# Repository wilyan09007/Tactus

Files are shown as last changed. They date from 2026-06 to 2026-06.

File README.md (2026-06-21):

# 🎸 Tactus

**A Deaf-accessible guitar-coaching wearable.** From a webcam + a mic, Tactus recovers *what you played, where, with which finger, and how cleanly you fretted it* — by fusing vision and audio through a learned physical model — then gives you **one precise correction you feel on your body and see on your hand.**

> Built for the **UC Berkeley AI Hackathon 2026 (June 20–22)**. Team of 4. Working name **Tactus** (*touch* + the conductor's *pulse*).
>
> 📌 **Canonical source of truth: [`truth.md`](truth.md).** If any doc disagrees with it, `truth.md` wins.

---

## The 30-second version
- **Problem.** Learning guitar is a hear-and-correct loop: play → hear the buzz / wrong note → fix. Deaf and hard-of-hearing players are locked out of that loop (~466M people have disabling hearing loss, WHO).
- **Tactus — two modes on one engine:**
  - **LEARN** — "Rocksmith for Deaf players." Feel the target song on your body, play it on a real guitar, and on any mistake the system rewinds, replays the correct haptics vs. yours, and shows the physical fix — Claude vision highlights the wrong finger.
  - **PLAY** — pick up the guitar and get real-time "flat / sharp / in tune / on the beat" by feel.
- **Where the AI is.** The hard, unsolved part is reading an *occluded* fretting hand and a *cause-blind* buzz from a webcam + mic. The ML lives exactly there; everything downstream is a deterministic, measurable signal→vibration transform (no AI-invented "score"). That split is the rigor.
- **The one correction.** Three axes: **wrong note · wrong duration · pressure** (too-light vs good; "too hard" surfaces as a sharp/choked pitch fault). Each is a measured signal, cross-checked across vision + audio.

## The rig (as-built — full detail in [`truth.md`](truth.md))
```
LAPTOP (M4 Pro) ──USB──► 2× Vantec NBA-200U (USB→8 ch; V3 spare)
                            └► 6× SK473 PAM8403 stereo amp boards (gutted)
                                 └► 12× KHD 3 Ω/5 W drivers (de-housed) on the body
                                      = 12 channels: 6 back (strings) + 6 torso (fret-zones)
```
- **Software split (locked):** the **browser** owns camera + MediaPipe + ArUco + AR + viz; a **Python** process owns mic + F0 + the fusion model + 12-ch haptic output; they sync over one localhost WebSocket (vision features flow browser→Python, timestamped).
- **Power:** wall (10-port hub) for the judged run, or cordless (Anker 737). Only ~2–3 channels fire at once (sequential strum sweep), so real peak is ~2–3 W.

## Docs map
| Doc | What's in it |
|---|---|
| **[`truth.md`](truth.md)** | ⭐ The canonical source of truth — direction + all hardware (parts, dimensions, cost, use) |
| [`docs/00-start-here.md`](docs/00-start-here.md) | On-ramp + build-tonight TL;DR |
| [`docs/01-bill-of-materials.md`](docs/01-bill-of-materials.md) | The as-purchased BOM (SKUs, qty, spares) |
| [`docs/02-system-architecture.md`](docs/02-system-architecture.md) · [`03-power.md`](docs/03-power.md) | System chain + the chord-safety power math |
| [`docs/04-soldering-guide.md`](docs/04-soldering-guide.md) · [`05-wiring-map.md`](docs/05-wiring-map.md) · [`06-safety.md`](docs/06-safety.md) · [`09-assembly-checklist.md`](docs/09-assembly-checklist.md) | Build: solder order, channel-by-channel wiring, safety, assembly gates |
| [`docs/07-haptic-encoding.md`](docs/07-haptic-encoding.md) · [`18-tuning-and-calibration.md`](docs/18-tuning-and-calibration.md) · [`21-chord-and-sustain-rendering.md`](docs/21-chord-and-sustain-rendering.md) | How notes / chords / sustain become vibration + on-body tuning |
| [`docs/08-software-architecture.md`](docs/08-software-architecture.md) · [`13_LEARN_WEB_AND_VISUALIZATION.md`](docs/13_LEARN_WEB_AND_VISUALIZATION.md) | The engine + the browser↔engine WebSocket contract |
| [`docs/17-ai-rigor.md`](docs/17-ai-rigor.md) · [`20-aiml-training-design.md`](docs/20-aiml-training-design.md) · [`20-eng-review.md`](docs/20-eng-review.md) · [`23-data-and-cluster-semantics.md`](docs/23-data-and-cluster-semantics.md) | The AI core: fusion, the buzz inverse, the separability study, data + training |
| [`docs/22-interface-ar-and-correction.md`](docs/22-interface-ar-and-correction.md) | The interface: live AR play + the 2D correction view |
| [`docs/10-design-decisions.md`](docs/10-design-decisions.md) · [`11-ai-and-pitch.md`](docs/11-ai-and-pitch.md) · [`12-perception-references.md`](docs/12-perception-references.md) · [`13-open-questions.md`](docs/13-open-questions.md) · [`15-build-refinements.md`](docs/15-build-refinements.md) | Decisions, perception science, open items, the as-built teardown log |
| [`docs/19-sponsors-refined.md`](docs/19-sponsors-refined.md) | Sponsor / prize alignment |
| `docs/REF_*.md` (ml · psychophysics · sponsors) | Cited research briefs (background) |
| [`cad/`](cad/) | Printable enclosure + actuator coupling pucks (FlashForge 5M) |
| [`config/channel_map.json`](config/channel_map.json) | Machine-readable 12-channel routing (wiring source of truth) |
| [`CHANGELOG.md`](CHANGELOG.md) | Chronological history (incl. the pre-pivot era) |

---
*Pivoted from an earlier multi-pillar "music for the Deaf" concept. The abandoned Pi / ESP32 / 16-channel / 3-pillar docs were removed from this repo (recoverable from git history). The current product is **LEARN + PLAY guitar coaching** — see [`truth.md`](truth.md).*

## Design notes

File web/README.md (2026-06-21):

# Tactus — web

The **product UI** is **[`glow.html`](glow.html)** — the live fret-glow LEARN
interface. `index.html` just redirects to it, so opening `/` opens the real thing.

## Run

```bash
cd web
python3 -m http.server 8000
# open http://localhost:8000/   (redirects to glow.html)
```

Allow the camera, then **calibrate**: drag the 4 corner handles onto your real
fretboard. The glow markers then sit on the real strings/frets.

## What glow.html is

The canonical LEARN view. Notes are annotated **on the real neck** over the
webcam — no synth, render-only (right for a Deaf-focused app).

- **Per-string 6-hue palette** (CVD-aware) — each string is its own colour;
  nut labels back it up for accessibility.
- **ADSR brightness envelope** — a marker washes in pale when far, deepens to
  full saturation at the strum, then releases. Approach-frame shrinks to meet
  the marker = strum now; pop burst on the beat.
- **4-corner bilinear neck grid** — draggable handles map the grid to your neck
  (equal-temperament fret spacing, `2^(-n/12)`).
- **alphaTab real tab** on the left — actual notation/tab rendered from one
  `SONG` source that also builds the glow chart, so left and right are the same
  song, locked to one master clock. CDN-blocked → falls back to a chord-row list.

## Helpers (prepared, not yet wired)

- `alphatab-loader.js` — parse a GuitarPro/MusicXML file → Tactus chart, headless
  (no DOM/synth). For driving glow from real song files.
- `aruco-poselock.js` — js-aruco2 marker pose-lock to **auto**-align the neck grid
  (drops the manual 4-corner calibration). The next AR layer.

## `_prototypes/`

Earlier exploration UIs, **kept for reference only — not the product**:
`learn-dashboard-mock.html` (the old black 14-channel body-map mock),
`beatsaber.html` (notes-fly-in highway), `ar.html` (chord-field depth view).
Do not build on these — glow.html is the one.

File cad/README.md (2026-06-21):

# CAD — the printed enclosure + body-coupling pucks (FlashForge Adventurer 5M)

Everything printed for the **12-channel, no-solder** rig in [`truth.md`](../truth.md) (canonical). One **enclosure** that houses the audio source + amp boards + power, and the **coupling pucks** that turn each de-housed **Ø52 mm SK473 KHD driver** into a body tactor.

> ⚙️ **Render note:** the installed **OpenSCAD is x86 and will not run on this arm64 Mac** (no Rosetta). So the print-ready parts are generated **headless with manifold3d** (the exact-boolean kernel modern OpenSCAD uses) via Python — no GUI. The `.scad` files remain the human-readable sources; the OpenSCAD-only parts (§ "Reference parts") need an OpenSCAD machine to re-render.

---

## ★ PRINT THIS — the verified print-ready set

All four are **single watertight bodies, no supports, fit the 220³ bed.** Drop the STLs straight into the slicer.

| File | Size (mm) | Qty | Orient | Material | Time |
|---|---|---|---|---|---|
| **`tactus_enclosure_plate.stl`** — base + lid, **ONE print** | base 175×97×63, lid 175×97×8 (plate 175×202) | 1 | as-exported, support-free | PETG | ~7–10 h |
| `actuator_cup.stl` (Ø52 driver) | 75.4 × 57.4 × 30.4 | ~14 | open-side up | PETG/TPU | ~14 min |
| `actuator_button.stl` | 14 × 14 × 9 | ~14 | flat-side down | PETG/TPU | ~6 min |

Common: 0.2 mm layer · 3 walls · 4 top/bottom · 15–20 % gyroid · **supports NONE** · brim 5 mm (enclosure) / skirt (pucks) · PETG 235/80 °C.

**The new box** — rounded, one compartment, **TACTUS** engraved big + bold (Arial Black) on the lid; base + lid print side-by-side as one plate:
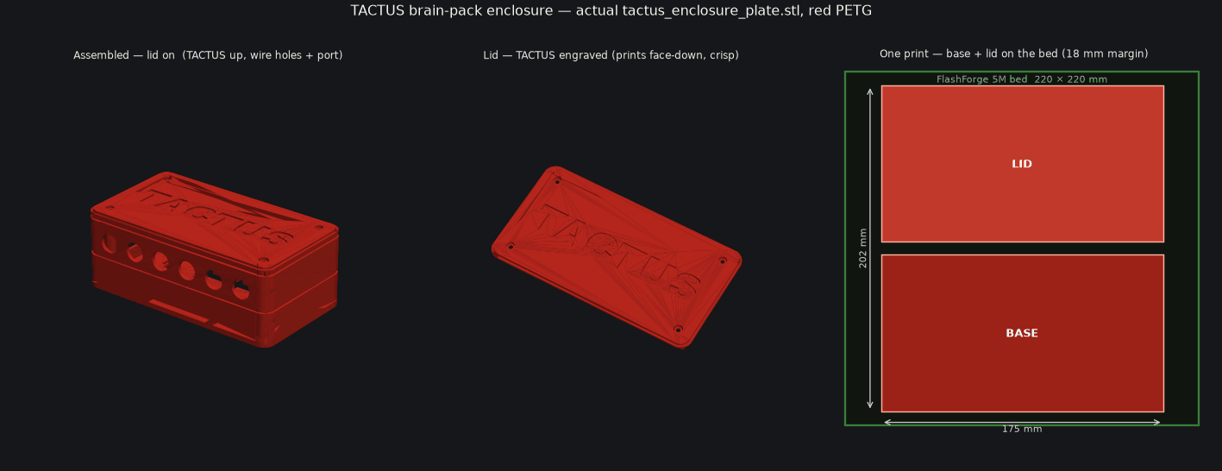
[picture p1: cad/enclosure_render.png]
TACTUS enclosure — assembled box + lid, red PETG


### What lives inside (per truth.md §3 — laptop is the brain, no Pi)
| Bay | Holds |
|---|---|
| One compartment (lidded) | **2× Vantec NBA-200U** (100×58×26; the 6 SK473 **audio jacks** plug in here) + **1× 10-port hub** (the 6 SK473 **USB** leads + 2 Vantec data leads plug in here). **No Pi, no ESP32, no boards** — the SK473 amp+driver units are on the **vest**; their 12 cables enter the wall holes. |
| Power | **Mode A** = the 10-port hub (in the box). **Mode B** = **Anker 737** (155.7×54.6×49.5) — has its own plug, so it velcros **outside** the box / on the belt. |

> **Why this enclosure (not `tactus_box`):** truth.md names `tactus_box` for the enclosure, but its pre-rendered STL is **non-watertight (8 disconnected chunks)** and **can't be re-rendered here** (OpenSCAD won't run). `tactus_enclosure` is the **manifold3d** equivalent — same contents, **verified watertight single body**, integrated power bay (so no separate `tactus_power_cradle`), re-renders headless. Use it for the print.

---

## Render → STL (headless, no OpenSCAD)
```bash
/tmp/tactuscad/bin/python cad/tactus_enclosure.py   # → _base.stl, _lid.stl, and _plate.stl (the ONE-print file) + bed-fit assert
/tmp/tactuscad/bin/python cad/_puck_render.py       # → actuator_cup.stl + actuator_button.stl (at spk_dia=52)
```
The venv `/tmp/tactuscad` has `trimesh` + `manifold3d`. `tactus_enclosure.py` **errors out if any feature would print disconnected** — a single watertight body is guaranteed or the build fails.

## ⚠️ The one open dimension — the driver Ø
- **Ø52 mm is web-verified** (OEM Havit HV-SK473, literal "Φ52 mm*2" from two independent retailers; zero dissenting sources). The puck bore is **Ø52.6** (52 + 0.6 fit gap) and `spk_dia=52` is set across `actuator_puck.scad`, `tactus_node_mount.scad`, `tactus_chest_plate.scad`.
- **Caliper the physical driver before the full run** (truth.md §8 #1): published "52 mm" is the nominal *frame* OD (what the cup grips), but no source separates cone vs frame, and driver *depth* / magnet Ø are unpublished (puck uses a generous `spk_depth=27`). **Print one cup, drop the driver in, confirm the grip, then batch the rest.**

## Reference parts (OpenSCAD-only — need an OpenSCAD machine to re-render)
- `tactus_box.scad` / `tactus_power_cradle.scad` — truth.md's original split enclosure. Superseded for printing by `tactus_enclosure` (above). Their STLs are non-watertight; don't print them.
- `tactus_node_mount.scad` + `tactus_socket.scad` / `tactus_chest_plate.scad` — the **adjustable** body-mount alternative to the puck (split-clamp collar + depth micro-adjust). `drv_dia` is set to the verified **52 mm**; the pre-rendered STLs are still at the old 58 mm placeholder — **re-render in OpenSCAD** before printing these. The `actuator_puck` (above) is the working coupler if you don't need the adjustable mount.

## Slicing (FlashForge Adventurer 5M — open-frame, web-confirmed)
PETG for the enclosure (heat tolerance near the warm boards + bank; tougher bosses); PLA fine for a fast start. Pucks: PETG or TPU (TPU = softer skin contact). 0.2 mm · 3 walls · 4 top/bottom · 15–20 % gyroid · **no supports** · brim 5 mm on the base. Queue base / lid / a tray of pucks across printers — all hands-off.

## Assembly (no soldering — truth.md §3, docs/09)
1. Self-tap the 4 lid bosses with the M3 screw (PETG self-taps).
2. Lash the **2 Vantec + 6 SK473 boards** to the floor zip-tie grid over foam. Each board: 3.5 mm plug → a Vantec jack; USB-A → the hub.
3. De-house each Ø52 mm driver (leads stay on the board — no solder), seat in a cup, glue a button to the dust cap, run the lead out the comb; strain-relieve both ends.
4. Drop the Anker/hub into the open back bay → velcro through the floor strap slots → screen out the back.
5. Lid on, 4× M3. *(Optional wear: waistband through the 2 floor belt slots, or zip-tie via the 4 corner lash holes.)*

## ArUco marker (vision) — OPTIONAL validation rig only
Registration is **markerless** (the 12-TET fret-law homography, `software/ai/vision/fretboard.py` — see `truth.md §3.8`, `docs/25`); **you do not need a marker to record or to run the pipeline.** The marker is kept only as an OPTIONAL offline ground-truth validator. If you do print one: generate it with `python3 cad/aruco/generate_marker.py` (produces `cad/aruco/marker_4x4_50_id0.png` + a print-at-100% sheet, 4×4_50 id 0), keep it **dead flat (never folded)**, and tape it **coplanar with the fretboard near the nut/neck — NOT the angled headstock** (the headstock tilts ~15° off the fretboard plane → a worse homography).

## Parameters you'll most likely touch
- `tactus_enclosure.py`: `IX` / `IY` / `IZ` (compartment size), `PLATE_GAP` (base↔lid spacing on the one-print bed).
- `actuator_puck.scad` (+ `_puck_render.py`): `spk_dia`, `spk_depth` (your measured driver), `btn_dome_h` (skin poke).
- `tactus_node_mount.scad` / `tactus_chest_plate.scad`: `drv_dia` / `drv_depth`, `torso_r`.

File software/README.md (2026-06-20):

# software

Two halves, both on the laptop. See [../docs/08-software-architecture.md](../docs/08-software-architecture.md).

```
software/
  ai/       transcription (basic-pitch), vision (mediapipe + ArUco), fusion, LLM coach
  haptic/   encoder (note -> channel), synth (pulse), alsa_out (multichannel write)
```

## Bring-up order
1. `aplay -l` → note the 3 Vantec card indices; fill `card_alsa` in [../config/channel_map.json](../config/channel_map.json).
2. `speaker-test -c8 -Dhw:CARD,0` on each Vantec → confirm all 8 channels reach the 4 jacks.
3. `haptic/` smoke test: play a known (string, fret) → correct body site buzzes.
4. `ai/` smoke test: webcam + mic → transcription + fretboard overlay.
5. Wire the coach loop on one phrase.

## Install
```
python -m venv .venv && source .venv/bin/activate
pip install -r requirements.txt
```

Real-time note: `basic-pitch` is near-real-time per phrase, not per-note. For live coaching use a known target song (compare against its reference) — see the "any song" section in the architecture doc.

## What to build first (MVP slices)
Build in this order for the fastest working demo — full reasoning + track alignment in [../docs/11-ai-and-pitch.md](../docs/11-ai-and-pitch.md):
1. mono note detection (audio) + MediaPipe overlay + correct/incorrect
2. haptic render of the note on the body + rule-based "wrong note / too quiet"
3. LLM phrase-level coaching
4. then: chords/polyphony, audio↔vision cross-check, buzz→"press harder", placement color

Honest-scoping rules (don't over-claim): placement is **vs the fret-wire (coarse)**, pressure is **adequacy from timbre** (no sensor), polyphony degrades on dense playing. See [../docs/13-open-questions.md](../docs/13-open-questions.md) for known limitations.

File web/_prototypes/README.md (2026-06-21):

# Archived prototypes — NOT the product UI

These are earlier exploration passes, kept only for reference. **The real Tactus
LEARN interface is [`../glow.html`](../glow.html)** (open `/` → it redirects there).
Do not build on or ship these.

| File | What it was | Why archived |
|---|---|---|
| `learn-dashboard-mock.html` | Black 14-channel dashboard: top-bar pills, body-map (6 chest + 6 forearm), note highway, 3-fix correction panel. Runnable mock of the WebSocket `frame`/`note`/`error`/`reference` contract (docs/16). | Uniform-blue strings, no AR-on-real-neck. Superseded by glow.html. |
| `beatsaber.html` | three.js Beat-Saber highway — note blades fly down the string lanes toward a "now" bar, composited over the webcam. | Single-hue (gold), depth-approach not on-the-real-neck. Concept lives in docs/22. |
| `ar.html` | Chord-field — fretboard faces the camera, blades light up in the chord shape, depth = hold length. | Single-hue, face-on grid. Exploration only. |

What made glow.html win: **per-string colour + on-the-real-neck annotation +
silent render-only alphaTab tab**, all on the live camera. See `../README.md`.

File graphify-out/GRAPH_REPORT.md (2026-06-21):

# Graph Report - tactus  (2026-06-21)

## Corpus Check
- 68 files · ~105,469 words
- Verdict: corpus is large enough that graph structure adds value.

## Summary
- 1060 nodes · 1481 edges · 93 communities (90 shown, 3 thin omitted)
- Extraction: 94% EXTRACTED · 6% INFERRED · 0% AMBIGUOUS · INFERRED: 82 edges (avg confidence: 0.83)
- Token cost: 0 input · 0 output

## Graph Freshness
- Built from commit: `01b1d406`
- Run `git rev-parse HEAD` and compare to check if the graph is stale.
- Run `graphify update .` after code changes (no API cost).

## Community Hubs (Navigation)
- [[_COMMUNITY_AI Audit Report Generator|AI Audit Report Generator]]
- [[_COMMUNITY_SpeakerActuator Check Harness|Speaker/Actuator Check Harness]]
- [[_COMMUNITY_Fretboard Vision Registration|Fretboard Vision Registration]]
- [[_COMMUNITY_Audio Feature Extraction|Audio Feature Extraction]]
- [[_COMMUNITY_AI Rigor & Perception Docs|AI Rigor & Perception Docs]]
- [[_COMMUNITY_Rendering & Sponsor Briefs|Rendering & Sponsor Briefs]]
- [[_COMMUNITY_Feature Collapse  Fisher Analysis|Feature Collapse / Fisher Analysis]]
- [[_COMMUNITY_Event Segmentation|Event Segmentation]]
- [[_COMMUNITY_Vision Feature Extraction|Vision Feature Extraction]]
- [[_COMMUNITY_Channel Map & Body Diagrams|Channel Map & Body Diagrams]]
- [[_COMMUNITY_Enclosure CAD Model|Enclosure CAD Model]]
- [[_COMMUNITY_Learn Loop & Correction Engine|Learn Loop & Correction Engine]]
- [[_COMMUNITY_Data & Feature Contracts|Data & Feature Contracts]]
- [[_COMMUNITY_Pipeline Schema Helpers|Pipeline Schema Helpers]]
- [[_COMMUNITY_AR Play & Calibration UI|AR Play & Calibration UI]]
- [[_COMMUNITY_Actuator Hardware & Coupling|Actuator Hardware & Coupling]]
- [[_COMMUNITY_Channel Map Config|Channel Map Config]]
- [[_COMMUNITY_AmpBOM & Safety Hardware|Amp/BOM & Safety Hardware]]
- [[_COMMUNITY_Buzz-Inverse & Experiment Plan|Buzz-Inverse & Experiment Plan]]
- [[_COMMUNITY_Enclosure Render (Preview)|Enclosure Render (Preview)]]
- [[_COMMUNITY_Brain-Pack Enclosure Print|Brain-Pack Enclosure Print]]
- [[_COMMUNITY_Capture HTTP Server|Capture HTTP Server]]
- [[_COMMUNITY_Capture Web App|Capture Web App]]
- [[_COMMUNITY_Puck Coupler CAD|Puck Coupler CAD]]
- [[_COMMUNITY_Training Design & Semantics|Training Design & Semantics]]
- [[_COMMUNITY_MLDSP Methods Brief|ML/DSP Methods Brief]]
- [[_COMMUNITY_Canonical Docs (truth.md)|Canonical Docs (truth.md)]]
- [[_COMMUNITY_Power Budget & Modes|Power Budget & Modes]]
- [[_COMMUNITY_Calibration HTTP Server|Calibration HTTP Server]]
- [[_COMMUNITY_Data Collection Protocol|Data Collection Protocol]]
- [[_COMMUNITY_Project History & Haptic Render|Project History & Haptic Render]]
- [[_COMMUNITY_Engine Pipeline (Fusion)|Engine Pipeline (Fusion)]]
- [[_COMMUNITY_Demo Data Generator|Demo Data Generator]]
- [[_COMMUNITY_ArUco Pose-Lock Filter|ArUco Pose-Lock Filter]]
- [[_COMMUNITY_Separability & Cluster Viz|Separability & Cluster Viz]]
- [[_COMMUNITY_Audit Tests|Audit Tests]]
- [[_COMMUNITY_Audio Feature Tests|Audio Feature Tests]]
- [[_COMMUNITY_Vision Feature Tests|Vision Feature Tests]]
- [[_COMMUNITY_Segmentation Tests|Segmentation Tests]]
- [[_COMMUNITY_AR Prototypes (Beat-Saber)|AR Prototypes (Beat-Saber)]]
- [[_COMMUNITY_Correction Interface & Posterior|Correction Interface & Posterior]]
- [[_COMMUNITY_Pipeline Runner|Pipeline Runner]]
- [[_COMMUNITY_Collapse Tests|Collapse Tests]]
- [[_COMMUNITY_End-to-End Pipeline Test|End-to-End Pipeline Test]]
- [[_COMMUNITY_Record Conductor CLI|Record Conductor CLI]]
- [[_COMMUNITY_AlphaTab Chart Loader|AlphaTab Chart Loader]]
- [[_COMMUNITY_ArUco Marker Asset|ArUco Marker Asset]]
- [[_COMMUNITY_Channel-Count Drift Note|Channel-Count Drift Note]]
- [[_COMMUNITY_Community 51|Community 51]]
- [[_COMMUNITY_Community 52|Community 52]]
- [[_COMMUNITY_Community 53|Community 53]]
- [[_COMMUNITY_Community 54|Community 54]]
- [[_COMMUNITY_Community 55|Community 55]]
- [[_COMMUNITY_Community 56|Community 56]]
- [[_COMMUNITY_Community 57|Community 57]]
- [[_COMMUNITY_Community 58|Community 58]]
- [[_COMMUNITY_Community 59|Community 59]]
- [[_COMMUNITY_Community 60|Community 60]]
- [[_COMMUNITY_Community 61|Community 61]]
- [[_COMMUNITY_Community 62|Community 62]]
- [[_COMMUNITY_Community 63|Community 63]]
- [[_COMMUNITY_Community 64|Community 64]]
- [[_COMMUNITY_Community 65|Community 65]]
- [[_COMMUNITY_Community 66|Community 66]]
- [[_COMMUNITY_Community 67|Community 67]]
- [[_COMMUNITY_Community 68|Community 68]]
- [[_COMMUNITY_Community 69|Community 69]]
- [[_COMMUNITY_Community 70|Community 70]]
- [[_COMMUNITY_Community 71|Community 71]]
- [[_COMMUNITY_Community 72|Community 72]]
- [[_COMMUNITY_Community 73|Community 73]]
- [[_COMMUNITY_Community 74|Community 74]]
- [[_COMMUNITY_Community 75|Community 75]]
- [[_COMMUNITY_Community 76|Community 76]]
- [[_COMMUNITY_Community 77|Community 77]]
- [[_COMMUNITY_Community 78|Community 78]]
- [[_COMMUNITY_Community 79|Community 79]]
- [[_COMMUNITY_Community 80|Community 80]]
- [[_COMMUNITY_Community 81|Community 81]]
- [[_COMMUNITY_Community 82|Community 82]]
- [[_COMMUNITY_Community 83|Community 83]]
- [[_COMMUNITY_Community 84|Community 84]]
- [[_COMMUNITY_Community 86|Community 86]]
- [[_COMMUNITY_Community 87|Community 87]]
- [[_COMMUNITY_Community 88|Community 88]]
- [[_COMMUNITY_Community 89|Community 89]]
- [[_COMMUNITY_Community 90|Community 90]]
- [[_COMMUNITY_Community 91|Community 91]]
- [[_COMMUNITY_Community 92|Community 92]]

## God Nodes (most connected - your core abstractions)
1. `truth.md — Tactus single source of truth` - 20 edges
2. `Data Collection & Labeling Protocol` - 16 edges
3. `run()` - 14 edges
4. `main()` - 14 edges
5. `15 — Build refinements + the kinks that will bite (read before Saturday)` - 14 edges
6. `24 — Data collection & labeling protocol (execute this to feed the AIML pipeline)` - 14 edges
7. `20 — AIML training design: multimodal guitar-technique coaching (comprehensive spec)` - 13 edges
8. `_section_separability()` - 12 edges
9. `_extract_one()` - 12 edges
10. `Changelog — Tactus` - 12 edges

## Surprising Connections (you probably didn't know these)
- `Laptop AI Brain (transcribe/fuse/coach/AR)` --conceptually_related_to--> `Bayesian Position Posterior with theory prior`  [INFERRED]
  diagrams/system-flow.svg → docs/20-aiml-training-design.md
- `Component A — Haptic Reference (what it should feel like)` --semantically_similar_to--> `Train/serve match (same mic + camera for training and inference)`  [INFERRED] [semantically similar]
  docs/13_LEARN_WEB_AND_VISUALIZATION.md → truth.md
- `Live AR Play View (Beat-Saber depth-approach)` --semantically_similar_to--> `Live Fret-Glow Annotation (glow.html)`  [INFERRED] [semantically similar]
  docs/22-interface-ar-and-correction.md → web/glow.html
- `Scope Lock — Frets 1-6 only (6 fret-zone motors, 1:1)` --rationale_for--> `6 Fret-Zone Channels on Torso (ch 7-12)`  [INFERRED]
  docs/24-data-collection-protocol.md → diagrams/body-map.svg
- `Bring-up Order (Vantec → speaker-test → haptic → ai)` --conceptually_related_to--> `Vantec → SK473 → 12 Drivers Chain`  [INFERRED]
  software/README.md → diagrams/system-flow.svg

## Import Cycles
- None detected.

## Hyperedges (group relationships)
- **AR guitar-coaching interface prototypes** — web_ar_chord_field_ar, web_beatsaber_beat_saber_highway, web_glow_fret_glow_annotation [INFERRED 0.85]
- **Cross-modal fusion perception (audio + vision -> position + quality)** — docs_08_audio_branch, docs_08_vision_branch, docs_08_fusion, truth_aiml_perception_model, docs_17_disagreement_as_signal [EXTRACTED 0.90]
- **As-built audio-out chain (laptop -> Vantec -> SK473 -> KHD)** — truth_macbook_m4_pro, truth_vantec_nba200u, truth_sk473_pam8403, truth_khd_driver [EXTRACTED 0.95]
- **LEARN closed loop (feel target -> haptic reference + VLM + correction engine)** — docs_13_learning_loop, docs_13_haptic_reference, docs_13_feel_the_difference, docs_13_vlm_coach, docs_13_physical_correction_engine [EXTRACTED 0.90]
- **Offline Separability Pipeline (capture→sync→segment→features→LDA→d')** — 24_data_collection_protocol_collection_protocol, 25_data_and_feature_format_processing_contract, 26_aiden_handoff_offline_pipeline_stages, 25_data_and_feature_format_av_sync_recovery, 25_data_and_feature_format_mahalanobis_dprime [EXTRACTED 0.85]
- **Buzz-Inverse Identifiability (B from P,d with pluck proxy)** — 20_aiml_training_design_buzz_inverse, 20_aiml_training_design_fingertip_wire_distance, 20_eng_review_pluck_proxy, 20_eng_review_two_class_pressure [EXTRACTED 0.85]
- **As-Built 12-Channel Render Chain (laptop→Vantec→SK473→drivers→body)** — diagrams_system_flow_render_chain, diagrams_system_flow_vantec_sk473_drivers, diagrams_body_map_body_map, diagrams_power_modes_power_modes, diagrams_connections_connections [INFERRED 0.85]

## Communities (93 total, 3 thin omitted)

### Community 0 - "AI Audit Report Generator"
Cohesion: 0.08
Nodes (57): _amber_ramp(), _assemble_html(), _build_recommendations(), _card(), _coerce_float(), _confusion_from_block(), _confusion_png(), _coverage_counts() (+49 more)

### Community 1 - "Speaker/Actuator Check Harness"
Cohesion: 0.11
Nodes (37): getkey(), main(), make_glide(), Read ONE keypress, no Enter required, returned lowercased.      Enter comes back, A linear-frequency chirp f0 -> f1 over `dur` s. Driving through the band     mak, ask(), channel_label(), diagnose() (+29 more)

### Community 2 - "Fretboard Vision Registration"
Cohesion: 0.10
Nodes (35): board_grid(), aggregate_frames(), autodetect(), detect_frets(), detect_neck_edges(), fit_law(), _gray(), overlay() (+27 more)

### Community 3 - "Audio Feature Extraction"
Cohesion: 0.09
Nodes (30): _chroma(), _extract_one(), _f0_features(), _flux(), _hnr(), _inharmonicity(), main(), _mfcc() (+22 more)

### Community 4 - "AI Rigor & Perception Docs"
Cohesion: 0.19
Nodes (14): Funneling separation rule (separate simultaneous cues), docs/07-haptic-encoding.md (note -> actuator encoding), Location+timing pitch code (not vibration frequency), Pulse shape (160 Hz, 50 ms, 3 intensity levels), Amp choice: gut SK473/PAM8403 (reject car amp/DigiAMP+/MAX98357A), docs/10-design-decisions.md (why, and what was rejected), Model Human Cochlea precedent (frequency bands across torso), Neosensory Buzz precedent (Eagleman, 4 wrist actuators) (+6 more)

### Community 5 - "Rendering & Sponsor Briefs"
Cohesion: 0.09
Nodes (24): Accessibility / Ddoski's World (sensory substitution), One Coherent Sponsor Story (critical-path pipeline), QNX Dropped (Pi cut), Sponsor & Prize Alignment (as-built rig), Anthropic Prize — Claude vision as coaching brain, Most Technical — fusion + buzz inverse + separability, Chord, Sustain & Percussive Rendering, Sustain = Envelope-Modulated Looped Shimmer (re-trigger) (+16 more)

### Community 6 - "Feature Collapse / Fisher Analysis"
Cohesion: 0.16
Nodes (20): _dprime(), _f(), _fisher_per_axis(), _fit_fold(), _jsonify(), _kfold_folds(), _lopo_folds(), main() (+12 more)

### Community 7 - "Event Segmentation"
Cohesion: 0.16
Nodes (20): _as_int(), _detect_onsets(), _empty_frame(), _events_for_row(), _f0_median_hz(), _get(), _load_audio(), main() (+12 more)

### Community 8 - "Vision Feature Extraction"
Cohesion: 0.15
Nodes (19): _angle_at(), _default_provider(), _event_features(), _load_active_keyframe(), main(), _nearest_fret(), _pose_angles(), Board Y (0..1, 0 = low-E) -> string name 6..1 (low-E=6 .. high-e=1).     schema. (+11 more)

### Community 9 - "Channel Map & Body Diagrams"
Cohesion: 0.13
Nodes (20): Scope Lock — Frets 1-6 only (6 fret-zone motors, 1:1), Body Map Diagram (12 channels), 6 Fret-Zone Channels on Torso (ch 7-12), 6 String Channels on Back (ch 1-6), Connections Diagram (no soldering), NEVER Connect rules (safety), Mode A — Wall (10-port powered hub), Mode B — Cordless (Anker 737 battery) (+12 more)

### Community 10 - "Enclosure CAD Model"
Cohesion: 0.25
Nodes (17): box_at(), build_base(), build_lid(), cleanup(), cyl(), D(), main(), make_text() (+9 more)

### Community 11 - "Learn Loop & Correction Engine"
Cohesion: 0.22
Nodes (9): The learning loop (feel target -> play -> rewind -> fix), WebSocket JSON contract (frame/error-event/reference schema), Honesty discipline (new sensory channel, ordinal pressure), LEARN mode (coach a target song), Localhost WebSocket (browser<->Python sync), Locked software architecture (browser vision + Python audio over WebSocket), PLAY mode (real-time tuning feedback), Tactus (Deaf-accessible guitar-coaching wearable) (+1 more)

### Community 12 - "Data & Feature Contracts"
Cohesion: 0.24
Nodes (10): Contrastive Multimodal Embedding (cut-first stretch), Prompted, Dual-Witnessed Labeling (prompt is the label), Separability Study (LDA/PCA, Fisher ratio, d'), AIML Training Design (multimodal coaching spec), Leave-One-Player-Out Cross-Validation, The Run is the Correlated CV Unit (grouped CV), Data Handoff for Offline Pipeline (Aiden), Iron Rules (violating invalidates the result) (+2 more)

### Community 13 - "Pipeline Schema Helpers"
Cohesion: 0.13
Nodes (14): abspath(), f0_to_string_fret(), hz_to_midi(), iter_session_player(), on_path(), out_dir(), Yield (session_id, player_id, dir) for every <session>/<player> under `base`., data/analysis/<session>/<player>/, created if missing. (+6 more)

### Community 14 - "AR Play & Calibration UI"
Cohesion: 0.19
Nodes (13): Live AR Play View (Beat-Saber depth-approach), ArUco Pose-Lock Registration (web/aruco-poselock.js), Virtual Neck Fallback (demo insurance), Align Mode (train≈serve by construction), Guitar Digital-Twin Calibrate UI (calibrate.html), 12-TET Fret-Law Grid (fretFrac 2^-n/12), 4-Point Homography DLT solver (solveH/gauss/proj), Pose Plan (6 keyframes per guitar) (+5 more)

### Community 15 - "Actuator Hardware & Coupling"
Cohesion: 0.21
Nodes (13): docs/00-start-here.md (on-ramp + build TL;DR), docs/01-bill-of-materials.md (as-purchased BOM), docs/02-system-architecture.md (sense->understand->render chain), docs/13-open-questions.md (unconfirmed/unbought items), ALSA enumeration trap (CM6206 cards reorder), As-built rig (laptop -> 2x Vantec -> 6x SK473 -> 12x KHD drivers), BTL isolation rule (every actuator gets own 2-wire pair), 12-channel map (6 back strings + 6 torso fret-zones) (+5 more)

### Community 16 - "Channel Map Config"
Cohesion: 0.15
Nodes (12): channels, _comment, intensity_levels, pulse, duration_ms, freq_hz, _note, spare (+4 more)

### Community 17 - "Amp/BOM & Safety Hardware"
Cohesion: 0.28
Nodes (9): docs/04-soldering-guide.md (gut SK473, attach actuators, build bus), Strain-relief (heat-shrink + hot-glue blob, both ends), Tone-test before glue (verify each amp individually), docs/05-wiring-map.md (channel-by-channel wiring), Bounded isolation (isolated 5V rail, shared signal ground), docs/06-safety.md (electrical + mechanical risk elimination), Wire-weight problem (18 AWG levers/tears joints), docs/09-assembly-checklist.md (staged bring-up gates) (+1 more)

### Community 18 - "Buzz-Inverse & Experiment Plan"
Cohesion: 0.21
Nodes (13): AI only where the problem is unsolved, Buzz Inverse Problem (B = f(P, d), invert to recover P), Fingertip-to-wire distance d (key engineered feature), Live 3D Cluster Viz (WebGL centerpiece), Occlusion Pose-to-Placement Model (audio as free teacher), 2-Class Pressure (too-light vs good) (D5), Two Last Miles (occluded pose + buzz cause), 3D Semantic Viz (rotating PCA→LDA, named axes) (+5 more)

### Community 19 - "Enclosure Render (Preview)"
Cohesion: 0.24
Nodes (11): Enclosure Base (Lower Shell), Corner Screw Mount Bosses, Tactus Two-Part Enclosure, Internal PCB Standoffs / Mounting Ribs, Enclosure Lid (Top Cover), Port Window Cutout, Enclosure Protects/Houses Tactus Electronics, Tactus Enclosure CAD Preview Render (+3 more)

### Community 20 - "Brain-Pack Enclosure Print"
Cohesion: 0.25
Nodes (11): Enclosure Base (box body), Tactus Brain-Pack Electronics (housed hardware), TACTUS Brain-Pack Enclosure (tactus_enclosure_plate.stl), TACTUS Engraved Logo (lid), FlashForge 5M Bed 220x220mm, Enclosure Lid (TACTUS engraved, prints face-down), Red PETG Filament, Cable/Connector Port (+3 more)

### Community 21 - "Capture HTTP Server"
Cohesion: 0.29
Nodes (3): Handler, Aggregate a session's manifest so the page can cross-check what's on disk., safe()

### Community 22 - "Capture Web App"
Cohesion: 0.14
Nodes (18): Localhost Capture App (serve.py), Metadata Schema (one row per run), Offline A/V Sync Recovery (WAV↔webm cross-correlate), Beat-Anchored + F0 Segmentation, Capture Wide, Process Cropped (homography ROI crop), Pitch Control via Covariates (not per-cell z-score), WAV-only for the Buzz Study (Opus mangles buzz band), Matched-Modality Ablation (same events, mask vision) (+10 more)

### Community 23 - "Puck Coupler CAD"
Cohesion: 0.40
Nodes (9): box(), button(), cup(), cyly(), cylz(), D(), main(), # NOTE: the .scad's rim_lip subtraction is a geometric no-op (it lies inside (+1 more)

### Community 24 - "Training Design & Semantics"
Cohesion: 0.31
Nodes (9): Breadth vs Depth Data Collection Split, Eng Review of AIML Training Design, Pluck/Attack-Energy Proxy Feature (D1), Causal Clean/Fault Pair (proves the fix), Data, Representation & Eigenvector-to-Advice Semantics, Concatenated Feature Vector (~40-60 dims audio+vision), Hybrid Scheme (supervised backbone + gated discovery), Labels Assign Meaning (geometry only proves separation) (+1 more)

### Community 25 - "ML/DSP Methods Brief"
Cohesion: 0.25
Nodes (9): Two-Tier Latency Contract, Readable Eigenvector (named-feature LDA loadings), Pairwise Mahalanobis d' in LDA Subspace, CREPE / pYIN / basic-pitch F0 estimators, Haptic-Score Generative Idea (CUT for LEARN+PLAY pivot), Information Transfer Evaluation (IT bits, d'), Audio-Tactile Latency Asymmetry (haptic-leads tolerated), Audio→Haptic ML/DSP Research Brief (+1 more)

### Community 26 - "Canonical Docs (truth.md)"
Cohesion: 0.19
Nodes (14): Pressure from timbre, no sensor (reject FSR), docs/11-ai-and-pitch.md (AI engine + pitch for judges), AI/determinism split (ML where unsolved, deterministic where solved), Buzz inverse (B = f(P,d); vision pins d, audio measures B), Fusion perception model (disagreement = detected mistake), docs/17-ai-rigor.md (AI core rigor argument), Arize/Phoenix tracing + eval (F0, classifier, VLM accuracy), Disagreement-as-signal (cross-modal mismatch = error detector) (+6 more)

### Community 27 - "Power Budget & Modes"
Cohesion: 0.07
Nodes (26): Capture — prompted data collection, Fallback: terminal conductor + QuickTime, Files, Recommended: localhost app (capture + labeling + QC in one page), 0. The principle — the prompt IS the label, 0b. What the data actually trains — the two "last miles", 10. Recording — the localhost capture app (recommended) + a zero-dep fallback, 1. The rig (+18 more)

### Community 29 - "Data Collection Protocol"
Cohesion: 0.29
Nodes (8): Prompt-only Label, Audio Verifier Only (D2), D2 Relabel/Drop Selection-Bias Leak (critical gap), Capture Matrix (6 strings x 6 frets x classes), Data Collection & Labeling Protocol, Interval Audit Dashboard (anti-digression), The Prompt IS the Label (no hand-tagging), Prompted Runs (continuous sweep, not one-note blocks), Capture README (prompted data collection)

### Community 30 - "Project History & Haptic Render"
Cohesion: 0.25
Nodes (8): Localhost capture app (serve.py + capture.html), CHANGELOG.md (chronological project history incl. pre-pivot), Hearth -> Tactus full pivot, 2-axis code (string->back actuator + fret->torso zone+intensity), Component A — Haptic Reference (what it should feel like), Deterministic haptic renderer (signal->vibration transform), Saramonic LavMicro-U (USB-C digital lavalier mic), Train/serve match (same mic + camera for training and inference)

### Community 31 - "Engine Pipeline (Fusion)"
Cohesion: 0.28
Nodes (9): Audio branch (F0/transcription + dynamics + technique model), F0 engine (pYIN/YIN live; CREPE offline), Fusion (time-align + reconcile audio vs vision), MediaPipe Hands (21 landmarks/hand), Redis memory (per-user mistake history, vector search), Reference diff (target MIDI/tab vs played), docs/08-software-architecture.md (engine pipeline), Vision branch (MediaPipe Hands + fretboard homography) (+1 more)

### Community 32 - "Demo Data Generator"
Cohesion: 0.43
Nodes (6): build(), _hz(), main(), _note(), One plucked note: decaying harmonic stack, optional broadband buzz burst, OR, Write a synthetic batch under raw_dir. Returns the list of player dirs.

### Community 33 - "ArUco Pose-Lock Filter"
Cohesion: 0.10
Nodes (28): makePoseLock(), OneEuro, _alongNeckEnds(), angDeg(), _applyAffine(), _assignCorners(), clamp01(), _confidence() (+20 more)

### Community 34 - "Separability & Cluster Viz"
Cohesion: 0.50
Nodes (4): Bayesian Position Posterior with theory prior, Targeted 2D Correction Fretboard (per-finger fix), Every Pixel is a Sense the Deaf Learner Lacks, Interface: Live AR Play + Targeted 2D Correction

### Community 35 - "Audit Tests"
Cohesion: 0.47
Nodes (5): _build_events_df(), _build_metrics(), main(), ~30 rows across the 3 core classes / strings 6..1 / frets 1..6.      Determinist, Minimal metrics dict matching collapse.py's shape (docs/24 §8):       split, cla

### Community 36 - "Audio Feature Tests"
Cohesion: 0.47
Nodes (5): _event_row(), main(), 0.6 s exponentially-decaying 110 Hz tone followed by 0.4 s of silence., One events.csv row filling every schema.EVENT_COLUMNS field., _write_a2_wav()

### Community 37 - "Vision Feature Tests"
Cohesion: 0.47
Nodes (5): _build_twin(), main(), _make_provider(), Synthetic twin: 4 image corners (a foreshortened-ish rectangle) matched to     b, Stub provider returning a known index-fingertip pixel per event.      event 'v#0

### Community 38 - "Segmentation Tests"
Cohesion: 0.53
Nodes (5): _make_manifest(), _make_wav(), _pluck(), A decaying sinusoid ('pluck') followed by silence. The envelope is tapered     t, test_segment()

### Community 39 - "AR Prototypes (Beat-Saber)"
Cohesion: 0.60
Nodes (6): alphaTab real-song chart source (planned), ar.html chord-field AR prototype, js-aruco2 neck pose-lock (planned next layer), beatsaber.html Beat-Saber AR highway prototype, Live camera AR overlay (transparent canvas over webcam), Note/chord chart (string,fret,t,dur)

### Community 40 - "Correction Interface & Posterior"
Cohesion: 0.10
Nodes (19): 0. The 60-second mental model of the whole rig, 10. Laptop connection + power — exactly what plugs into what, 11. SK473 reality (live teardown, Jun 20): it's 6 stereo PAIRS = **12 channels**, and the amp *is* separable, 12. UPDATE (Jun 20 teardown): use the SK473's OWN drivers (KHD 3 Ω/5 W), and the ≤2-at-once power win, 15 — Build refinements + the kinks that will bite (read before Saturday), 1. ⚠️ THE BIG ONE — PAM8403 is a BTL amp: never common the "−" outputs, 2. ⚠️ The Vantec/ALSA enumeration trap (this eats Saturday if you don't pre-empt it), 3. Wire gauge — you only have 18 AWG, so the build has to respect it (+11 more)

### Community 41 - "Pipeline Runner"
Cohesion: 0.60
Nodes (4): main(), _manifests(), Run the full pipeline over every manifest under raw_dir (optionally filtered, run_batch()

### Community 42 - "Collapse Tests"
Cohesion: 0.60
Nodes (4): _dprime(), main(), _make_df(), Pull pairwise d'(a,b) out of whatever key shape collapse used.

### Community 43 - "End-to-End Pipeline Test"
Cohesion: 0.67
Nodes (3): _buzz_pair_dprime(), Pull d'(buzz-light, buzz-placement) out of whatever key shape collapse used., test_end_to_end()

### Community 44 - "Record Conductor CLI"
Cohesion: 0.83
Nodes (3): ask(), main(), show()

### Community 45 - "AlphaTab Chart Loader"
Cohesion: 1.00
Nodes (3): AT(), loadChart(), loadScore()

### Community 47 - "ArUco Marker Asset"
Cohesion: 0.67
Nodes (3): ArUco Marker 4x4_50 ID 0, ArUco Dictionary DICT_4X4_50, Fiducial Pose Estimation and Calibration

### Community 51 - "Community 51"
Cohesion: 0.18
Nodes (11): The one correction (3 axes: wrong note, duration, pressure), README.md (Tactus project overview), 0. What is true vs what is stale (read first), 1. Direction & goal, 2. Locked software architecture, 5. Haptic encoding (the deterministic renderer), 6. The AI/ML (perception model), 7. Sponsors / tracks targeted (+3 more)

### Community 52 - "Community 52"
Cohesion: 0.13
Nodes (15): 2026-06-19 — Direction changes (per Aditya): reframe + remove the score, 2026-06-19 — Full pivot: Hearth → Tactus, 2026-06-19 — Hardware corrected after live inventory cross-check (physics), 2026-06-19 — LEARN re-architected: vision + haptic closed-loop guitar coaching (per Aditya), 2026-06-19 — Refinement pass on the as-built rig (enclosure CAD + build kinks + LEARN UI), 2026-06-19 — Vest-primary form factor + LEARN web app added to scope (per Aditya), 2026-06-20 — Data-collection: frets 1–6 scope lock, last-mile↔data framing, Day-1 recorder, 2026-06-20 — docs/26 handoff + repo-wide markerless reconciliation (+7 more)

### Community 53 - "Community 53"
Cohesion: 0.14
Nodes (14): 0. The eight locked decisions, 10. Open questions for ENG review, 11. Award alignment (why this wins, `docs/19`), 1. The data pipeline (capture + labeling), 20 — AIML training design: multimodal guitar-technique coaching (comprehensive spec), 2. The vision stack (D3) — seeing through the hand, 3. The audio stack + the buzz inverse (D4→D6), 4. The fusion model (D8) — one Bayesian framework (+6 more)

### Community 54 - "Community 54"
Cohesion: 0.15
Nodes (12): 13 — LEARN: Closing the Loop (feel the target · see the fix), 1. The learning loop (one flow — replaces the old practice modes), 2. The four components, 3. Local memory — practice anywhere, offline (Redis, baked in), 4. The interface (camera-centric, every pixel real), 5. Architecture + parallelization (the seam), 6. Sponsors this unlocks (a much deeper story), 7. Honest scope — demoable this weekend vs research-bet (+4 more)

### Community 55 - "Community 55"
Cohesion: 0.15
Nodes (12): 20 — Eng review of the AIML training design (`docs/20-aiml-training-design.md`), Completion summary, Corrected identifiability (what's observed vs hidden), Data collection — breadth vs depth (fits 2–4 hrs), Decisions taken (this review), Diagrams, Failure modes (per new codepath: realistic failure · test? · error handling? · silent?), Implementation tasks (+4 more)

### Community 56 - "Community 56"
Cohesion: 0.15
Nodes (12): 0. The pivot (what changed — read first), 10. Open risks, 1. Three deliverables, 27 — Chord feedback, mono↔poly transfer, and the 3D semantic viz (analysis + experiment plan), 2. Data inventory, 3. Core hypotheses (first principles), 4. Pipeline, 5. Experiment matrix (multiple labelings — run them all, let one win) (+4 more)

### Community 57 - "Community 57"
Cohesion: 0.17
Nodes (11): 1. Single note (recap of `docs/07`), 21 — Chord, sustain & percussive rendering (extends docs/07), 2. Chords — the onset encodes HOW it was struck, 3. Sustain = envelope-modulated looped shimmer (LOCKED), 4. The other axis + foundation, 5. Percussive & muted hits, 6. Power (reconciles `docs/15 §12`), 7. Tunable parameters (→ `docs/18` experiments) (+3 more)

### Community 58 - "Community 58"
Cohesion: 0.17
Nodes (12): 1. A/V sync is RECOVERED offline, not assumed [HIGH], 25 — Corrected data & feature processing contract (the offline pipeline codes against THIS), 2. Segmentation = beat-anchored priors + F0-assigned frets (NOT onset-detect + sweep-order) [HIGH], 3. The audio-only vs fused ablation runs on the SAME events [HIGH], 4. Never mix lossy and lossless audio in the buzz study [MED-HIGH], 5. Control pitch with string/fret as COVARIATES, not per-cell z-score [MED-HIGH], 6. Separability metric = pairwise Mahalanobis d′ in the LDA subspace [MED], 6b. Cross-validation: the RUN is the correlated unit [MED] (+4 more)

### Community 59 - "Community 59"
Cohesion: 0.18
Nodes (10): ArUco marker (vision) — OPTIONAL validation rig only, Assembly (no soldering — truth.md §3, docs/09), CAD — the printed enclosure + body-coupling pucks (FlashForge Adventurer 5M), Parameters you'll most likely touch, ★ PRINT THIS — the verified print-ready set, Reference parts (OpenSCAD-only — need an OpenSCAD machine to re-render), Render → STL (headless, no OpenSCAD), Slicing (FlashForge Adventurer 5M — open-frame, web-confirmed) (+2 more)

### Community 60 - "Community 60"
Cohesion: 0.18
Nodes (11): 0. The thesis — AI where it's *unsolved*, determinism where it's *solved*, 17 — The AI core: audio + vision → high-granularity (string, fret, finger, quality) → targeted feedback, 1. High-granularity POSITION — why fusion beats either modality alone, 1a. Audio branch (what + how-clean), 1b. Vision branch (where + which finger) — runs in the **browser**, 1c. Fusion (the part that's a real contribution, not a wrapper), 2. High-granularity TARGETED FEEDBACK — three axes, each a measured signal, 3. The rigor moves (cheap, high-credibility — have these ready at the table) (+3 more)

### Community 61 - "Community 61"
Cohesion: 0.18
Nodes (11): 1. How a cluster becomes advice (the epistemics), 23 — Data, representation, training & the eigenvector→advice semantics (extends docs/20), 2. The hybrid scheme (OH1), 3. Data collection protocol, 4. How much data (with the why), 5. Data representation, 6. Promotion gate — when a discovered sub-family earns advice, 7. Training procedure (most of it isn't deep learning) (+3 more)

### Community 62 - "Community 62"
Cohesion: 0.22
Nodes (5): 1. Tactile Psychophysics, 2. Tactile Illusions, 3. Prior Art, 4. Honest framing, REF — Vibrotactile Music Perception Research Brief (raw, cited)

### Community 63 - "Community 63"
Cohesion: 0.20
Nodes (10): Actuators (the SK473's own KHD drivers), Amplifiers, Audio source (DAC / channels), Bill of materials, Channel accounting, Not needed for the audio path, Owned now, Power (+2 more)

### Community 64 - "Community 64"
Cohesion: 0.20
Nodes (10): Assembly checklist + bring-up, Go/no-go summary, Stage 0 — bench prep, Stage 1 — prove the audio path (BEFORE any soldering), Stage 2 — gut + tone-test each amp (×6), Stage 3 — power, Stage 4 — chord stress test, Stage 5 — mount + couple (+2 more)

### Community 65 - "Community 65"
Cohesion: 0.22
Nodes (9): Fewer-ports fallback, Hard rules (break these and you fry something), Mode A — wall (RECOMMENDED for the judged demo), Mode B — cordless (the portability "wow"), Per-bus loads (computed the right way), Power architecture + the chord-safety guarantee, Pre-power checklist (every session), The numbers (per channel / per amp) (+1 more)

### Community 66 - "Community 66"
Cohesion: 0.22
Nodes (9): Chords / strums, Design rules (or it turns to mush), Fret → 6 torso zones (12 frets onto 12 channels), Haptic encoding — note → actuator, Pulse shape, Relationship to the coach, The 2-axis code, The premise (why this design exists) (+1 more)

### Community 67 - "Community 67"
Cohesion: 0.22
Nodes (9): ALSA / multichannel, "Any song", Compute placement (be honest in the demo), Haptic renderer, Pipeline, Software architecture, Stack, Suggested layout (+1 more)

### Community 68 - "Community 68"
Cohesion: 0.22
Nodes (9): Amplification — gut SK473 boards (PAM8403), Audio source / channels — USB 7.1 (Vantec NBA-200U, CM6206), Bass — dropped (was Logitech Z313), Brain — laptop (Pi cut from critical path), Channel count — 12, Design decisions (why, and what we rejected), Encoding — location + timing, not frequency, Power — two modes (+1 more)

### Community 69 - "Community 69"
Cohesion: 0.22
Nodes (8): 18 — Tuning & calibration: the on-body experiments (fill in Saturday), Experiment 1 — drive-frequency sweep (do this FIRST, per zone), Experiment 2 — punchiness (pulse shape), Experiment 3 — coupling pressure, Experiment 4 — per-channel gain calibration, Record the winners (these become the renderer defaults), Safety bounds (don't cross while experimenting), The 4 knobs you're tuning

### Community 70 - "Community 70"
Cohesion: 0.22
Nodes (9): 22 — The interface: live AR play + targeted 2D correction (the centerpiece), A. LIVE AR PLAY — Beat-Saber depth-approach on your real fretboard, Award alignment (`docs/19`), B. TARGETED CORRECTION (on error) — the super-simple 2D fretboard, Build order (de-risked), Coherence (one phase-locked signal → screen + body + sound), Open questions for eng review, Per-finger position + pressure — what's supportable (ties to `docs/20`) (+1 more)

### Community 71 - "Community 71"
Cohesion: 0.22
Nodes (9): 3.1 Compute / brain, 3.2 Audio-out chain & channel map (12 channels), 3.3 Drivers & body coupling, 3.4 Amps (PAM8403, filterless Class-D, BTL), 3.5 Power, 3.6 Wire, 3.7 CAD / enclosure (FlashForge Adventurer 5M, 220×220×220 mm bed), 3.8 Sensing (+1 more)

### Community 72 - "Community 72"
Cohesion: 0.25
Nodes (8): AI engine + pitch (for judges and the software team), Any song (generalizability), Build-first (MVP for max judge ROI), Honest scoping (this is rigor, not weakness), Rigor moves (cheap, high-credibility), The AI pieces (ranked by how non-gimmicky), The honest framing (say this to judges), Track / prize alignment

### Community 73 - "Community 73"
Cohesion: 0.23
Nodes (12): actuator_puck (cup + button coupler), docs/15-build-refinements.md (as-built teardown log + kinks), PAM8403 BTL warning (never common the minus outputs), Single-channel-first build order (prove one end-to-end), SK473 teardown (6 stereo pairs = 12 channels; amp separable), Use SK473's own KHD drivers (factory-matched, punchier), 4 tuning knobs (drive freq, pulse shape, coupling, per-channel gain), Per-channel software gain (the volume control, pots bypassed) (+4 more)

### Community 74 - "Community 74"
Cohesion: 0.29
Nodes (7): Electrical, Eliminate it — every joint, no exceptions, Mechanical — the wire weight problem (this breaks things), Mounting the actuator (so it's felt, not heard, and stays put), One-line pre-flight, Risk table (and how each is eliminated), Safety — eliminate every risk

### Community 75 - "Community 75"
Cohesion: 0.29
Nodes (7): Funneling / sensory saltation — why we separate simultaneous hits, How each maps to our design, Perception references (why the encoding is shaped this way), Precedents (this approach works, with training), Spatial acuity — why sites are spread, and resolution lives on the limbs, Temporal acuity — the skin's strength, Vibrotactile frequency — why we don't encode pitch as frequency

### Community 76 - "Community 76"
Cohesion: 0.29
Nodes (7): 19 — Sponsor & prize alignment (refined to the as-built rig), Action items, Dropped — do NOT apply or build for, The system as one coherent sponsor story, Tier 1 — go hard (highest win probability; build the demo around these), Tier 2 — strong, low marginal effort (claim them, don't reorganize for them), Tier 3 — only if it's free

### Community 77 - "Community 77"
Cohesion: 0.29
Nodes (7): 0. Read these first (in order), 1. What you're getting, 26 — Data handoff for the offline pipeline (Aiden), 2. Manifest row schema (real example — fields are authoritative, not `run_id`), 3. The 6 processing gotchas (full detail in `docs/25` — don't skip), 4. What to build (mirrors `docs/25` §8), 5. Deps

### Community 78 - "Community 78"
Cohesion: 0.29
Nodes (7): Competitive white space (triad nobody fully occupies), Deaf-culture framing (do-or-die), Instrument-haptics psychophysics, Instrument prior art, Pitch engines, REF — Instrument-Learning + Sponsor + Deaf-Framing Brief (raw, cited), Sponsor integrations (deep, non-bolt-on)

### Community 79 - "Community 79"
Cohesion: 0.29
Nodes (6): Brain placement, Channel budget, Connector cheat-sheet (where confusion happens), System architecture, The full chain, every connector, Why two devices per "DAC + power"

### Community 80 - "Community 80"
Cohesion: 0.33
Nodes (6): Job 1 — gut an SK473 (×6), Job 2 — attach actuators to the amp (×12), Job 3 — build the 5V solder bus (cordless / Mode B), Joint quality, Order of operations (matches [09-assembly-checklist.md](09-assembly-checklist.md)), Soldering guide

### Community 81 - "Community 81"
Cohesion: 0.33
Nodes (6): Buy / make, Confirm, Decide, Known limitations (state honestly in the demo), Open questions + to-do, Repo / logistics

### Community 82 - "Community 82"
Cohesion: 0.33
Nodes (5): Helpers (prepared, not yet wired), `_prototypes/`, Run, Tactus — web, What glow.html is

### Community 83 - "Community 83"
Cohesion: 0.40
Nodes (5): Build-tonight TL;DR, Pick your lane, Start here (teammates), Status, What tactus is (30 seconds)

### Community 84 - "Community 84"
Cohesion: 0.40
Nodes (5): ALSA side, Labeling rule, The map, Why this layout, Wiring map — channel by channel

### Community 86 - "Community 86"
Cohesion: 0.50
Nodes (4): Docs map, 🎸 Tactus, The 30-second version, The rig (as-built — full detail in [`truth.md`](truth.md))

### Community 87 - "Community 87"
Cohesion: 0.50
Nodes (4): Bring-up order, Install, software, What to build first (MVP slices)

### Community 89 - "Community 89"
Cohesion: 0.25
Nodes (8): print_marker.html (ArUco print sheet, scale at 100%), ArUco marker 4x4_50 id 0 (optional validation rig), FlashForge Adventurer 5M (220^3 PETG bed), cad/README.md (printed enclosure + coupling pucks), Guitar digital twin (per-guitar reference keyframes), Markerless fretboard registration (12-TET fret-law homography), Stage 1 — WHERE (vision-led position: string, fret, finger, d), Whole-guitar framing at 1080p + offline ROI crop

### Community 90 - "Community 90"
Cohesion: 0.38
Nodes (7): Per-bus load math (amps_on_bus x per-amp draw), docs/03-power.md (chord-safety power math), USB-C 5.1k CC resistor (enables cut USB-C PD feed), One-powered-hub-does-both topology (data + 5V power), Power Mode A — wall 10-port hub, Power Mode B — Anker 737 cordless bus, Sequential strum sweep (<=2 drivers active -> ~2-3W peak)

### Community 91 - "Community 91"
Cohesion: 0.33
Nodes (6): LLM coach (Anthropic Claude, phrase-level), Deepgram hands-free voice (rewind/slower/again), Feel-the-difference (your version vs correct, back-to-back), docs/13_LEARN_WEB_AND_VISUALIZATION.md (LEARN loop + WebSocket contract), No-hardware fallback (runs on laptop against recording), Component C — VLM coach (Claude vision finger highlight)

### Community 92 - "Community 92"
Cohesion: 0.50
Nodes (4): 4. Exact purchases — granular parts ledger (owned now), Body-side fabricated parts (3D-printed, `cad/`) — dimensions, Electronics (the rig), Tools

## Knowledge Gaps
- **362 isolated node(s):** `ndarray`, `2026-06-20 — Framing pivot: whole-guitar capture (1080p) + offline ROI crop`, `2026-06-20 — docs/26 handoff + repo-wide markerless reconciliation`, `2026-06-20 — Markerless fretboard registration + guitar digital twin (no taped marker)`, `2026-06-20 — Localhost capture app (synced A/V + maximal metadata + live QC)` (+357 more)
  These have ≤1 connection - possible missing edges or undocumented components.
- **3 thin communities (<3 nodes) omitted from report** — run `graphify query` to explore isolated nodes.

## Suggested Questions
_Questions this graph is uniquely positioned to answer:_

- **Why does `truth.md — Tactus single source of truth` connect `Community 51` to `Community 71`, `Actuator Hardware & Coupling`, `Amp/BOM & Safety Hardware`, `Community 62`, `Community 89`, `Community 90`, `Community 91`, `Community 92`, `Project History & Haptic Render`, `Engine Pipeline (Fusion)`?**
  _High betweenness centrality (0.096) - this node is a cross-community bridge._
- **Why does `cad/README.md (printed enclosure + coupling pucks)` connect `Community 89` to `Community 73`, `Enclosure CAD Model`, `Community 51`?**
  _High betweenness centrality (0.024) - this node is a cross-community bridge._
- **What connects `# NOTE: the .scad's rim_lip subtraction is a geometric no-op (it lies inside`, `Cylinder of length h centered at (cx,cy,cz), running along axis x/y/z.`, `Vertical-edge rounded rectangular prism, min-corner at (0,0,z0).` to the rest of the system?**
  _502 weakly-connected nodes found - possible documentation gaps or missing edges._
- **Should `AI Audit Report Generator` be split into smaller, more focused modules?**
  _Cohesion score 0.07562008469449485 - nodes in this community are weakly interconnected._
- **Should `Speaker/Actuator Check Harness` be split into smaller, more focused modules?**
  _Cohesion score 0.10526315789473684 - nodes in this community are weakly interconnected._
- **Should `Fretboard Vision Registration` be split into smaller, more focused modules?**
  _Cohesion score 0.09815078236130868 - nodes in this community are weakly interconnected._
- **Should `Audio Feature Extraction` be split into smaller, more focused modules?**
  _Cohesion score 0.09269162210338681 - nodes in this community are weakly interconnected._

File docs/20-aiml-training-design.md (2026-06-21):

# 20 — AIML training design: multimodal guitar-technique coaching (comprehensive spec)

Status: **DRAFT — for `/plan-eng-review`**. Mode: hackathon (AI Berkeley 2026).
Extends `docs/17-ai-rigor.md` with the locked model (the buzz response-surface + Bayesian position posterior). Produced via an office-hours session (decisions D1–D8 below).

> **One-line thesis:** from a webcam + a mic, recover **where each finger is, on which fret, and how cleanly it's fretted** — by fusing vision and audio through a learned physical model — and recover the **unobservable** quantity (finger pressure) as an *inverse problem*. The AI lives exactly where the problem is unsolved (reading an occluded fretting hand and a cause-blind buzz); everything downstream is a measurable transform.

---

## 0. The eight locked decisions
| # | Decision | Choice |
|---|---|---|
| D1 | Supervision | **Self-collected deliberate-technique dataset**, multimodal (synced video+audio). |
| D2 | Labeling | **Prompted + audio-verified** — the prompt is the intended label; an independent audio check must agree or the sample is relabeled/dropped. Dual-witness labels, balanced by a capture checklist. |
| D3 | Vision | **Hybrid:** MediaPipe Hands + **markerless** OpenCV homography (fret-law; ArUco optional, `software/ai/vision/fretboard.py`) → fretboard-relative pose [deterministic]; read fret directly when visible; when occluded (common), a **trained model maps visible hand-pose → occluded (string, fret, sub-fret, per-finger quality)**, with **audio (pitch→fret) as the free teacher.** Do **not** rewrite hand tracking. |
| D4→D6 | Fault model | **Buzz is cause-blind in audio** (empirically: a pressure-buzz and a placement-buzz sound the same). So model **buzz magnitude B = f(pressure P, wire-distance d)**; vision measures **d**, audio measures **B**, **invert the fitted surface to recover P.** Pressure is an *inverse problem*, not a sensor reading. |
| D5 | Validation | **Separability study** (LDA/PCA + Fisher ratio, silhouette, pairwise d′, confusion matrix) across audio-only / vision-only / fused — empirically proves fusion is required and decides the taxonomy from data. |
| D7 | Representation | **Both:** engineered-feature core (LDA/UMAP) for the dependable model + the **live 3D cluster viz**; a learned **contrastive multimodal embedding** as the research-grade stretch (+ Redis nearest-neighbor retrieval). Embedding is cut-first. |
| D8 | Theory | **Bayesian position posterior with a theory prior:** `P(pos|obs) ∝ P(pose|pos)·P(pitch|pos)·P(pos|context)`, where context = **the intended chord/note from the sheet music** (chroma fallback in free-play) + standard fingerings + hand continuity. Strong likelihood overrides the prior → that override **is** the error detection. |

---

## 1. The data pipeline (capture + labeling)

**Every sample = a synchronized `(video frame(s), audio window)` pair** at a known, prompted condition.

**Capture rig.** MacBook front camera on the neck; **markerless fretboard registration** (fret-law homography, off-the-hand fretboard frame survives occlusion; ArUco optional validator only); mic clipped inside the body near the soundhole. One Python capture process timestamps both streams on a monotonic clock; the **audio onset** stamps the event time, and the nearest video frame(s) are grabbed. (A clap/transient at session start cross-checks A/V sync.)

**Prompted, dual-witnessed labeling (D2).** The app prompts an exact condition — e.g. *"low-E, fret 3, ring finger, pressure TOO LIGHT"* — so the **prompt is the intended label** (no manual annotation). Then an independent **audio check** (buzz/HNR/decay) must agree; disagreements are relabeled by the audio outcome or dropped. Classes stay balanced because the capture **checklist** dictates what's played.

**Coverage checklist** (per the capture plan): a representative neck subset (e.g. open + frets 1/3/5/7 across all 6 strings) × conditions {clean, buzz-light-pressure, buzz-too-far-back, muted/dead, choked-sharp} × the responsible finger. ~10–15 takes each → a few hundred to ~1–2k labeled multimodal samples (enough for the classical core + the response surface; the embedding wants the upper end).

---

## 2. The vision stack (D3) — seeing through the hand

```
camera ─► MediaPipe Hands (21 landmarks/hand)  ─┐
       ─► OpenCV markerless homography ─────────┘─► hand pose in FRETBOARD-RELATIVE coords
                                                     │
   fingertip + local grid VISIBLE? ── yes ──► read (string,fret) deterministically
                                    ── no  ──► TRAINED pose→placement model:
                                               features {per-finger curl, joint angles,
                                               fingertip→wire distance d, neck position,
                                               wrist angle} → (string, fret, sub-fret d,
                                               per-finger quality)
                                               TEACHER at train time: audio pitch → true fret
```
- **Why learned:** the hand occludes the contact point; the visible pose still encodes the answer; audio gives the label for free, so occlusion is a *supervised* problem, not a blocker. This is the defensible AI contribution.
- **Fretboard-relative frame** is what makes it generalize across camera angles — train and infer on pose expressed in homography coordinates, not pixels.
- **Per-finger d** (fingertip-to-fret-wire distance) is the single most important engineered feature: it's the disambiguator for buzz cause (§3) and the placement-quality signal.

## 3. The audio stack + the buzz inverse (D4→D6)

**Audio features per note (the engineered representation, all citable):** spectral centroid / flux / flatness / rolloff, **harmonic-to-noise ratio**, **inharmonicity**, attack time, decay rate, **MFCCs**, a **broadband buzz-energy ratio**, zero-crossing rate, and **chroma** (pitch/harmony context). F0 (YIN/pYIN/CREPE) gives pitch → fret.

**The buzz inverse — the research-grade core:**
- Buzz `B = f(P, d)` is monotone (↓P→↑B, ↑d→↑B), plausibly **quadratic in d** (characterizing the curve is a real finding).
- Audio alone gives `B`, which depends on **both** P and d → **underdetermined** (this is *why* a pressure-buzz and placement-buzz are confusable from sound).
- **Vision pins d**; then `B → P` is **identifiable.** Recover **P** by inverting the fitted surface.
- **Ground-truth honesty:** no force sensor → P is supervised only by **ordinal intent** (too-light / good / too-hard). So `f` is fit as `B` vs `d` per pressure level, and inference is "given measured `(B, d)`, which pressure level best explains it." **Report P as ordinal/relative, never Newtons.**

**Feedback decomposition (the granular advice):**
1. Posterior says wrong fret/note → *"wrong note — ring finger to fret 3."*
2. Buzz + **d large** → *"slide toward the fret"* (placement).
3. Buzz + **d small** → *"press harder"* (pressure).
4. Muted/dead → *"press firmer / clear the neighbor string."*
5. Sharp/choked → *"ease off — you're bending it."*
6. Timing (onset/offset vs beat) handled on a separate axis.

## 4. The fusion model (D8) — one Bayesian framework

```
P(position, fault | V, A, C) ∝ P(V | position,fault)   ← learned pose likelihood (occlusion model)
                              · P(A | position,fault)   ← audio: pitch→fret (sharp), buzz→quality
                              · P(position | C)          ← THEORY PRIOR
   C (context) = intended chord/note from the sheet music  (chroma-derived chord/key in free-play)
                 + standard-fingering table + hand-position continuity
```
- **MAP estimate** = what they actually played (position + per-finger fault).
- **Error detection = divergence** between the posterior (played) and the prior mode (intended). The dimension of divergence picks the feedback category.
- **Safeguard = Bayesian behavior:** a confident vision+audio likelihood overrides the prior, so playing the "wrong" chord is detected, not hidden. Tune the prior weight so it informs without dominating.

## 5. Representation, embedding, and the live 3D cluster viz (D7)

- **Core (reliable):** the ~40–60 engineered audio+vision features; **LDA** (supervised, maximizes between/within-class scatter — the principled "axis along which a fault collapses") + **UMAP** for the cluster geometry.
- **Stretch (research-grade, cut-first):** a small **contrastive multimodal embedding** (triplet/InfoNCE) that pushes faults apart; report whether it **beats the engineered baseline** (an ablation = a result), and power **Redis vector retrieval** ("your mistake is nearest these past attempts").
- **★ The live 3D cluster view (visual centerpiece):** a rotating WebGL scatter on 3 LDA/UMAP axes, points colored by fault, the **live note dropping in as a glowing point** that animates into its cluster, with a **audio-only ↔ fused toggle** that visibly **collapses the overlapping blob into separated clusters** — the entire multimodal-necessity argument in one gesture, all real data.

## 6. Evaluation protocol (what we put on the slide)
- **The headline ablation:** identification accuracy **audio-only vs vision-only vs fused** → fused wins (especially on pressure-vs-placement). A confusion matrix shows audio-only confuses the two buzz causes; fusion separates them.
- **Separability (D5):** Fisher ratio, silhouette, pairwise **d′** per fault pair, per modality.
- **Position accuracy** vs the audio-derived ground-truth fret (incl. the occluded subset — the hard case).
- **Pressure-level accuracy** (ordinal) + the **response-surface fit** (R², shape — is it quadratic in d?).
- **Generalization:** collect from 2–3 players, **hold one out**, report the train/test gap honestly (single guitar is a stated limit).
- **Calibration:** are the model's confidences meaningful (reliability diagram). Trace inferences in **Arize/Phoenix**; catch octave/mapping errors live.

## 7. Data-collection logistics
- **2–3 players, 1 guitar** (state the single-guitar generalization caveat).
- Prompted-capture harness; ~10–15 takes × the coverage checklist → **~few hundred to ~1.5k samples**, ~**2–4 hrs**.
- Balanced by construction; audio-verified; held-out player reserved.

## 8. Honest scope + failure modes (rigor = honesty)
- **Pressure is ordinal/relative**, not Newtons (no force sensor).
- **Placement is fingertip-to-wire distance** (coarse longitudinal), not exact cm.
- **Per-finger is clean for single notes**; for chords it's **vision-attributed + audio-confirmed** (best-effort — the finger with worst geometry owns a detected buzz).
- **Polyphony degrades** dense/fast playing → vision cross-checks; scope live assessment toward single-line where possible.
- **Single guitar/player** → flag overfit; the held-out-player number is the honest generalization claim.
- State **real-time vs pre-processed** in the demo.

## 9. Build order (MVP slices — for the ENG review to sequence)
1. **Prompted-capture harness** + collect a small set on one or two strings.
2. **Feature extraction + the LDA separability study (D5)** → confirm fusion necessity, get the first cluster plot.
3. **Position:** deterministic-when-visible + audio pitch→fret; then the **occlusion pose-model** on the collected data.
4. **Buzz response surface** fit + inverse → ordinal pressure.
5. **Bayesian fusion** + the **theory prior** (intended chord from a loaded tab).
6. **The viz suite:** live 3D cluster view (centerpiece) + response-surface view + pipeline ribbon.
7. **Stretch:** contrastive embedding + Redis retrieval + the "embedding beats features" ablation.

## 10. Open questions for ENG review
- A/V **sync** method + tolerance (timestamp alignment under playing motion).
- **Homography robustness** while the neck moves; re-detect cadence; do we need IMU/optical-flow stabilization?
- **MediaPipe accuracy on guitar hands** (heavy self-occlusion) — does it need augmentation/fine-tuning, or is raw landmark confidence enough as a feature?
- **How many (string,fret) positions** to cover for the pose-model to generalize across the neck without collecting all 6×12.
- **Prior-weight calibration** (theory vs likelihood) — how to set it so deviations are caught but occlusion is still resolved.
- **Per-finger attribution in chords** — is vision geometry enough, or do we restrict per-finger claims to single notes for the demo?
- **Real-time budget** for fusion + the WebGL viz on the laptop alongside MediaPipe + F0.

## 11. Award alignment (why this wins, `docs/19`)
Most-Technical (the inverse-problem fusion + the separability proof + the response surface), Best UI/UX (the live 3D cluster + response-surface views), Anthropic (Claude turns the posterior + fault into the plain-language fix), CV track (pose→occluded-placement), Redis (embedding retrieval / mistake memory), Accessibility (the whole point).

---

### The assignment (do this next, you have the guitar)
Build the **prompted-capture harness** and run the **D5 separability study** on 1–2 strings: record ~12 takes each of clean / buzz-light / buzz-too-far-back / muted / choked, extract the audio features, run **PCA + LDA**, and read **Fisher ratio + silhouette + pairwise d′ + a confusion matrix**. That one experiment (a) confirms your "buzz is cause-blind in audio" finding quantitatively, (b) decides the taxonomy from data, and (c) produces your first real cluster plot — the seed of the centerpiece viz.
</content>

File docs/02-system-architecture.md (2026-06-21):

# System architecture

Three layers: **sense → understand → render**. The brain (laptop) does sense + understand; the hardware chain does render. Vision (camera + MediaPipe + ArUco + AR) runs in the **browser**; audio + the fusion model + 12-ch haptic out run in **Python**; they sync over one localhost WebSocket. See [`../truth.md`](../truth.md) §2 for the locked software split.

## The full chain, every connector

```
[guitar]   [webcam]   [mic]
    \          |        /
     \         |       /          (vision + audio in)
      v        v      v
 +-------------------------+
 |   LAPTOP  (AI brain)    |  vision: MediaPipe + ArUco homography (in the BROWSER)
 |   - transcription       |  audio:  F0 + timbre/technique + RMS (Python)
 |   - fusion + diff       |  fusion: cross-check audio vs vision
 |   - LLM coach + UI      |  out:    note/feedback events -> haptic renderer
 +-----------+-------------+
             | USB (data)
             v
 +-------------------------+
 | 2x Vantec NBA-200U 7.1  |  USB digital -> 8 analog channels each
 |  4 stereo jacks each    |  V1 = ch 1-8, V2 = ch 9-12; V3 spare
 +-----------+-------------+  CONNECTOR: 3.5mm jacks (round holes)
             | 3.5mm PLUG  (SK473's own captive plug -> Vantec jack)
             v
 +-------------------------+        power (5V):
 | 6x SK473 amp boards     | <----- Mode A: 10-port hub (wall)
 |  PAM8403, 2 ch each     | <----- Mode B: Anker 737 via solder bus
 |  = 12 channels          |  CONNECTOR in: 3.5mm. CONNECTOR out: solder pads
 +-----------+-------------+
             | 18 AWG SPEAKER WIRE (soldered to output pads)
             v
 +-------------------------+
 | 12x KHD 3 Ω/5 W drivers |  6 strings (back) + 6 fret-zones (torso)
 |  (de-housed)            |
 +-------------------------+
```

## Connector cheat-sheet (where confusion happens)

| Link | Connector | Bare wire? |
|---|---|---|
| Vantec → SK473 | 3.5 mm plug (SK473's captive plug into the Vantec jack) | **No** |
| SK473 → actuator | speaker wire soldered to the amp's **output pads** | **Yes** |
| amp ← power | USB 5 V (from hub or bus) | (power only) |
| laptop → Vantec | USB data | (no audio wire) |

The amp is the translator: **3.5 mm line-level in → amplified power out on bare wire.** Bare wire never touches the Vantec; the Vantec only ever sees 3.5 mm plugs.

The 3.5 mm cable shares a signal ground between laptop and amp, but it carries only line-level current and the amp's 5 V rail is isolated from the signal lines — so amp power cannot flow back into the laptop (see [06-safety.md](06-safety.md)). This is bounded isolation, not a total absence of any DC path.

## Why two devices per "DAC + power"

- **Vantec (audio):** turns USB into the many analog channels. 1 Vantec = 4 stereo jacks = 8 ch = 4 SK473. We use **2 Vantecs** (V1 = ch 1–8, V2 = ch 9–12); V3 is a spare.
- **Hub / bank (power):** only delivers 5 V to the amps. Carries no audio.
These are independent layers; a dongle is a fallback for the *Vantec* (audio), never the hub (power).

## Brain placement

- **Primary: laptop** (M4 Pro 16" 48 GB; M3 MBP 14" dev). It runs the browser (vision + UI) + Python (audio + model + 12-ch haptic out) and drives the Vantecs over USB.
- **Raspberry Pi 5:** owned but **cut from the critical path** — the laptop does everything. The ESP32 is **not** in the audio path either (sensor work only).

## Channel budget

12 amp channels (6 SK473). Mapped as **6 string (back) + 6 fret-zone (torso)**. Vantec capacity and driver count exceed this; amps are the limit. The 2 reserved upper-back zones (old ch 13–14) are dropped.

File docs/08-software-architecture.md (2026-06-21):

# Software architecture

Runs on the **laptop** (the Raspberry Pi is owned but cut from the critical path). Split across two processes: the **browser** owns vision + UI (camera, MediaPipe, ArUco, AR, viz) and **Python** owns audio + the model + the **haptic renderer** that drives the **12 channels**. They sync over **one localhost WebSocket** (vision features flow browser→Python, timestamped). Works on **any song** — no per-song hardcoding. See [`../truth.md`](../truth.md) §2 for the locked split.

## Pipeline

```
INPUTS:  mic audio (Python)     webcam (browser: fretboard + hand)

- AUDIO branch  [PYTHON] --------------------------------------
 1. F0 / transcription       [ML]  -> notes + onsets + durations   (pYIN/YIN live; CREPE offline)
 2. Dynamics                 [det] -> RMS -> volume
 3. Technique/quality model  [ML]  -> {clean|buzz|muted|dead|ghost}  <- pressure-adequacy from timbre
       features: harmonic-to-noise ratio, inharmonicity, spectral centroid/flux,
                 attack/decay envelope, broadband-buzz energy   (librosa)

- VISION branch  [BROWSER] -----------------------------------
 4. Hand pose                [ML]  -> MediaPipe 21 landmarks/hand -> fingertips + which finger
 5. Fretboard geometry       [det] -> OpenCV + ArUco marker -> homography
       -> map fingertips to (string, fret) + placement vs fret-wire (coarse)
       (vision features stream browser -> Python over the localhost WebSocket, timestamped)

- FUSION [rules + light ML]  [PYTHON] ------------------------
 6. time-align audio onsets <-> vision frames
 7. reconcile: vision resolves WHICH string/fret made a pitch; audio confirms it sounded + quality
       buzz + finger-too-far-from-wire -> placement fault
       dead/weak + finger-present      -> pressure fault
       clean + matches target          -> correct
 8. confidence = cross-modal agreement

- REFERENCE DIFF ----------------------------------------------
 9. target (MIDI/tab, or basic-pitch on the recording) vs played
       discrepancies on: note | fret/finger choice | timing | dynamics | technique

- OUTPUTS -----------------------------------------------------
10. haptic renderer [PYTHON] -> 12 channels (target + correctness pulses)
11. LLM coach (Anthropic) [phrase-level] -> natural-language feedback
12. on-screen fretboard map [BROWSER] (precise fret/finger/placement/pressure/volume)
13. Redis [optional] -> per-user mistake history, adaptive difficulty, vector-search past mistakes
```

### Two timescales
- **Per note (real-time, deterministic):** instant haptic flag + screen highlight. The LLM is too slow per-note.
- **Per phrase (LLM coach):** structured error log → prioritized, encouraging advice ("ring finger muted the G — press just behind fret 3").

### "Any song"
The engine is song-agnostic. Two modes:
- **Free play:** transcribe whatever is played → render + map. No reference.
- **Coach vs a song:** auto-generate the target (fetch MIDI/tab, or run basic-pitch on the original recording), then diff. New song = no code change. Accuracy tracks musical complexity; vision cross-checks audio on chords.

## Haptic renderer

```
note event (string, fret, velocity, t)
   -> encoder (docs/07): (string -> back ch) + (fret -> torso zone + intensity)
   -> synth: ~160 Hz burst, 30-80 ms, amp = velocity (tune on-body; was 200-250 Hz pre-teardown)
   -> ALSA: write buffer to (card, channel) per config/channel_map.json
```

### ALSA / multichannel
- **2 Vantec cards used** (V1 = ch 1–8, V2 = ch 9–12; V3 spare), each an 8-channel device. `aplay -l` lists them.
- The renderer holds a logical-channel → (card, channel) map ([config/channel_map.json](../config/channel_map.json)).
- Slight clock drift between cards is fine for haptics (not phase-critical for pulses).
- ⚠️ The CM6206 cards enumerate with the same name and reorder across reboots — **bind by `/dev/snd/by-id`, not `hw:0/1/2`**, and verify in-card channel order with `speaker-test -c8` on each Vantec. See [`../truth.md`](../truth.md) §3.2.

## Suggested layout
```
software/ai/        transcription, vision, fusion, coach
software/haptic/    encoder, synth, alsa_out
config/             channel_map.json, encoding.json
```

## Stack
`basic-pitch`, `mediapipe`, `opencv-python` (+ ArUco), `librosa`/`aubio`/`crepe`, `sounddevice`/`pyalsaaudio`, `numpy`/`scipy`, Anthropic SDK, optional `redis`.

## Compute placement (be honest in the demo)
Everything runs on the laptop: vision + UI in the browser, audio + model + 12-ch haptic out in Python, over one localhost WebSocket. The Raspberry Pi is owned but cut from the critical path. Pre-process songs offline for the polished run; light real-time pitch (YIN/pYIN live, CREPE offline) for the live-guitar wow. State which is which.

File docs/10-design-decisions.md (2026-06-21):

# Design decisions (why, and what we rejected)

The repo says *what* to build. This says *why*, so nobody re-opens a settled question or repeats a dead end.

## Amplification — gut SK473 boards (PAM8403)
**Chosen:** harvest the amp board from cheap powered speakers (SK473), one per 2 channels.
**Why:** haptic actuators need only ~1 W/ch; small class-D amps are the right size, in stock, cheap. Powered speaker = a free amp in a box.
**Rejected:**
- **Car amp** — 50–100 W/ch is massive overkill, needs a 12 V supply (ATX), adds frying risk + weight, and the "find one tonight" hunt ate hours. Wrong tool for 1 W haptics.
- **Raspberry Pi DigiAMP+** — only 2 channels, and it rides the Pi's I2S bus (one stereo stream); stacking 3 gives 3 copies of the same 2 channels, not 6. Hardware-bus dead end.
- **MAX98357A** — out of stock; would have needed channel-select resistors. Abandoned, which is why **no resistor is in the audio path**.

## Audio source / channels — USB 7.1 (Vantec NBA-200U, CM6206)
**Chosen:** 3× USB 7.1 cards owned, **2 used** (V1 = ch 1–8, V2 = ch 9–12; V3 spare) = the 12 analog channels we need.
**Why:** one Vantec = 4 stereo jacks = 8 channels = feeds 4 SK473. Far fewer cables/devices than a pile of stereo dongles; fits the laptop's ports; CM6206 does real 8-ch on Linux.
**Rejected / fallback:** ~9 separate USB stereo **dongles** (Sabrent AU-MMSA) — works but cable sprawl; kept as a **per-channel fallback** if a Vantec jack won't map.

## Bass — dropped (was Logitech Z313)
**Chosen:** no dedicated bass node. The 12-driver array carries the whole concept.
**Why:** once the project became *note coaching*, "which note/string/fret" matters, not chest-thump bass. A subwoofer also needs its enclosure (can't wear it bare) and its own bigger amp. Out of scope.
**Rejected:**
- **Z313 sub** — bought, then dropped. Return it.
- **Harvesting a transducer from a Joy-Con / phone / controller** — those are **LRA/ERM** (single-frequency rumble buzzers), need a special haptic driver IC, and can't be driven from an audio amp. Wrong technology. Only **voice-coil exciters / shakers / woofers** are audio-drivable; the one MicroCenter sells (Dayton BST-2) wasn't needed once bass left scope.

## Encoding — location + timing, not frequency
**Chosen:** a note = (string → back actuator) + (fret → torso zone + intensity), as a short ~160 Hz pulse (tune on-body; 200–250 Hz was a pre-teardown estimate).
**Why:** skin can't discriminate pitch (vibrotactile Weber ~25%; ~5–9 distinguishable buzz-pitches total). A one-fret frequency change is unfeelable *as frequency*. But skin resolves *location* and *timing* well, so we render pitch there instead. See [12-perception-references.md](12-perception-references.md).
**Rejected:** mapping pitch → one speaker's vibration frequency (the obvious first idea) — physically unfeelable.

## Channel count — 12
**Chosen:** 12 = 6 strings (back) + 6 fret-zones (torso); 12 frets map onto the 6 zones via zone + intensity.
**Why:** we use 6 SK473 = 12 amp channels; that's the binding constraint. It's also within skin's spatial resolution on the back+torso, so 12 distinct sites is already near the useful ceiling. The 2 reserved upper-back zones (old ch 13–14) are **dropped**.

## Brain — laptop (Pi cut from critical path)
**Chosen:** the laptop (M4 Pro 16" 48 GB) runs the full stack — browser (vision + UI) + Python (audio + model + 12-ch haptic out) — and drives the Vantecs.
**Why:** a Pi 5 can't run MediaPipe + transcription + LLM + 12-ch audio in real time, and the architecture put MediaPipe in the browser anyway.
**Pi role:** owned but **cut from the critical path** — the laptop does everything. The ESP32 is **not** in the audio path either.

## Pressure — inferred from timbre, no sensor
**Chosen:** detect pressure *adequacy* from audio (buzz / dead-note / clean), not a force sensor.
**Why:** an FSR gives true Newtons but adds hardware; the timbre signal ("does it buzz / choke?") is what actually matters for coaching, and a learned model reads it. Framed honestly as **pressure adequacy**, not measured force.
**Rejected:** FSR-on-ESP32 — good for a v2 with real ground-truth, dropped to keep scope tight.

## Power — two modes
**Chosen:** Mode A wall (10A/50W hub, guaranteed) + Mode B cordless (Anker 737 + solder bus, split 3/2/2).
**Why:** the hub trivially powers all amps with margin for the reliable judged run; the bank gives the portability wow. See [03-power.md](03-power.md) for the per-bus math and the USB-C CC-resistor requirement.

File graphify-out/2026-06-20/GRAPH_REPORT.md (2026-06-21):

# Graph Report - tactus  (2026-06-20)

## Corpus Check
- 58 files · ~1,003,676 words
- Verdict: corpus is large enough that graph structure adds value.

## Summary
- 1775 nodes · 4007 edges · 114 communities (105 shown, 9 thin omitted)
- Extraction: 81% EXTRACTED · 19% INFERRED · 0% AMBIGUOUS · INFERRED: 760 edges (avg confidence: 0.8)
- Token cost: 0 input · 0 output

## Graph Freshness
- Built from commit: `a1f4128d`
- Run `git rev-parse HEAD` and compare to check if the graph is stale.
- Run `graphify update .` after code changes (no API cost).

## Community Hubs (Navigation)
- [[_COMMUNITY_AI Engine & Coaching Core|AI Engine & Coaching Core]]
- [[_COMMUNITY_Project Overview & Hardware BOM|Project Overview & Hardware BOM]]
- [[_COMMUNITY_ML Training & Buzz Data Pipeline|ML Training & Buzz Data Pipeline]]
- [[_COMMUNITY_Assembly Stages & Design Decisions|Assembly Stages & Design Decisions]]
- [[_COMMUNITY_Software Modules & Dependencies|Software Modules & Dependencies]]
- [[_COMMUNITY_Haptic Perception Research & Prior Art|Haptic Perception Research & Prior Art]]
- [[_COMMUNITY_Enclosure CAD (box + lid)|Enclosure CAD (box + lid)]]
- [[_COMMUNITY_Actuator Puck Coupling CAD|Actuator Puck Coupling CAD]]
- [[_COMMUNITY_Enclosure Build Script (Python)|Enclosure Build Script (Python)]]
- [[_COMMUNITY_Channel Map (strings + fret-zones)|Channel Map (strings + fret-zones)]]
- [[_COMMUNITY_Enclosure CAD Renders|Enclosure CAD Renders]]
- [[_COMMUNITY_Body-Plate & Driver Socket CAD|Body-Plate & Driver Socket CAD]]
- [[_COMMUNITY_Chord Rendering & AR Interface|Chord Rendering & AR Interface]]
- [[_COMMUNITY_Multimodal Vision & Buzz Modeling|Multimodal Vision & Buzz Modeling]]
- [[_COMMUNITY_Power, Soldering & Safety|Power, Soldering & Safety]]
- [[_COMMUNITY_Audio Wiring Connections|Audio Wiring Connections]]
- [[_COMMUNITY_System Components Overview|System Components Overview]]
- [[_COMMUNITY_Power Mode A (Wall)|Power Mode A (Wall)]]
- [[_COMMUNITY_Power Mode B (Cordless)|Power Mode B (Cordless)]]
- [[_COMMUNITY_Open Questions & To-Do|Open Questions & To-Do]]
- [[_COMMUNITY_Power Cradle CAD|Power Cradle CAD]]
- [[_COMMUNITY_Vantec USB Audio Path|Vantec USB Audio Path]]
- [[_COMMUNITY_Community 23|Community 23]]
- [[_COMMUNITY_Community 24|Community 24]]
- [[_COMMUNITY_Community 25|Community 25]]
- [[_COMMUNITY_Community 26|Community 26]]
- [[_COMMUNITY_Community 27|Community 27]]
- [[_COMMUNITY_Community 28|Community 28]]
- [[_COMMUNITY_Community 29|Community 29]]
- [[_COMMUNITY_Community 30|Community 30]]
- [[_COMMUNITY_Community 31|Community 31]]
- [[_COMMUNITY_Community 32|Community 32]]
- [[_COMMUNITY_Community 33|Community 33]]
- [[_COMMUNITY_Community 34|Community 34]]
- [[_COMMUNITY_Community 35|Community 35]]
- [[_COMMUNITY_Community 36|Community 36]]
- [[_COMMUNITY_Community 37|Community 37]]
- [[_COMMUNITY_Community 38|Community 38]]
- [[_COMMUNITY_Community 39|Community 39]]
- [[_COMMUNITY_Community 40|Community 40]]
- [[_COMMUNITY_Community 41|Community 41]]
- [[_COMMUNITY_Community 42|Community 42]]
- [[_COMMUNITY_Community 43|Community 43]]
- [[_COMMUNITY_Community 44|Community 44]]
- [[_COMMUNITY_Community 45|Community 45]]
- [[_COMMUNITY_Community 46|Community 46]]
- [[_COMMUNITY_Community 47|Community 47]]
- [[_COMMUNITY_Community 48|Community 48]]
- [[_COMMUNITY_Community 49|Community 49]]
- [[_COMMUNITY_Community 50|Community 50]]
- [[_COMMUNITY_Community 51|Community 51]]
- [[_COMMUNITY_Community 52|Community 52]]
- [[_COMMUNITY_Community 53|Community 53]]
- [[_COMMUNITY_Community 54|Community 54]]
- [[_COMMUNITY_Community 55|Community 55]]
- [[_COMMUNITY_Community 56|Community 56]]
- [[_COMMUNITY_Community 57|Community 57]]
- [[_COMMUNITY_Community 58|Community 58]]
- [[_COMMUNITY_Community 59|Community 59]]
- [[_COMMUNITY_Community 60|Community 60]]
- [[_COMMUNITY_Community 61|Community 61]]
- [[_COMMUNITY_Community 62|Community 62]]
- [[_COMMUNITY_Community 63|Community 63]]
- [[_COMMUNITY_Community 64|Community 64]]
- [[_COMMUNITY_Community 65|Community 65]]
- [[_COMMUNITY_Community 66|Community 66]]
- [[_COMMUNITY_Community 67|Community 67]]
- [[_COMMUNITY_Community 68|Community 68]]
- [[_COMMUNITY_Community 69|Community 69]]
- [[_COMMUNITY_Community 70|Community 70]]
- [[_COMMUNITY_Community 71|Community 71]]
- [[_COMMUNITY_Community 72|Community 72]]
- [[_COMMUNITY_Community 73|Community 73]]
- [[_COMMUNITY_Community 74|Community 74]]
- [[_COMMUNITY_Community 75|Community 75]]
- [[_COMMUNITY_Community 76|Community 76]]
- [[_COMMUNITY_Community 77|Community 77]]
- [[_COMMUNITY_Community 78|Community 78]]
- [[_COMMUNITY_Community 79|Community 79]]
- [[_COMMUNITY_Community 80|Community 80]]
- [[_COMMUNITY_Community 81|Community 81]]
- [[_COMMUNITY_Community 82|Community 82]]
- [[_COMMUNITY_Community 83|Community 83]]
- [[_COMMUNITY_Community 84|Community 84]]
- [[_COMMUNITY_Community 85|Community 85]]
- [[_COMMUNITY_Community 86|Community 86]]
- [[_COMMUNITY_Community 87|Community 87]]
- [[_COMMUNITY_Community 88|Community 88]]
- [[_COMMUNITY_Community 89|Community 89]]
- [[_COMMUNITY_Community 90|Community 90]]
- [[_COMMUNITY_Community 91|Community 91]]
- [[_COMMUNITY_Community 92|Community 92]]
- [[_COMMUNITY_Community 93|Community 93]]
- [[_COMMUNITY_Community 94|Community 94]]
- [[_COMMUNITY_Community 95|Community 95]]
- [[_COMMUNITY_Community 96|Community 96]]
- [[_COMMUNITY_Community 97|Community 97]]
- [[_COMMUNITY_Community 98|Community 98]]
- [[_COMMUNITY_Community 99|Community 99]]
- [[_COMMUNITY_Community 100|Community 100]]
- [[_COMMUNITY_Community 101|Community 101]]
- [[_COMMUNITY_Community 102|Community 102]]
- [[_COMMUNITY_Community 103|Community 103]]
- [[_COMMUNITY_Community 104|Community 104]]
- [[_COMMUNITY_Community 105|Community 105]]
- [[_COMMUNITY_Community 106|Community 106]]
- [[_COMMUNITY_Community 107|Community 107]]
- [[_COMMUNITY_Community 108|Community 108]]
- [[_COMMUNITY_Community 109|Community 109]]
- [[_COMMUNITY_Community 110|Community 110]]
- [[_COMMUNITY_Community 111|Community 111]]

## God Nodes (most connected - your core abstractions)
1. `$_()` - 953 edges
2. `push()` - 64 edges
3. `$E()` - 54 edges
4. `get()` - 52 edges
5. `forEach()` - 40 edges
6. `constructor()` - 34 edges
7. `_T()` - 33 edges
8. `render()` - 31 edges
9. `t()` - 28 edges
10. `Yd()` - 28 edges

## Surprising Connections (you probably didn't know these)
- `Dropped heavy bass shakers (weight/physics)` --rationale_for--> `KHD 3 Ohm / 5 W driver (the actuator, de-housed from SK473)`  [INFERRED]
  CHANGELOG.md → docs/01-bill-of-materials.md
- `MockEngine (WebSocket message emitter)` --semantically_similar_to--> `LLM Coach Loop`  [INFERRED] [semantically similar]
  web/index.html → software/README.md
- `Vision branch (MediaPipe hand pose + ArUco fretboard homography)` --conceptually_related_to--> `LEARN mode (Rocksmith for Deaf players)`  [INFERRED]
  docs/08-software-architecture.md → README.md
- `Build-tonight TL;DR` --semantically_similar_to--> `Chord / strum rendering (sequential sweep vs gestalt)`  [INFERRED] [semantically similar]
  docs/00-start-here.md → docs/07-haptic-encoding.md
- `Haptic renderer` --references--> `12-channel haptic body map (6 back strings + 6 torso fret-zones)`  [EXTRACTED]
  docs/08-software-architecture.md → README.md

## Import Cycles
- None detected.

## Hyperedges (group relationships)
- **Five Mechanisms That Turn a Cluster Into Advice** — docs_23_data_and_cluster_semantics_cluster_to_advice, docs_23_data_and_cluster_semantics_lda_eigenvector, docs_23_data_and_cluster_semantics_medoid_prototype, docs_23_data_and_cluster_semantics_causal_clean_fault_pair, docs_23_data_and_cluster_semantics_heldout_validation [EXTRACTED 1.00]
- **Labeled-by-Construction Capture Flow (Prompt → Run → Segment → Manifest)** — docs_24_data_collection_protocol_prompt_is_label, docs_24_data_collection_protocol_prompted_runs, docs_24_data_collection_protocol_onset_segmentation, docs_24_data_collection_protocol_metadata_schema, docs_24_data_collection_protocol_file_convention [EXTRACTED 0.85]
- **Separability Study Pipeline (Features → PCA → LDA → LOPO d′)** — docs_23_data_and_cluster_semantics_feature_vector, docs_23_data_and_cluster_semantics_lda_eigenvector, docs_23_data_and_cluster_semantics_lopo_training, truth_separability_study [INFERRED 0.85]

## Communities (114 total, 9 thin omitted)

### Community 0 - "AI Engine & Coaching Core"
Cohesion: 0.06
Nodes (37): AI Where Unsolved, Deterministic Where Solved, Buzz Inverse (Pressure from Sound), Deterministic Renderer (Encoder + Pulse Synth), Fusion Perception Model (Vision + Audio), Any-Song Generalizability (Free Play + Coach Mode), LLM Coach (Anthropic, Phrase-Level), MediaPipe Hand Pose + ArUco Fretboard Homography, Redis Coach Memory (Mistake History, Vector Search) (+29 more)

### Community 1 - "Project Overview & Hardware BOM"
Cohesion: 0.14
Nodes (15): USB-C 5.1 kohm CC resistor requirement, Per-bus load math (3/2/2 split), Strain relief (heat-shrink + hot-glue blob), Bounded isolation (signal ground vs 5V rail), Wire weight problem (18 AWG levers joints), Audio branch (F0 / transcription, dynamics, technique model), Fusion (time-align + reconcile vision vs audio, cross-modal confidence), LLM coach (Anthropic, phrase-level feedback) (+7 more)

### Community 2 - "ML Training & Buzz Data Pipeline"
Cohesion: 0.19
Nodes (16): Pluck Confound in Buzz Inverse (D1), Bayesian Fusion (Likelihoods + Adaptive Theory Prior), Causal Clean/Fault Pairs (Proves the Fix), How a Cluster Becomes Advice (Epistemics), Contrastive Multimodal Embedding (Cut-First Stretch), Engineered Feature Vector (~40-60 Dims, Audio + Vision), Held-Out Validation (Confusion Matrix = Permission Slip), Hybrid Scheme (Supervised Backbone + Gated Discovery) (+8 more)

### Community 3 - "Assembly Stages & Design Decisions"
Cohesion: 0.25
Nodes (8): Decision: encode note as location + timing, not frequency, Perception References (Vibrotactile Findings), Funneling / sensory saltation (separate simultaneous cues across regions), Neosensory Buzz (Eagleman) — 4 wrist actuators, learnable code, Precedents: Model Human Cochlea, SoundShirt, Braille / the vOICe, Temporal acuity ~5ms gap detection (skin's strength) -> sharp pulses + sweep, Two-point discrimination (fingertip 2-4mm, forearm 35-40mm, torso/back 40-50mm), Vibrotactile frequency: peak 200-300 Hz, Weber ~20-30% (poor pitch)

### Community 4 - "Software Modules & Dependencies"
Cohesion: 0.08
Nodes (30): ai/ Module (transcription, vision, fusion, LLM coach), ALSA Multichannel Write (3 Vantec / 8ch), Bring-up order, LLM Coach Loop, haptic/ Module (encoder, synth, alsa_out), Honest-Scoping Rules (coarse placement, no pressure sensor), Install, software (+22 more)

### Community 5 - "Haptic Perception Research & Prior Art"
Cohesion: 0.08
Nodes (27): Audio Branch (pYIN/YIN live, CREPE/basic-pitch offline), Audio to Haptic ML/DSP Research Brief, Haptic-Score Idea Cut (Direct Signal to Vibration Now), Information Transfer Evaluation (IT bits, d-prime), Learned Model Prior Art (HapticGen, HapticLDM, Sound2Hap), MPEG-I Part 31 Haptics Coding (ISO/IEC 23090-31:2025), Pitch Engines (CREPE, pYIN, basic-pitch, SwiftF0), Psychohaptic Mapping (Warp Not Transpose, Mel/Bark/ERB) (+19 more)

### Community 6 - "Enclosure CAD (box + lid)"
Cohesion: 0.02
Nodes (37): $_(), _0(), _1(), addChild(), Bb(), by(), countEventListeners(), d5() (+29 more)

### Community 7 - "Actuator Puck Coupling CAD"
Cohesion: 0.07
Nodes (34): actuator_puck.scad — Ø52 driver coupling puck (cup + button), button() — domed contact button bonded to the dust cap, cup() — rigid coupling cup that grips the Ø52 driver frame, box(), button(), cup(), cyly(), cylz() (+26 more)

### Community 8 - "Enclosure Build Script (Python)"
Cohesion: 0.11
Nodes (32): tactus_box.scad — main electronics enclosure (brain-pack), base() — enclosure base shell + mounts + vents, cable_anchors() — internal zip-tie posts at wire wall, comb_ledge() — external strain-relief comb on +Y wall, floor_vents() — floor slot grid for airflow, gland_holes() — laptop-side USB + power glands (-Y wall), lid() — enclosure lid plate, lid_bosses() — corner screw bosses (base side) (+24 more)

### Community 9 - "Channel Map (strings + fret-zones)"
Cohesion: 0.13
Nodes (15): Back ch5 — A string site, Back ch2 — B string site, Back ch4 — D string site, Back ch3 — G string site, Back ch1 — high E string site, Back ch6 — low E string site, BACK — 6 strings (ch 1–6), config/channel_map.json (source of truth) (+7 more)

### Community 10 - "Enclosure CAD Renders"
Cohesion: 0.18
Nodes (14): Enclosure base box (open top, blue CAD preview), Corner screw bosses on base, Enclosure lid, interior view (blue CAD preview), Triangulated rib / support structure on lid underside, Corner screw holes on lid, Internal partitions / component mounting structure, Rectangular port window cutout in base side wall, Row of circular wire/vent holes (Ø16 mm, USB-A pass-through) (+6 more)

### Community 11 - "Body-Plate & Driver Socket CAD"
Cohesion: 0.26
Nodes (14): tactus_chest_plate.scad — body-contoured plate holding 6 string drivers, bore_at(z) — through-hole so the cone/button reaches skin, shell() — curved torso-cylinder shell panel between z_lo..z_hi, socket_at(z) — places a driver_socket on the inner face at height z, strap_slots(z_lo, z_hi) — edge slots to lash onto the laser-tag vest, tile(z_lo, z_hi) — one print tile (shell + sockets - bores - slots), tile_abs(z_lo, z_hi) — print tile built at absolute z coordinates, tactus_node_mount.scad — per-node split-clamp + telescoping driver mount (+6 more)

### Community 12 - "Chord Rendering & AR Interface"
Cohesion: 0.18
Nodes (13): Chord onset encodes how it was struck (strum sweep / pluck bloom / arpeggio), Chord, Sustain & Percussive Rendering, Fret-zones carry chord SHAPE (pulsed in sync) + root emphasis, GSTACK eng-review report (PAUSED; B1-B7 open, 3 critical silent-failure gates), Percussive & muted hits (sharp pop across motors; muted strings don't fire), Renderer input: per-string (onset, pitch->string/fret, envelope, decay) stream, Sustain = envelope-modulated looped shimmer (LOCKED), One phase-locked signal coherence (screen + body + sound from one stream) (+5 more)

### Community 13 - "Multimodal Vision & Buzz Modeling"
Cohesion: 0.10
Nodes (22): 0. The thesis — AI where it's *unsolved*, determinism where it's *solved*, 17 — The AI core: audio + vision → high-granularity (string, fret, finger, quality) → targeted feedback, 1. High-granularity POSITION — why fusion beats either modality alone, 1a. Audio branch (what + how-clean), 1b. Vision branch (where + which finger) — runs in the **browser**, 1c. Fusion (the part that's a real contribution, not a wrapper), 2. High-granularity TARGETED FEEDBACK — three axes, each a measured signal, 3. The rigor moves (cheap, high-credibility — have these ready at the table) (+14 more)

### Community 14 - "Power, Soldering & Safety"
Cohesion: 0.15
Nodes (16): Build-tonight TL;DR, Pick your lane, Start here (teammates), Status, What tactus is (30 seconds), AudioVox 18 AWG speaker wire (the only body wire), LEO SALES 40mm speakers (spare actuators), Raspberry Pi 5 (owned, cut from critical path) (+8 more)

### Community 15 - "Audio Wiring Connections"
Cohesion: 0.29
Nodes (7): 2 KHD Ø52 mm drivers (de-house → body), ⛔ NEVER connect (forbidden wiring rules), Powered hub / Anker 737 (5 V source, Mode A/B), SK473 captive 3.5 mm plug (box's 2 channels), SK473 board (L/R out, inside master speaker), SK473 captive USB-A lead (powers the PAM8403), Vantec output jack (1 of 4 stereo jacks)

### Community 16 - "System Components Overview"
Cohesion: 0.29
Nodes (7): config/channel_map.json (source of truth), 12× KHD Ø52 mm 4Ω drivers (6 back + 6 torso), 🎸 guitar · 📷 webcam · 🎤 mic (inputs), LAPTOP — AI brain (transcribe · fuse · LLM coach · AR/UI), POWER · 5 V separate (Mode A hub / Mode B Anker 737), 6× SK473 box — PAM8403 amps (used intact), 2× Vantec NBA-200U 7.1 (CM6206) audio source

### Community 17 - "Power Mode A (Wall)"
Cohesion: 0.33
Nodes (6): 10-port powered hub (~50 W AC, data + 5 V), Laptop (upstream USB data), MODE A — WALL (judged demo), 6× SK473 (USB-A — 5 V only), 3× Vantec (data + their 5 V), 🔌 Wall outlet

### Community 18 - "Power Mode B (Cordless)"
Cohesion: 0.33
Nodes (6): Anker 737 battery (24 000 mAh · 140 W), Laptop (Mode B data source), 6× SK473 USB-A (5 V), 3× Vantec (straight to laptop USB), MODE B — CORDLESS (walk-around), PD-powered USB-A hub

### Community 20 - "Open Questions & To-Do"
Cohesion: 0.67
Nodes (3): Open: ALSA Enumeration Reorder Across Reboots, Open: KHD Driver Diameter Un-measured (spk_dia placeholder), Open Questions + To-Do

### Community 23 - "Community 23"
Cohesion: 0.05
Nodes (72): ad(), Ah(), aP(), B1(), Bl(), build(), _c(), ch() (+64 more)

### Community 24 - "Community 24"
Cohesion: 0.06
Nodes (53): addEventListener(), addListeners(), addVariantChild(), cancel(), cancelPress(), checkPressEnd(), clear(), clearAnimation() (+45 more)

### Community 25 - "Community 25"
Cohesion: 0.07
Nodes (35): $e(), Ee(), et(), J(), je(), Le(), ne(), Ue() (+27 more)

### Community 26 - "Community 26"
Cohesion: 0.07
Nodes (39): addFont(), addFontAlias(), addFontFamily(), callObservers(), createFontFamily(), createSelector(), defaultFont(), exitAnimationComplete() (+31 more)

### Community 27 - "Community 27"
Cohesion: 0.07
Nodes (38): av(), CS(), cy(), DF(), ev(), Ey(), getVelocity(), hp() (+30 more)

### Community 28 - "Community 28"
Cohesion: 0.11
Nodes (34): $a(), a1(), Ba(), Cb(), componentDidMount(), componentWillUnmount(), d1(), Db() (+26 more)

### Community 29 - "Community 29"
Cohesion: 0.06
Nodes (34): A2(), b2(), cA(), CM(), collectLayout(), dT(), E2(), ET() (+26 more)

### Community 30 - "Community 30"
Cohesion: 0.08
Nodes (28): b5(), bT(), Fv(), getStackState(), gP(), h5(), If(), interpolate() (+20 more)

### Community 31 - "Community 31"
Cohesion: 0.08
Nodes (27): $2(), canRenderOptimizedCanvasImage(), cP(), E1(), ew(), g2(), hM(), iL() (+19 more)

### Community 32 - "Community 32"
Cohesion: 0.09
Nodes (27): _3(), bw(), c1(), CE(), EM(), Fo(), gr(), gw() (+19 more)

### Community 33 - "Community 33"
Cohesion: 0.08
Nodes (27): Bn(), Cc(), Dy(), e0(), E8(), f1(), hA(), inspect() (+19 more)

### Community 34 - "Community 34"
Cohesion: 0.11
Nodes (26): Ab(), add(), Af(), Eb(), Ef(), Gb(), getDefaultTransition(), getState() (+18 more)

### Community 35 - "Community 35"
Cohesion: 0.09
Nodes (26): aT(), Bg(), bv(), dE(), fP(), getBaseTarget(), getBaseTargetFromProps(), hE() (+18 more)

### Community 36 - "Community 36"
Cohesion: 0.08
Nodes (25): dependencies, next, openai, @openuidev/react-headless, @openuidev/react-lang, @openuidev/react-ui, react, react-dom (+17 more)

### Community 37 - "Community 37"
Cohesion: 0.14
Nodes (25): addFrameTask(), _b(), canEvaluate(), D_(), ex(), f0(), Ff(), flip() (+17 more)

### Community 38 - "Community 38"
Cohesion: 0.11
Nodes (23): applyWillChange(), bM(), cV(), e4(), getOverrideText(), gg(), gM(), Iu() (+15 more)

### Community 39 - "Community 39"
Cohesion: 0.13
Nodes (19): ALSA logical-channel routing (card, channel -> jack -> amp -> actuator), 2-axis code (string -> back actuator + fret -> torso zone + intensity), Chord / strum rendering (sequential sweep vs gestalt), Chords / strums, Encoding design rules (separate spatially, sharp pulses, structured map), Design rules (or it turns to mush), Fret → 6 torso zones (12 frets onto 12 channels), Fret -> torso zone + intensity table (12 frets on 6 zones) (+11 more)

### Community 40 - "Community 40"
Cohesion: 0.09
Nodes (22): 0. What is true vs what is stale (read first), 1. Direction & goal, 2. Locked software architecture, 3.1 Compute / brain, 3.2 Audio-out chain & channel map (12 channels), 3.3 Drivers & body coupling, 3.4 Amps (PAM8403, filterless Class-D, BTL), 3.5 Power (+14 more)

### Community 41 - "Community 41"
Cohesion: 0.15
Nodes (21): _4(), a4(), b4(), c4(), d4(), Dn(), Ds(), f4() (+13 more)

### Community 42 - "Community 42"
Cohesion: 0.16
Nodes (21): b0(), bc(), Bh(), componentDidCatch(), di(), Hh(), Jn(), l1() (+13 more)

### Community 43 - "Community 43"
Cohesion: 0.10
Nodes (21): customTransition(), e5(), executeQueryPlan(), fade(), instant(), isSameEventTransition(), J4(), Lo() (+13 more)

### Community 44 - "Community 44"
Cohesion: 0.13
Nodes (21): dc(), Eh(), _g(), hc(), HR(), jx(), kb(), l3() (+13 more)

### Community 45 - "Community 45"
Cohesion: 0.10
Nodes (19): 19 — Sponsor & prize alignment (refined to the as-built rig), Action items, Arize / Phoenix (Trace + Eval Models), Annapurna / AWS Trainium (Contrastive Embedding), One Coherent Sponsor Story (No Contortion), Deepgram (Hands-Free Voice Control), Dropped — do NOT apply or build for, QNX Dropped (Needed the Cut Pi Real-Time Loop) (+11 more)
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

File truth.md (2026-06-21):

# truth.md — Tactus single source of truth

> **This document is canonical.** If any other doc disagrees with this one, **this wins** and the other doc is stale — fix it. This is the human source of truth for *direction* and *hardware*; the machine source of truth for channel routing is [`config/channel_map.json`](config/channel_map.json). Last reconciled to the **Jun 20 live teardown** (the as-built rig), the MicroCenter receipt `195-PO-419168`
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

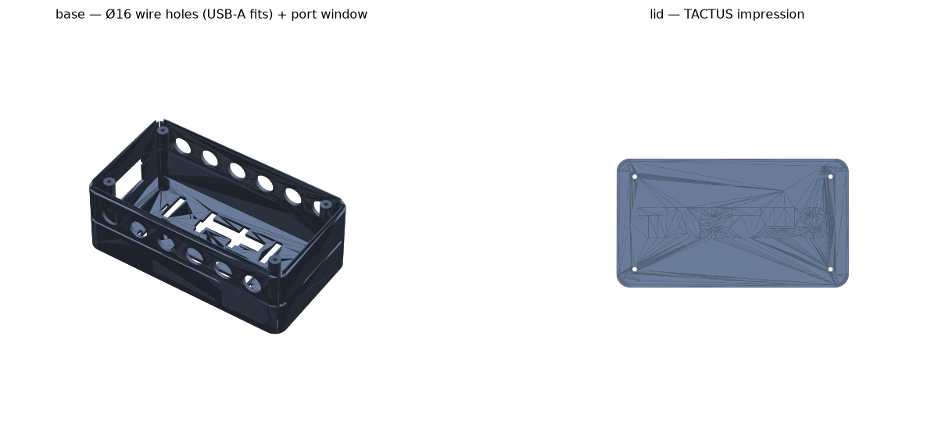
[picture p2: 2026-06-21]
cad/enclosure_preview.png

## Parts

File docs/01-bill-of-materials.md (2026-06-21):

# Bill of materials

Reconciled to MicroCenter receipt ref `195-PO-419168`, 2026-06-19, Santa Clara.

## Owned now

### Audio source (DAC / channels)
| Part | SKU | Qty | Notes |
|---|---|---|---|
| Vantec NBA-200U USB 7.1 audio adapter | 080325 | 3 | CM6206 chipset. 4 stereo 3.5mm output jacks each = 8 ch. **2 used (V1+V2 → ch 1–12), V3 spare** |

### Amplifiers
| Part | SKU | Qty | Notes |
|---|---|---|---|
| IPSG SK473 6W powered speaker | 593038 | 6 (+1 prior = 7) | **6 used.** Gutted for its PAM8403 board + its 2 KHD 3 Ω/5 W drivers. 2 ch each = **12 channels** ← binding constraint |

### Actuators (the SK473's own KHD drivers)
| Part | SKU | Qty | Role |
|---|---|---|---|
| KHD 3 Ω/5 W driver (de-housed from the SK473, SKU 593038 above) | — | 6 boxes × 2 = **12** | **the actuators** — mass-y, punchy; factory-matched to the PAM8403, 3 Ω safe at felt level. Diameter TBD — measure the driver, set `spk_dia`, re-render. |
| LEO SALES 3W 40mm speaker (4-pack) | 714816 | 3 packs = 12 | **spare** (was fret-zone actuators) |
| LEO SALES 2W 40mm speaker (6-pack) | 714808 | 2 packs = 12 | **spare** (was string actuators) |

12 KHD drivers used (all 12 channels). The 24 LEO 40 mm speakers are now **spares**.

### Power
| Part | SKU | Qty | Notes |
|---|---|---|---|
| IPSG USB-A 3.0 10-port hub, **10A (50W) AC adapter** | 885194 | 1 | Wall-mode (Mode A) amp power. 50W ≫ real peak ~2–3 W |
| Anker 737 PowerCore 24K (24000mAh, 140W, 2× USB-C + 1× USB-A) | 549246 | 1 | Cordless-mode (Mode B) amp power |
| Raspberry Pi 5 8GB | 635649 | 1 | owned; **cut from the critical path** (the laptop is the brain) |
| Raspberry Pi 27W USB-C PSU | 620351 | 1 | Pi power (if used) |

### Wire + tools
| Part | SKU | Qty | Notes |
|---|---|---|---|
| AudioVox 18 AWG speaker wire, 100 ft | 995381 | 1 | **the only body wire on hand** + Mode B power bus |
| Adafruit 22 AWG solid-core hookup wire, 6 colors × 25 ft | 889089 | 2 | **stale — not physically present** |
| Apex/Weller soldering iron w/ LED halo | 499129 | 1 | |
| Newark rosin-core solder 60/40 | 461079 | 1 | |
| Eclipse compact digital multimeter | 653428 | 1 | |
| Eclipse 20–10 AWG wire stripper | 795880 | 1 | |
| LEO thin-wall heat-shrink assortment | 797399 | 1 | |
| IPSG Pro Micro starter kit | 055269 | 1 | |
| Elegoo ESP-32 USB-C (3-pack) | 961193 | 1 (+2 prior = **5** ESP32) | **not in the audio path** (sensor work only) |

### Not needed for the audio path
Resistors (1/4W 1kΩ SKU 796854 ×2, 2W 5.6kΩ SKU 796938). Keep for ESP32 sensor work. **No resistor in the audio chain.**

## Still to get

| Item | Why |
|---|---|
| 2× USB-C cables (sacrificial) | cut + strip to feed the two 5V solder buses from the Anker (cordless mode) |
| 3D-printed enclosure | houses Vantecs, amp boards (+ Pi if used), hub/bank — vented |
| Compression shirt/vest + VHB foam tape + velcro + zip ties + thin gloves | mount + couple actuators to the body |
| USB webcam (or use the laptop cam) | the vision branch needs a fretboard-facing camera |

## Channel accounting

- Vantec DAC channels available: **16** used (2 cards × 8); 12 routed, V3 spare
- SK473 amp channels: **12** (6 boards × 2) ← the limit
- Actuators driven: **12** KHD 3 Ω drivers = 6 strings (back) + 6 fret-zones (torso)
- Spare actuators: 24 LEO 40 mm speakers

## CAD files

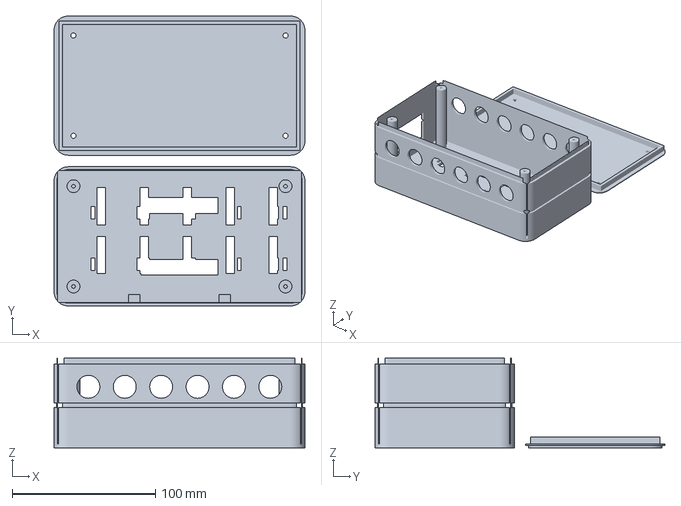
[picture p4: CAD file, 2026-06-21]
cad/tactus_enclosure_plate.3mf
175.2 x 202.4 x 62.6 mm

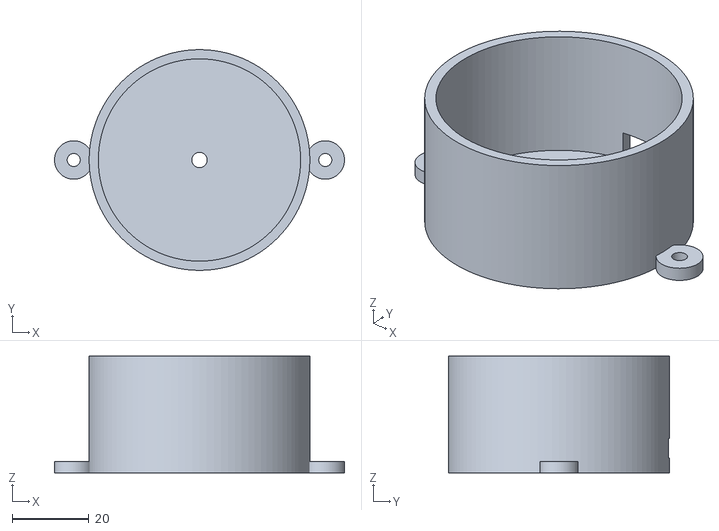
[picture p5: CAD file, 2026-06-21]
cad/actuator_cup.stl
75.4 x 57.4 x 30.4

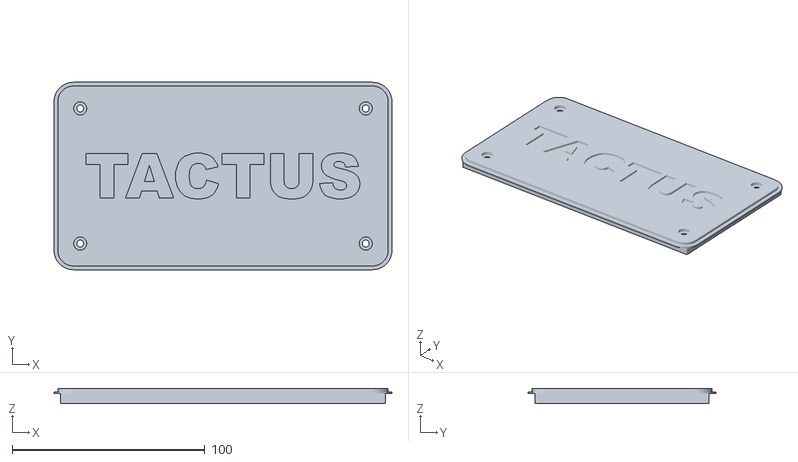
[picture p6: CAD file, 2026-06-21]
cad/tactus_enclosure_lid.stl
175.2 x 97.2 x 7.60

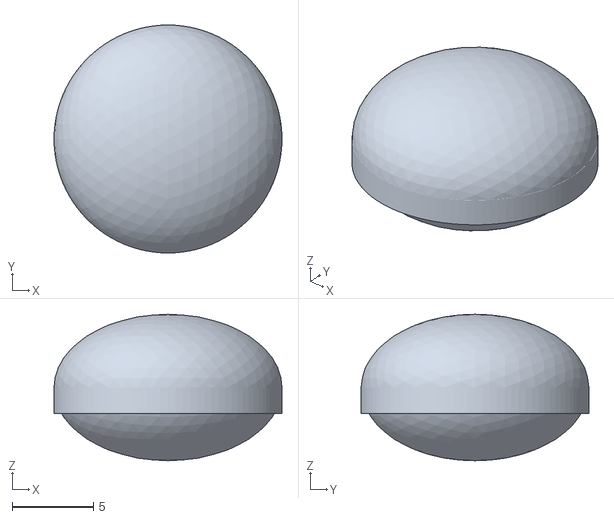
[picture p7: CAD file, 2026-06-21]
cad/actuator_button.stl
14.0 x 14.0 x 9.00

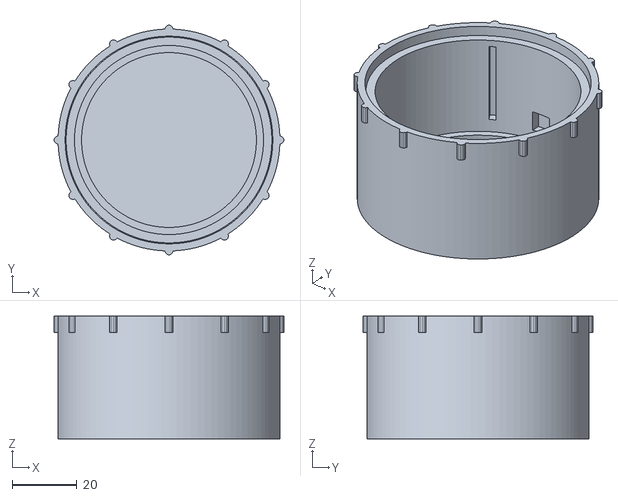
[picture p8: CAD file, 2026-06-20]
cad/node_barrel.stl
71.3 x 71.3 x 38.0

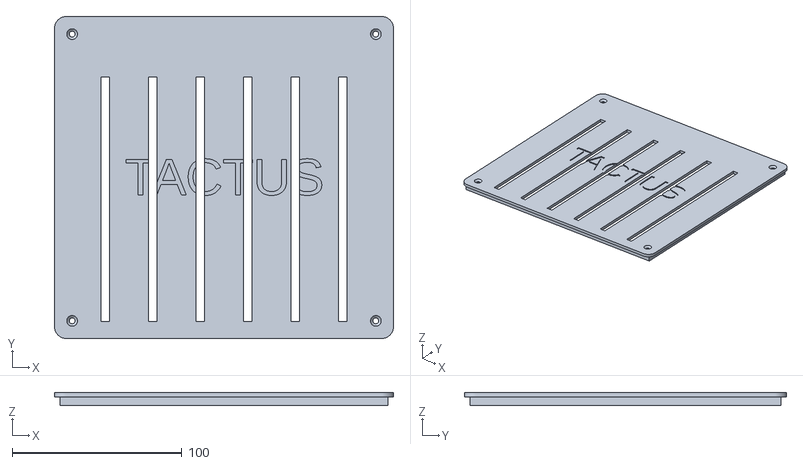
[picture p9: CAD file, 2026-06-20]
cad/tactus_box_lid.stl
199.8 x 189.8 x 7.40

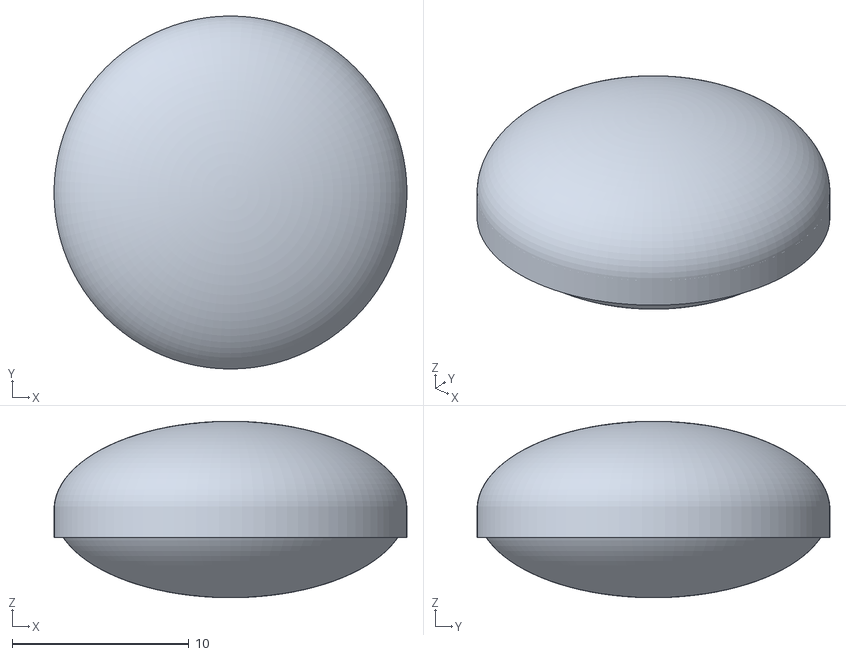
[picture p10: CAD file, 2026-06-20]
cad/contact_button.stl
20.0 x 20.0 x 9.99

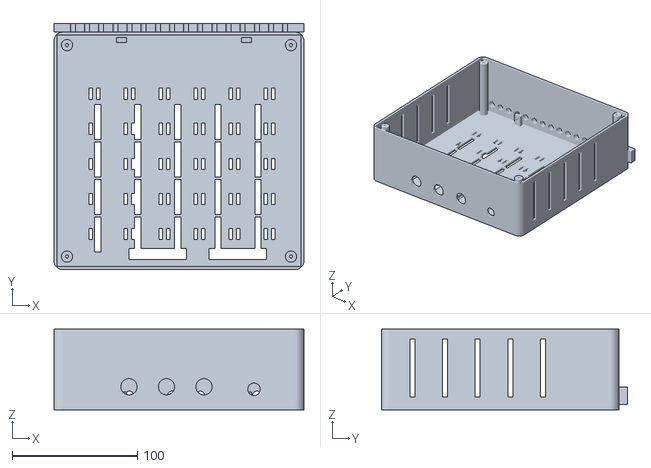
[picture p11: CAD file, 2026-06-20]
cad/tactus_box_base.stl
199.8 x 196.8 x 64.4

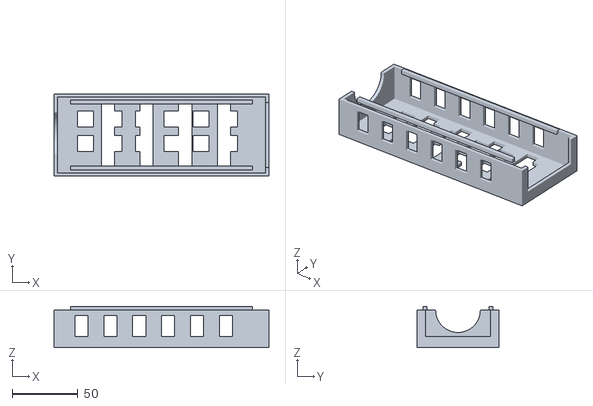
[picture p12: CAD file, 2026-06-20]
cad/tactus_power_cradle.stl
163.9 x 62.8 x 31.6

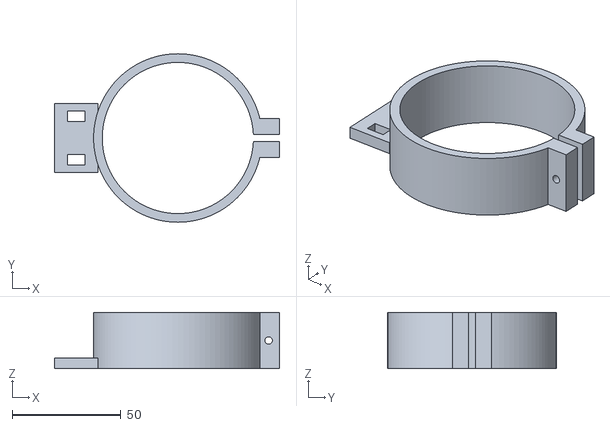
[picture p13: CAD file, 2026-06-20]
cad/node_base.stl
103.6 x 77.6 x 26.0

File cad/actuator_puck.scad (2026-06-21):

// ============================================================================
// TACTUS — Actuator coupling puck for the Ø52 mm SK473 KHD driver
// ----------------------------------------------------------------------------
// WHY THIS PART EXISTS (see docs/15-build-refinements.md §4):
// A Ø52 mm cone driver is built to throw sound into AIR. Pressed naively to a
// shirt it is HEARD, barely FELT. This puck turns it into a tactor:
//   - a closed, rigid CUP grips the speaker frame and kills air-radiation
//     (more energy goes into the body, less into the room),
//   - a domed CONTACT BUTTON bonds to the dust-cap so the cone's excursion
//     pokes straight into the skin,
//   - a WIRE NOTCH + zip-tie hole take all cable load off the speaker tabs,
//   - EARS let you zip-tie / sew the puck to the compression garment.
// Print ~14 cups + ~14 buttons (12 channels + spares). PETG, no supports.
// NOTE: render headless with `python cad/_puck_render.py` (manifold3d) — OpenSCAD
// is x86 and will not run on an arm64 Mac. The .scad stays the human-readable source.
// ============================================================================

part = "both";   // "cup" | "button" | "both" (both = side by side for preview/plate)

// ---- driver + fit parameters (Ø52 mm SK473 KHD driver — web-verified) -------
spk_dia        = 52.0;   // SK473 driver frame OD — Ø52 web-verified (Havit HV-SK473, "Φ52mm*2"); caliper to confirm cone-vs-frame
spk_depth      = 27.0;   // driver depth (est ~22-27; generous so the rim always seats — measure to confirm)
spk_fit_gap    = 0.6;    // radial clearance so the speaker drops in (PETG shrink-safe)
rim_lip        = 2.0;    // inward lip that the speaker rim rests against
wall           = 2.4;    // cup wall thickness
back           = 2.4;    // rigid back thickness (the coupling backer)

// ---- contact button (bonds to the dust cap, presses the skin) --------------
btn_dia        = 14.0;   // button diameter (sits on the dust cap)
btn_dome_h     = 4.5;    // how far it pokes proud -> touches skin first
btn_base_h     = 1.6;    // flat glue base

// ---- wire exit (sized for the 18 AWG zip-cord on hand — docs/15 §3) ---------
notch_w        = 6.0;    // wire-notch width: fits 18 AWG zip-cord (2 conductors)
notch_h        = 5.0;    // wire-notch height

// ---- derived ----------------------------------------------------------------
cup_id   = spk_dia + spk_fit_gap;          // inner bore that holds the speaker
cup_od   = cup_id + 2*wall;                // outer diameter
cup_h    = back + spk_depth + 1.0;         // closed back + speaker + a hair
$fn      = 96;

// ----------------------------------------------------------------------------
module cup() {
  difference() {
    union() {
      // outer body
      cylinder(d = cup_od, h = cup_h);
      // two mounting ears (zip-tie / sew to garment)
      for (a = [0, 180])
        rotate([0,0,a])
          translate([cup_od/2 + 4, 0, 0])
            cylinder(d = 10, h = 3);
    }

    // speaker bore (open at the SKIN side = top), leaving a closed rigid back
    translate([0, 0, back])
      cylinder(d = cup_id, h = cup_h);   // through to top

    // inward retaining lip at the open rim (speaker rim rests on it)
    translate([0, 0, cup_h - rim_lip])
      cylinder(d1 = cup_id, d2 = cup_id - 2*1.5, h = rim_lip + 0.1);

    // wire exit notch through the wall (cable leaves sideways, low) — 18 AWG
    translate([0, 0, back + 1.5])
      rotate([0,0,90])
        translate([cup_od/2 - wall - 0.5, -notch_w/2, 0])
          cube([wall + 1.5, notch_w, notch_h]);

    // strain-relief zip-tie hole right at the wire exit (anchor cable to cup)
    rotate([0,0,90])
      translate([cup_od/2 - 1.0, 0, back + 3.5])
        rotate([0,90,0]) cylinder(d = 2.6, h = wall + 2, center = true);

    // ear holes
    for (a = [0, 180])
      rotate([0,0,a])
        translate([cup_od/2 + 4, 0, -0.5])
          cylinder(d = 3.4, h = 5);

    // small back vent so the trapped air behind the cone can breathe a touch
    // (a fully sealed cone stalls; one small port keeps excursion alive)
    translate([0, 0, -0.5]) cylinder(d = 4, h = back + 1);
  }
}

// ----------------------------------------------------------------------------
// Contact button: flat base glued to the dust cap, dome pokes toward skin.
module button() {
  union() {
    cylinder(d = btn_dia, h = btn_base_h);
    translate([0, 0, btn_base_h])
      // shallow dome
      scale([1, 1, btn_dome_h / (btn_dia/2)])
        sphere(d = btn_dia);
  }
}

// ----------------------------------------------------------------------------
if (part == "cup")    cup();
else if (part == "button") button();
else {                       // both -> for a quick visual / single small plate
  cup();
  translate([cup_od + 8, 0, 0]) button();
}

// ASSEMBLY (per actuator) — NO SOLDERING (truth.md §3.3, docs/15 §11-12):
//  1. De-house the driver: pop the cone from the SK473 shell with its factory
//     leads still attached to the amp board (no solder); thread the lead out the notch.
//  2. Zip-tie the lead to the cup through the strain-relief hole (cable load now
//     on the cup, never on the driver's own joint — see docs/06-safety.md).
//  3. Drop the driver into the cup, cone facing OUT (toward the open rim).
//  4. Super-glue / VHB a contact BUTTON to the centre of the dust cap so it
//     stands ~2-3 mm proud of the cup rim -> it hits skin first.
//  5. Zip-tie or sew the ears to the compression garment, button to the body,
//     snug. Foam-isolate the cup back from the garment to limit crosstalk.

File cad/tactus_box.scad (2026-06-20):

// ============================================================================
// TACTUS — Main electronics enclosure ("brain-pack")
// ----------------------------------------------------------------------------
// Holds everything that is NOT the vest or the subwoofers (per the build):
//   - 3x Vantec NBA-200U USB 7.1 cards     (100 x 58 x 26 mm each)
//   - 7x gutted SK473 / PAM8403 amp bricks (~55 x 35 x 25 mm each)
//   - 1x Raspberry Pi 5 (optional)         (85 x 56 mm, mounted on bosses)
//   (the Anker 737 / 10-port hub live in the SEPARATE tactus_power_cradle.scad
//    so the battery vents + stays removable for Mode A / Mode B swaps)
//
// Design goals (see docs/15-build-refinements.md):
//   - DIMENSION-TOLERANT: boards mount with VHB foam + zip-ties through a floor
//     slot grid, not press-fit pockets (our part dims are partly estimated).
//   - STRAIN RELIEF FIRST: a comb wall takes the 14-wire umbilical load off the
//     amp output pads — the #1 documented failure mode (docs/06-safety.md).
//   - VENTED: amps run warm; floor + wall + lid vents, Pi on standoffs.
//   - WEARABLE or table: belt-strap slots on the base; rubber-foot friendly.
//   - Fits the FlashForge Adventurer 5M 220x220x220 bed with margin.
//
// RENDER: set `part` then F6 -> Export STL. Print base + lid separately.
// ============================================================================

part = "base";          // "base" | "lid"

// ---- internal volume (edit to taste; keep outer < ~210 for a safe 220 bed) --
inner_x   = 195;        // width  (X)
inner_y   = 185;        // depth  (Y) — enlarged: holds 3 Vantec + 6 amps with ~25% floor to spare
inner_z   = 62;         // height (Z) — 25 mm amp + headroom; amps can also stack 2-high here
corner_r  = 7;          // rounded vertical corners (product look, not a raw cube)
wall      = 2.4;        // wall thickness (3 perimeters @ 0.4 nozzle, PETG)
floor_t   = 2.4;        // floor thickness
lid_t     = 2.4;        // lid plate thickness

outer_x   = inner_x + 2*wall;     // ~199.8
outer_y   = inner_y + 2*wall;     // ~154.8
base_h    = floor_t + inner_z;    // ~60.4

n_wires   = 16;         // umbilical comb slots (14 used + 2 spare)
include_pi = false;     // Pi CUT from scope (laptop-only) — set true to restore the wearable-mode mount
$fn       = 64;
eps       = 0.05;

// ---- lid screw boss positions (shared by base + lid so holes align) ---------
boss_inset = wall + 8;
boss_pts = [
  [boss_inset,           boss_inset],
  [outer_x - boss_inset, boss_inset],
  [boss_inset,           outer_y - boss_inset],
  [outer_x - boss_inset, outer_y - boss_inset]
];

// ---- Raspberry Pi 5 mount (58 x 49 hole pattern), front-left corner ---------
pi_x0 = 22; pi_y0 = 20;            // first hole center
pi_holes = [
  [pi_x0,      pi_y0],
  [pi_x0 + 58, pi_y0],
  [pi_x0,      pi_y0 + 49],
  [pi_x0 + 58, pi_y0 + 49]
];

// rounded-rectangle prism + engraved logo -> reads as a designed unit, not a cube
module rprism(x, y, h, r) {
  linear_extrude(h) translate([r, r]) offset(r = r) square([x - 2*r, y - 2*r]);
}
module logo_cut() {
  translate([outer_x/2, outer_y/2, lid_t - 0.8])
    linear_extrude(1.2) text("TACTUS", size = 22, halign = "center", valign = "center");
}

// ============================================================================
module base() {
  union() {
    difference() {
      union() {
        rprism(outer_x, outer_y, base_h, corner_r);   // rounded outer shell
        comb_ledge();                          // external strain-relief comb (+Y wall)
      }

      // --- main cavity (open top) ---
      translate([wall, wall, floor_t])
        cube([inner_x, inner_y, inner_z + eps]);

      // --- umbilical wire pass-throughs + comb slots (+Y wall) ---
      wire_passthroughs();

      // --- laptop-side glands: 3x USB + 1x power feed (-Y wall) ---
      gland_holes();

      // --- vents ---
      floor_vents();
      shortwall_vents();

      // --- belt / strap slots in the floor near the -Y edge ---
      strap_slots();

      // --- zip-tie floor grid (mount any board anywhere) ---
      ziptie_floor_grid();
    }

    // --- adds (after the difference so the cavity doesn't eat them) ---
    if (include_pi) pi_standoffs();   // Pi cut from scope by default — frees floor for amps/Vantecs
    lid_bosses();
    cable_anchors();          // internal zip-tie posts at the wire wall
  }
}

// ----------------------------------------------------------------------------
module comb_ledge() {
  // external ledge on the +Y wall, holes/slots cut later in wire_passthroughs()
  translate([0, outer_y, floor_t + 2])
    cube([outer_x, 7, 14]);
}

module wire_passthroughs() {
  // a row of Ø7 holes through the +Y wall AND the comb ledge, open-topped slots
  spacing = (outer_x - 30) / (n_wires - 1);
  for (i = [0 : n_wires - 1]) {
    x = 15 + i * spacing;
    // through-hole (wall + comb)
    translate([x, outer_y + 8, floor_t + 9])
      rotate([90, 0, 0])
        cylinder(d = 7, h = wall + 10);
    // open-top slot so a wire can be pressed in from above (no threading)
    translate([x - 2, outer_y - eps, floor_t + 9])
      cube([4, wall + 8, 20]);
  }
}

module gland_holes() {
  // -Y wall: 3 USB cable glands + 1 power-feed gland
  usb_d = 13; pwr_d = 10;
  xs = [outer_x*0.30, outer_x*0.45, outer_x*0.60];
  for (x = xs)
    translate([x, -eps, floor_t + 16])
      rotate([-90, 0, 0]) cylinder(d = usb_d, h = wall + 2*eps);
  translate([outer_x*0.80, -eps, floor_t + 14])
    rotate([-90, 0, 0]) cylinder(d = pwr_d, h = wall + 2*eps);
}

module floor_vents() {
  // grid of slots through the floor (airflow under the boards + Pi)
  for (ix = [0 : 4], iy = [0 : 3]) {
    x = 35 + ix * 32;
    y = 28 + iy * 30;
    translate([x - 2.5, y - 14, -eps])
      cube([5, 28, floor_t + 2*eps]);
  }
}

module shortwall_vents() {
  // vertical slots in the two short walls (x = 0 and x = outer_x)
  for (iy = [0 : 4]) {
    y = 25 + iy * 26;
    // -X wall
    translate([-eps, y - 2, floor_t + 8])
      cube([wall + 2*eps, 4, inner_z - 16]);
    // +X wall
    translate([outer_x - wall - eps, y - 2, floor_t + 8])
      cube([wall + 2*eps, 4, inner_z - 16]);
  }
}

module strap_slots() {
  // two floor slots near the -Y edge -> thread a belt/strap to wear the pack
  for (x = [outer_x*0.30, outer_x*0.62])
    translate([x, 8, -eps])
      cube([46, 9, floor_t + 2*eps]);
}

module ziptie_floor_grid() {
  // pairs of thin slots (a zip tie loops up one, over the board, down the other)
  for (ix = [0 : 5], iy = [0 : 4]) {
    x = 28 + ix * 28;
    y = 24 + iy * 28;
    if (x < inner_x - 6 && y < inner_y - 6) {
      translate([x,     y, -eps]) cube([2.6, 9, floor_t + 2*eps]);
      translate([x + 6, y, -eps]) cube([2.6, 9, floor_t + 2*eps]);
    }
  }
}

module pi_standoffs() {
  for (p = pi_holes)
    translate([p[0], p[1], floor_t])
      difference() {
        cylinder(d = 7, h = 6);
        translate([0,0,-eps]) cylinder(d = 2.3, h = 6 + 2*eps);  // M2.5 self-tap
      }
}

module lid_bosses() {
  for (p = boss_pts)
    translate([p[0], p[1], floor_t])
      difference() {
        cylinder(d = 9, h = inner_z);
        translate([0,0, inner_z - 14]) cylinder(d = 2.6, h = 14 + eps); // M3 self-tap
      }
}

module cable_anchors() {
  // two posts just inside the wire wall to lash the internal bundle to
  for (x = [outer_x*0.25, outer_x*0.75])
    translate([x, outer_y - wall - 6, floor_t])
      difference() {
        cube([8, 4, 12], center = false);
        translate([4, -eps, 6]) rotate([-90,0,0]) cylinder(d = 3, h = 4 + 2*eps);
      }
}

// ============================================================================
module lid() {
  difference() {
    union() {
      rprism(outer_x, outer_y, lid_t, corner_r);       // rounded top plate
      // nesting lip (locates the lid into the cavity) — loose ~0.8mm/side fit
      translate([wall + 0.8, wall + 0.8, -5])
        difference() {
          cube([inner_x - 1.6, inner_y - 1.6, 5 + eps]);
          translate([2, 2, -eps])
            cube([inner_x - 5.6, inner_y - 5.6, 5 + 2*eps]);
        }
    }
    logo_cut();   // engraved TACTUS on the lid
    // corner screw holes (clearance + countersink) — align to boss_pts
    for (p = boss_pts) {
      translate([p[0], p[1], -eps]) cylinder(d = 3.4, h = lid_t + 2*eps);
      translate([p[0], p[1], lid_t - 1.6]) cylinder(d1 = 3.4, d2 = 6.4, h = 1.6 + eps);
    }
    // lid vents (slot array)
    for (ix = [0 : 5], iy = [0 : 4]) {
      x = 30 + ix * 28; y = 26 + iy * 28;
      if (x < outer_x - 24 && y < outer_y - 24)
        translate([x - 2.5, y - 16, -eps]) cube([5, 32, lid_t + 2*eps]);
    }
  }
}

// ============================================================================
if (part == "base") base();
else if (part == "lid") lid();
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

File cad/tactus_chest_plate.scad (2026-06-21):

// ============================================================================
// TACTUS — Chest plate (body-contoured, holds the 6 "string" drivers)
// ----------------------------------------------------------------------------
// A cylindrical-SECTION shell (the torso ~= a cylinder) carrying a vertical
// column of 6 self-adjusting sockets (high-E top -> low-E bottom, docs/07),
// with strap slots to lash onto the laser-tag vest. Prints as 2 tiles so it
// fits the bed and flexes to the body.
//
// ⚠️ PLACEHOLDERS until measured: `drv_*` (the SK473 KHD driver) and
//    `torso_r` (chest curvature) + `col_pitch` (per the wearer). Update + re-render.
//
// `use`s the socket module. RENDER: set `part`, F6 -> export STL.
// ============================================================================
use <tactus_socket.scad>

part       = "full";   // "full" | "top" | "bottom"  (top/bottom = the 2 print tiles)

// ---- driver (measure!) ----------------------------------------------------
drv_dia    = 52;   drv_depth = 27;   drv_mag_dia = 30;   // Ø52 web-verified (Havit HV-SK473); depth/magnet — caliper to confirm, re-render in OpenSCAD

// ---- body fit (measure the wearer + vest) ---------------------------------
torso_r    = 150;  // chest radius of curvature (PLACEHOLDER ~150mm)
col_pitch  = 46;   // vertical spacing between string sockets (>= skin 2-pt res)
n_string   = 6;    // 6 strings
plate_t    = 3.0;  // shell thickness
arc_half   = 58;   // half-width of the panel (chord), mm

$fn = 120; eps = 0.05;
sock_od = socket_outer_d(drv_dia);
col_h   = (n_string - 1) * col_pitch;          // column span
z0      = -col_h/2;                            // first socket z
split_z = 0;                                    // tile boundary (between #3 and #4)

// curved shell panel between z_lo..z_hi (a front section of the torso cylinder)
module shell(z_lo, z_hi) {
  intersection() {
    difference() {
      cylinder(r = torso_r + plate_t, h = z_hi - z_lo);
      translate([0,0,-1]) cylinder(r = torso_r, h = z_hi - z_lo + 2);
    }
    translate([0, -arc_half, 0]) cube([torso_r + plate_t + 1, 2*arc_half, z_hi - z_lo]);
  }
}

// place one socket on the front inner face at height z, skin-side toward the body
module socket_at(z) {
  translate([torso_r, 0, z]) rotate([0, 90, 0]) driver_socket(drv_dia, drv_depth, drv_mag_dia);
}
// through-hole in the panel so the cone/button reaches the skin
module bore_at(z) {
  translate([torso_r - 2, 0, z]) rotate([0, 90, 0])
    cylinder(d = drv_dia - 8, h = plate_t + 4);
}

// strap slots along the top + bottom edges (lash to the laser-tag vest)
module strap_slots(z_lo, z_hi) {
  for (z = [z_lo + 8, z_hi - 8], y = [-arc_half*0.6, 0, arc_half*0.6])
    translate([torso_r + plate_t/2, y, z]) rotate([0,90,0])
      cube([plate_t + 4, 10, 4], center = true);
}

module tile(z_lo, z_hi) {
  // which sockets fall in this tile's z-range
  difference() {
    union() {
      translate([0,0,z_lo]) shell(z_lo, z_hi);
      for (i = [0:n_string-1]) let(z = z0 + i*col_pitch)
        if (z >= z_lo && z < z_hi) socket_at(z);
    }
    for (i = [0:n_string-1]) let(z = z0 + i*col_pitch)
      if (z >= z_lo && z < z_hi) bore_at(z);
    strap_slots(z_lo, z_hi);
  }
}

// NOTE: shell() is modeled from z=0; tile() translates it. Re-place sockets in
// absolute z by building the shell at absolute coords instead:
module tile_abs(z_lo, z_hi) {
  difference() {
    union() {
      intersection() {
        difference() {
          translate([0,0,z_lo]) cylinder(r = torso_r + plate_t, h = z_hi - z_lo);
          translate([0,0,z_lo-1]) cylinder(r = torso_r, h = z_hi - z_lo + 2);
        }
        translate([0, -arc_half, z_lo]) cube([torso_r + plate_t + 1, 2*arc_half, z_hi - z_lo]);
      }
      for (i = [0:n_string-1]) let(z = z0 + i*col_pitch)
        if (z >= z_lo - eps && z < z_hi + eps) socket_at(z);
    }
    for (i = [0:n_string-1]) let(z = z0 + i*col_pitch)
      if (z >= z_lo - eps && z < z_hi + eps) bore_at(z);
    strap_slots(z_lo, z_hi);
  }
}

if (part == "full")        tile_abs(z0 - 20, z0 + col_h + 20);
else if (part == "top")    tile_abs(split_z, z0 + col_h + 20);
else if (part == "bottom") tile_abs(z0 - 20, split_z);

// ASSEMBLY: 2 tiles bolt/zip together at the split, lash to the laser-tag vest
// chest panel via the strap slots; sockets hold the 6 string-drivers (foam-backed,
// docs/15 §4); buttons protrude toward the body. Tune preload per docs/18.

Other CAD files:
cad/tactus_enclosure_base.3mf
cad/tactus_node_mount.scad
cad/tactus_enclosure_base.stl
cad/tactus_enclosure_plate.stl
cad/tactus_power_cradle.scad
cad/tactus_socket.scad

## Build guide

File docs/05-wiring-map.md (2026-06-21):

# Wiring map — channel by channel

> **⚠️ UPDATED Jun 20 → 12 channels.** Teardown showed each SK473 box = **1 stereo amp (2 ch) + 2 drivers**, so 6 boxes = **12 channels**, not 14. Each box's single 3.5 mm jack is **stereo = 2 independent channels** (L=driver A, R=driver B); the USB is shared 5 V power only. 6 stereo jacks → **2 Vantecs** (V3 spare). **The live source of truth is now [`config/channel_map.json`](../config/channel_map.json)** (12 entries, `box`=B1–B6); use the SK473's own **KHD 3 Ω drivers**, not the 40 mm (`docs/15 §11–§12`). The 2 reserved upper-back zones (old ch 13–14) are **dropped**.

12 channels = 2 Vantec cards → 6 SK473 boxes (stereo) → 12 SK473 KHD 3 Ω drivers. Label every cable to match the JSON.

## The map

| Ch | Vantec | Jack | Box | Amp side | Body site | Actuator |
|----|---|---|-----|---|---|---|
| 1  | V1 | front  | B1 | L | string 1 (high E) — back top | KHD 3Ω |
| 2  | V1 | front  | B1 | R | string 2 (B) — back | KHD 3Ω |
| 3  | V1 | rear | B2 | L | string 3 (G) — back | KHD 3Ω |
| 4  | V1 | rear | B2 | R | string 4 (D) — back | KHD 3Ω |
| 5  | V1 | center | B3 | L | string 5 (A) — back | KHD 3Ω |
| 6  | V1 | center | B3 | R | string 6 (low E) — back bottom | KHD 3Ω |
| 7  | V1 | side | B4 | L | fret-zone 1 — torso (near nut) | KHD 3Ω |
| 8  | V1 | side | B4 | R | fret-zone 2 — torso | KHD 3Ω |
| 9  | V2 | front  | B5 | L | fret-zone 3 — torso | KHD 3Ω |
| 10 | V2 | front  | B5 | R | fret-zone 4 — torso | KHD 3Ω |
| 11 | V2 | rear | B6 | L | fret-zone 5 — torso | KHD 3Ω |
| 12 | V2 | rear | B6 | R | fret-zone 6 — torso (toward elbow) | KHD 3Ω |

- V3 (third Vantec) is **spare / fallback** — swap in for any V1/V2 jack that won't map on Linux.
- B1–B6 = the 6 SK473 amp boards.
- All 12 channels drive the SK473's own de-housed **KHD 3 Ω/5 W drivers** (strings on the back, fret-zones on the torso). The 40 mm LEO speakers are spares.

## Why this layout
- **6 strings as a vertical back column** mirrors the guitar (high E up, low E down) → intuitive.
- **Fret-zones z1–z6 run along the torso** (near nut → elbow). Sites stay ≥ 4–5 cm apart → within skin two-point resolution (torso ~35–40 mm). A tight row on one spot would funnel into a blob; spreading prevents that. (The 2 reserved upper-back zones from the old 14-channel layout are dropped.)
- 12 musical frets map onto the 6 torso zones via **zone + intensity** (see [07-haptic-encoding.md](07-haptic-encoding.md)).

## ALSA side
Each Vantec exposes its 8 channels as one card. The renderer routes a logical channel index → (card, channel) → jack → amp → actuator, per [config/channel_map.json](../config/channel_map.json). Keep this table and that file in sync.

## Labeling rule
Write the channel number on **both ends** of every speaker-wire run and on each amp. A mislabeled channel = a note felt in the wrong place = silent bug. Label as you solder, not after.

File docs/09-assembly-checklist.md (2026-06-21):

# Assembly checklist + bring-up

Build in this order. Each stage has a go/no-go gate — do not proceed past a failed gate. The biggest risk now is **build time**, so prove a small slice end-to-end before scaling.

## Stage 0 — bench prep
- [ ] Lay out all 6 SK473 (their 12 KHD drivers are the actuators), 2 Vantecs + V3 spare, 18 AWG wire, iron, multimeter, heat-shrink, hot glue.
- [ ] Confirm the Anker 737 charged; confirm the 10-port hub's 10A adapter present.
- **Gate:** all parts present per [01-bill-of-materials.md](01-bill-of-materials.md).

## Stage 1 — prove the audio path (BEFORE any soldering)
- [ ] One Vantec into the laptop. `aplay -l` shows the card.
- [ ] `speaker-test -c8 -Dhw:CARD` — confirm all 8 channels map to the 4 jacks.
- [ ] Plug one un-gutted SK473 into a Vantec jack, power it, play a tone → its speaker sounds.
- [ ] Repeat for all 3 Vantecs (confirm each enumerates independently).
- **Gate:** every Vantec maps cleanly. If a jack misbehaves → use Vantec V3 / a Sabrent dongle for that channel. **Don't solder until this passes.**

## Stage 2 — gut + tone-test each amp (×6)
- [ ] Gut each SK473, keeping its 2 KHD drivers ([04-soldering-guide.md](04-soldering-guide.md) Job 1).
- [ ] Solder 2 KHD drivers per amp, each on its own isolated 2-wire pair (Job 2). Heat-shrink + hot-glue every joint.
- [ ] Tone-test each amp individually → both KHD drivers buzz. Label the channel.
- **Gate:** all 12 channels buzz on a tone. Replace any dead board from the spare SK473.

## Stage 3 — power
- **Mode A (wall):** plug all 6 SK473 USB leads into the 10-port hub; hub to wall.
- **Mode B (cordless):** build the 5V buses (Job 3), split 3/2/2 across Anker ports.
- [ ] Meter polarity on every feed. Gain knobs at minimum.
- **Gate:** [03-power.md](03-power.md) pre-power checklist passes; no shorts.

## Stage 4 — chord stress test
- [ ] Fire a single channel → felt.
- [ ] Fire all 12 at once (simulated chord) at felt gain. (Real playback is a sequential strum → ≤ 2 drivers active at once, ~2–3 W; firing all 12 is a worst-case stress check.)
- [ ] Mode B: watch the Anker display — each port under its limit.
- **Gate:** no brown-out, no cut-outs. If Mode B dips → add the 3rd port / lower gain.

## Stage 5 — mount + couple
- [ ] Mount actuators per [05-wiring-map.md](05-wiring-map.md): 6 strings on back, 6 fret-zones on torso.
- [ ] VHB + rigid backer, firm coupling. Service loops + garment anchors so no actuator bears wire weight ([06-safety.md](06-safety.md)).
- **Gate:** each site is clearly felt and mechanically secure under arm movement.

## Stage 6 — software bring-up
- [ ] Channel map ([config/channel_map.json](../config/channel_map.json)) matches the wiring table.
- [ ] Renderer plays a known (string, fret) → correct body site lights.
- [ ] AI engine: webcam + mic → transcription + vision overlay.
- [ ] Coach loop end-to-end on one phrase.
- **Gate:** play a note → felt in the right place + shown on screen + coached.

## Stage 7 — demo dry run
- [ ] Full song, Mode A (wall) for reliability.
- [ ] Then Mode B cordless for the walk-around flex.
- [ ] Time it; rehearse the failure fallback (Vantec→dongle, Mode B→Mode A).

## Go/no-go summary
Audio path ✓ → amps buzz ✓ → power holds a chord ✓ → mounted + coupled ✓ → software renders + coaches ✓ → demo rehearsed ✓.

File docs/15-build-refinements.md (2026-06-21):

# 15 — Build refinements + the kinks that will bite (read before Saturday)

> This doc **does not replace** `01`–`09`/`14` — it sharpens them. It collects the *non-obvious failure modes* in the as-purchased build (laptop → 3× Vantec → 7× SK473/PAM8403 → 14× 40 mm speakers) and gives the exact fix for each, plus a tightened "what connects to what" map and a single-channel-first build order. Every item here is a thing that, skipped, silently costs you hours or a fried board on Saturday.

---

## 0. The 60-second mental model of the whole rig

```
LAPTOP ── USB data ──> 3× VANTEC (USB→8 analog ch each)
                           │  3.5 mm STEREO PLUG  (each plug = 2 channels = one amp)
                           ▼
                        7× SK473 amp brick (gutted → bare PAM8403, 2 ch each)
                           │  2-wire SPEAKER PAIR per channel  (BTL: + and − are BOTH driven)
                           ▼
                        14× 40 mm speaker (felt, not heard) on the body

POWER (5 V, separate from all audio):  hub (wall, Mode A)  OR  Anker 737 bus (cordless, Mode B)
        → feeds ONLY the amps' 5 V USB leads.  Laptop + Vantecs powered by the laptop's own USB.
```

Three rails of truth that everything else hangs on:
1. **Audio is line-level on 3.5 mm; actuator drive is bare 2-wire from the amp.** They never touch.
2. **Power (5 V) is a third, independent thing.** It only ever reaches the amps.
3. **One ground is shared** (laptop ↔ Vantec ↔ 3.5 mm sleeve ↔ amp). That is intended and safe — but it means the *only* isolation you have is "+5 V is never tied to a signal line." Respect it (see `06`).

---

## 1. ⚠️ THE BIG ONE — PAM8403 is a BTL amp: never common the "−" outputs

This is the single easiest way to kill an amp on this build, and it's the kind of thing a tidy-minded person does *on purpose* while "cleaning up the grounds." **Do not.**

- The PAM8403 is a **filterless Class-D, bridge-tied-load (BTL)** amp. For each channel the **two output terminals (`+` and `−`) are BOTH actively driven** — they swing in opposite directions around ~½·VCC. **Neither one is ground.**
- Therefore:
  - ❌ **Never connect any output `−` to GND.** (You short a half-bridge to ground → over-current → dead chip.)
  - ❌ **Never join two channels' `−` together, or run a single shared "return" wire for several actuators.** (You short two half-bridges into each other.)
  - ✅ **Every actuator gets its own isolated 2-conductor pair** straight back to *its* channel's `+`/`−`. The 18 AWG you bought is 2-conductor zip cord — one length = one channel. Perfect, *as long as you never bond the returns.*
- **Phase:** keep `+ → +` consistent across the whole array (mark one conductor of the zip cord — the ribbed/striped side — as `+` everywhere). Two actuators fired together then move in phase, which the encoder (`07`) assumes.
- This is *different* from the old MAX98357A plan, which was capless-but-single-ended. The encoding/wiring docs already say "one pair per channel"; this section is the *why*, so nobody re-routes a ground bus and fries A3.

> Quick check before powering: meter resistance from each output `−` to the amp's power GND. It should **NOT** be ~0 Ω. If any `−` reads a dead short to GND, you have an accidental bond — find it before you apply 5 V.

---

## 2. ⚠️ The Vantec/ALSA enumeration trap (this eats Saturday if you don't pre-empt it)

You have **three identical CM6206 cards**. On Linux they all enumerate as the *same name* ("USB Sound Device" / "C-Media USB Audio"), and **their card indices (`hw:0/1/2`) reorder across reboots and re-plugs.** If your renderer addresses cards by index, channel 1 silently jumps to the wrong Vantec → notes felt in the wrong place → a "bug" that's really just a shuffled index. Two real gotchas, two fixes:

**A. Bind cards by physical USB port, not by index.** Plug the 3 Vantecs into 3 *specific, labelled* laptop/hub ports and address them by stable path. Get the stable names with:
```bash
ls -l /dev/snd/by-id/        # stable per-device symlinks
cat /proc/asound/cards       # index ↔ usb path
aplay -l                     # card/device numbers (these can move!)
```
Use the `by-id`/`by-path` name (or a tiny udev rule mapping each USB port → a fixed ALSA name) and store **that** in `config/channel_map.json`'s `card_alsa`, not a bare `0/1/2`. Label each Vantec **V1/V2/V3** physically and always plug it into its own port.

**B. The 8-channel *order within a card* is not the obvious one.** CM6206 commonly presents channels as **FL, FR, FC, LFE, RL, RR, SL, SR** — i.e. **center/LFE come before the rears**, not in jack order. The current `channel_map.json` assumes `front=0,1 / rear=2,3 / center=4,5 / side=6,7`. **Verify the true mapping before you trust it:**
```bash
speaker-test -D hw:CARD,0 -c 8 -t sine    # walks ch 0→7; note which JACK each one comes out of
```
Plug a known amp+speaker into one jack at a time and learn `(alsa index → jack)` empirically. Then fix `alsa_ch` in the map. **Do this in Stage 1, before any soldering** (`09` already gates on it — this is the *why*).

**C. The center jack's ch 4 slot is "LFE."** On a raw `hw:` device it passes full-band (bass-management is an OS mixer feature, not applied to a direct device), so it's fine for our 200–250 Hz pulses — but **confirm it isn't attenuated** during the speaker-test. If any one channel is quiet, move that *logical* channel onto the spare Vantec **V3** rather than fighting it.

---

## 3. Wire gauge — you only have 18 AWG, so the build has to respect it

> **Reality (per Aditya): the only wire on hand is the AudioVox 18 AWG speaker zip-cord.** The BOM's "22 AWG solid-core" line (`docs/01`) is **stale — that wire is not physically here.** So plan everything around 18 AWG. The good news: speaker zip-cord is **stranded**, so it flexes and won't snap; the bad news is it's heavy/stiff and **fat for the tiny amp pads**. Two consequences:

**A. It tears joints (mechanical).** 18 AWG weight + arm motion levers the joint — the whole reason `06` exists. With no lighter wire to fall back on, strain relief is **mandatory, not optional**:
- Keep every actuator run **as short as the layout allows** + one small **service loop**.
- **Strain-relieve both ends** of every run — the `actuator_puck` zip-tie notch at the body end, the box's `comb` + `cable_anchors` at the amp end. The puck/comb are doing the job the missing thin wire would have done.

**B. It's too fat to land cleanly on a PAM8403 output pad or a 40 mm speaker tab (electrical/solder).** Cramming a full 18 AWG conductor onto a ~1 mm pad will **lift the pad** (a permanent kill). Fix at the joint:
- **Fan and trim the strands** at the pad end — solder maybe half the strands, snipped flush, so you land a manageable tinned bundle, not the full crowbar. (0.3–0.5 A doesn't need the full copper anyway.)
- **Tin the pad and the wire first**, land fast, then a **hot-glue blob is non-negotiable** — it, not the solder, carries the load.

**C. The single best upgrade is still cheap: grab one spool of 24–26 AWG stranded silicone** (~$7, any hardware/hobby store). It solders onto the small pads easily *and* solves the weight problem in one move — by far the highest-leverage "still to get." If you can grab it before Saturday, do; if not, the all-18-AWG plan above works with discipline.

**Power bus (Mode B):** here 18 AWG is *correct* — that's where real current flows (~2.85 A peak/bus). Use it for the 5 V rail backbone with no reservations.

> I widened the `actuator_puck` wire notch to fit 18 AWG zip-cord. If a run is still tight, pass the two conductors through **separately** or bump `notch_w` in `actuator_puck.scad`.

---

## 4. The 40 mm "speakers" are not exciters — coupling is the make-or-break

A Dayton exciter is *designed* to inject vibration into a surface through a sticky puck. A 40 mm cone speaker is designed to throw sound into **air**. Pressed naively against a shirt it will be **heard, barely felt** — most of the energy radiates as sound and the frame stays still. To make it *felt*:

- **Load the moving mass into the skin.** Bond a small **contact button to the centre of the cone/dust-cap**, and press *that* button to the body, while the **magnet/frame is anchored to a rigid backer.** Now the cone's excursion couples straight into tissue. (This is exactly what the `cad/actuator_puck.scad` part does: a domed contact face on the cone side + a rigid backer on the magnet side + VHB + a wire strain-relief notch.)
- **Firm preload.** Snug compression fabric / a light elastic strap raises sensitivity a lot (contact force directly lowers the detection threshold — `12`/`14`). Loose = you hear it; firm = you feel it.
- **Foam-isolate the backer from the garment** so one actuator doesn't shake its neighbours into a blur (crosstalk — `07` design rule #1). Keep sites ≥ 4–5 cm apart (already in `05`).
- **Seal optional:** dropping the speaker into a small closed cup (the puck's pocket) kills its air-radiation and forces more energy into the body — quieter to the room, stronger on the skin. Good for a loud venue.

> Saturday's **#1 risk is still coupling** (same as every version of this project). Prove *one* actuator + puck + strap feels strong **before** you build 14. If a bare speaker feels weak, the puck — not more volume — is the fix.

---

## 5. Power: correct the "50 W rail can't collapse" claim (Mode A)

`03` treats the wall hub as "one 50 W 5 V rail → physically cannot collapse." A powered USB hub is **not** a dumb 5 V rail — verify two things or it can still droop on a chord:

- **The brick is almost certainly 12 V, ~4–5 A (≈48–60 W),** stepped down to 5 V *inside* the hub — not "10 A at 5 V." After buck efficiency that's ~**8–10 A available at 5 V**, which still clears the 6.65 A hard-chord peak — **but** only if the hub doesn't enforce a low **per-port** current limit (USB-3 default is 0.9 A/port; charging hubs do 1.5–2.4 A).
- **So the real guarantee is the same as Mode B: run at *felt* level.** At felt play the whole rig draws **~3.5 A / 18 W** — comfortably under any plausible hub budget and per-port limit, with big margin. A hard-cranked 33 W chord is the only thing that could find a per-port ceiling, and you never need to crank.
- **Action:** read the hub's actual adapter rating off its label; in the Stage-4 chord test, meter total 5 V draw. If the hub current-limits a port, spread the 7 amp leads across non-adjacent ports (the hub has 10). The wall path is still the reliable demo path — just don't oversell it as "infinite."

Everything else in `03` (Mode B 3/2/2 split, 3-amp bus on USB-C, the **5.1 kΩ CC resistor** on cut USB-C feeds, meter-don't-trust-the-display) stands — those are correct and important.

---

## 6. Tightened "what connects to what" — the exhaustive connector list

Every physical connection in the system, in order. If a link isn't here, it shouldn't exist.

| # | From | To | Connector / method | Carries | Gotcha |
|---|---|---|---|---|---|
| 1 | Laptop USB-A ×3 | Vantec V1/V2/V3 | USB-A captive cable | data + Vantec's own 5 V | Use **fixed, labelled ports** (§2A). |
| 2 | Vantec jack (×4/card) | SK473 captive 3.5 mm plug | 3.5 mm TRS plug → jack | line-level stereo (2 ch) | Tip=L, Ring=R, Sleeve=GND. One plug = one amp = 2 ch. |
| 3 | Wall **or** Anker | SK473 5 V lead (cut) | USB / soldered 5 V bus | **5 V power only** | Mode A: into hub port. Mode B: onto the 3/2/2 bus (§5, `03`). |
| 4 | SK473 output `L+ L−` | actuator (string/fret) | **soldered 2-wire pair** | amplified BTL drive | §1: isolated pair, never common `−`. |
| 5 | SK473 output `R+ R−` | the *other* actuator on that amp | soldered 2-wire pair | amplified BTL drive | same. |
| 6 | Laptop | webcam | USB (or built-in cam) | video | ArUco marker on headstock for homography (`08`). |
| 7 | Laptop | mic / contact mic | USB / 3.5 mm | guitar audio | clip near the soundhole; keep F0 clean in a loud room. |

**Things that must NEVER connect:** amp 5 V ↔ any 3.5 mm pin; actuator wire ↔ a Vantec; one channel's `−` ↔ another's anything; amp power from the laptop/Pi USB ports.

There are exactly **14 soldered actuator pairs (28 joints) + 7 power-lead taps + (Mode B) 3 bus feeds.** That's the entire soldering scope. Count your joints against this.

---

## 7. Soldering — the order that prevents rework (sharpens `04`)

Build **one full channel end-to-end first**, prove it, *then* mass-produce. Do not gut all 7 and solder 28 joints before testing one.

1. **Gut ONE SK473** (`04` Job 1). Keep: 5 V lead, 3.5 mm plug, volume pot (set ~60%).
2. **Solder ONE actuator** to `L+/L−` (pre-load heat-shrink first — it's a closed tube, can't be added later).
3. **Tone-test that one channel:** Vantec jack → this amp → 5 V → play a 230 Hz tone on the laptop. The 40 mm should buzz; mount it on a puck + strap and confirm it's **felt**. ← this is your real M1.
4. Only now: **gut the other 6, solder the remaining 13 actuators**, tone-testing **each amp** before gluing.
5. **Hot-glue strain relief only on boards that passed** (`04`/`06`). Glue carries the wire load; the joint never does. Anchor **both** ends of every run (board edge *and* actuator body).
6. **Label every wire on both ends** with its channel number *as you solder* (`05`). A mislabeled channel is a silent bug felt in the wrong place.
7. **(Mode B) build the 5 V buses last** (`04` Job 3): meter to find 5 V vs GND on each cut lead, join all 5 V to one rail / all GND to one rail, **CC resistor on USB-C feeds**, keep the two rails physically apart, shrink everything.

Joint quality: tin first, heat the joint not the solder, ~1–2 s, shiny cone; fine tip on the amp pads, inspect under light for bridges. (`04`)

---

## 8. The resolved open questions (update `13`)

| `13` item | Resolution |
|---|---|
| 2 W actuator impedance | Either 4 Ω or 8 Ω is fine on PAM8403. **Meter one coil** (probe the two tabs, expect ~3–4 Ω → it's a "4 Ω"; ~6–7 Ω → "8 Ω"). If 8 Ω, **boost those 6 string channels ~+3 dB in software** so strings aren't half as loud as frets. |
| Old SK473 present? | If only 6 amps → **12 channels**: drop the 2 reserved back zones (z7/z8), keep 6 strings + 6 torso fret-zones. No re-wire of the rest. Design accommodates this. |
| Webcam | Laptop cam works for a v1; an external USB cam aimed *down the neck* is better. **Print the ArUco marker** (`cad/README` has a slot for taping it to the headstock). |
| Enclosure | **Now specified** — `cad/` (box + power cradle + actuator pucks), sized to the FlashForge 5M 220³ bed, vented, with strain-relief comb and zip-tie anchors. |
| Wire for body runs | §3 above — light **stranded** for actuators, 18 AWG only for the power bus. |

---

## 9. The honest demo-reliability stack (aligns with `07` / `09`-assembly)

- **Judged run = Mode A (wall), known song, pre-processed transcription, on the pre-calibrated wearer.** Lowest failure surface.
- **Walk-around flex = Mode B (cordless)** at felt level.
- **Single biggest schedule risk = the 3-Vantec ALSA bring-up (§2).** Do it Stage-1, before soldering, exactly as `09` gates.
- **Single biggest physical risk = actuator coupling (§4).** Prove one puck before scaling.
- Keep a **pre-recorded video** of the working loop as the ultimate fallback (`07`).

---

## 10. Laptop connection + power — exactly what plugs into what

**The brain is the laptop, and the Pi is cut.** There are only ever **two USB "trees,"** and they're independent (they share only the common signal ground via the 3.5 mm sleeves, §0):

- **Tree 1 — DATA: laptop → 3 Vantecs.** The Vantecs are USB sound cards; they need data *and* draw their own power from USB (~1 W each, trivial). They must be downstream of the laptop.
- **Tree 2 — POWER (5 V): wall hub *or* Anker → the 7 amps.** The amps only take 5 V; they exchange no data.

### Recommended: **one powered hub does both** (cleanest "one plug + one cable to the laptop")
The 10-port powered hub is *both* a data hub and a 5 V source. So:
```
wall outlet ─► 10-port powered hub (its own 12V/≈50W adapter)
                 │ upstream USB cable ─► LAPTOP        (carries the 3 Vantecs' audio data)
                 ├─ 3 ports ─► 3 Vantecs              (DATA + their power)
                 └─ 7 ports ─► 7 SK473 amp USB leads  (5 V POWER only)   = 10 ports, exact fit
LAPTOP ─► its own charger/battery   ·   webcam + mic ─► laptop USB
```
That's **one wall plug (the hub) + one USB cable from the hub to the laptop + the laptop on its own power.** Yes — **portable/one-plug + a laptop link is sufficient.** (Per-port caveat from §5: at *felt* level every amp draws ~0.5 A, well under any port limit; don't crank.)

### Cordless variant (the walk-around flex)
```
LAPTOP ─► 3 Vantecs (straight into laptop USB-A, or a small bus-powered DATA hub)
ANKER 737 ─► soldered 5 V bus (3/2/2 split, 3-amp bus on USB-C, CC resistor) ─► 7 amps
LAPTOP + ANKER both on battery → no wall plug at all.
```
Here the amps leave the hub and run off the Anker; the Vantecs go straight to the laptop. The only tether left is the **3-Vantec USB run to the laptop** — short, and the laptop can sit on the cart next to the player.

### If your laptop is USB-C-only (e.g. a MacBook)
You need a **USB-C → multi-USB-A** adapter/dock for the upstream link (the hub's upstream or the 3 Vantecs). Confirm the dock enumerates **3 independent USB-audio devices** — some cheap docks collapse identical devices. The hub-does-both topology needs just **one** USB-C port on the laptop.

### The shopping delta this implies
- **1× USB upstream cable** for the hub→laptop link (and a **USB-C→USB-A(F)** adapter if the laptop is USB-C-only).
- Decide **Mode A vs B for the judged run** (recommend A). For Mode A you can leave the SK473 USB plugs **intact** (just plug into the hub); for Mode B you cut them for the solder bus — so don't cut them until you've committed (or add short USB-A pigtails to keep both options).

---

## 11. SK473 reality (live teardown, Jun 20): it's 6 stereo PAIRS = **12 channels**, and the amp *is* separable

What a "box" actually is: each SK473 box is a **2.0 desktop set** — **one stereo PAM8403 board** lives in the *master* speaker (with the USB lead, the 3.5 mm plug, the volume knob, and the master's own driver), and a **passive *slave* speaker** hangs off a 2-wire cable carrying the amplified **R** channel. So **per box = 1 board (2 ch) + 2 drivers.**

- **Count correction: 6 boxes × 2 ch = 12 channels** (not 24, not 14). Map → **6 back strings + 6 torso fret-zones**, drop the 2 reserved back zones (this is exactly the §8 fallback). Update `config/channel_map.json` (remove ch 13–14) + the body map. *(If a 7th prior SK473 board exists and opens, that's +2 = 14.)* The **24× 40 mm speakers stay our body actuators** — 12 used, 12 spare.
- **"The amp is connected to the speaker" ≠ fused.** The board's **L** output is soldered to the master's driver; its **R** output runs out the cable to the slave driver. Those are **2 snippable joints, not a weld.** Snip both stock drivers off and the board is free. The hard part you're hitting is **cracking the plastic case**, not separating the amp.
- **Open only the MASTER speaker per box** (the one with the board / USB / knob / 3.5 mm). Ignore the slave's enclosure entirely — you only want the board. So it's **6 cases to open, not 12.** You don't even have to fully extract the board — open just enough to disconnect the stock driver and reach the **L+/L−/R+/R−** output pads.
- **Even less soldering than `04` implied:** keep the **USB and 3.5 mm plugs intact** (Mode A) → USB into the hub for 5 V, 3.5 mm into a Vantec jack, **zero input-side cutting.** The only solder is: **remove the 2 stock drivers, attach 2 of our 40 mm to the board's L and R pads** → ~**12 output joints total.** (Cut the USB lead only if you go Mode B / Anker bus.)
- **Opening a stubborn case:** screws usually hide **under the rubber feet or the back label**; else pry the seam with a flat screwdriver; **ultrasonic-welded** seams → score along the seam with a utility knife / rotary tool. Patience here, not force (force cracks the board).

### ❌ Why NOT to strap the whole boxed speakers to the body (the tempting shortcut)
- A **boxed cone speaker radiates into AIR** — it's built to be *heard*. Strapped to the body it's **loud and barely felt**; the box wall isolates the cone's motion from your skin. Haptics needs the **opposite**: a *bare* driver with a contact button on the cone, pressed to the skin (the `actuator_puck`, §4). That coupling is the entire reason it's felt, not heard.
- **Bulk/weight:** ~12 plastic speaker boxes (~340 g each ≈ **4 kg**) is not a wearable vest, and you can't place 12 boxes at the ≥4–5 cm spacing the encoding needs.
- **The amp stays in the enclosure; only the bare 40 mm + wire + puck go on the vest.** The amp does **not** have to live on the body — that worry came from the false "amp is fused to the driver" premise. Snip the stock driver, run a long lead to a 40 mm on the vest, board stays in the box. **The `cad/` enclosure is unchanged** (now 6 boards = even more room).

---

## 12. UPDATE (Jun 20 teardown): use the SK473's OWN drivers (KHD 3 Ω/5 W), and the ≤2-at-once power win

Live finding: the SK473's built-in drivers are **bigger/better than the 40 mm we bought** and are **factory-matched to the amp (KHD, 3 Ω, 5 W)** — the *safest possible* load, because the board was literally built to drive them. **Switch the body actuators to the 12× de-housed SK473 drivers**; the 40 mm become spares. (This is *not* "strap the boxed speaker on" — §11 still stands: you **de-house** the driver so the bare cone couples to skin.)

- **3 Ω on PAM8403:** below the 4 Ω nominal min, but it's the **factory pairing** and we run **felt-level (~1 W) with ≤2 channels ever active** → nowhere near the current/thermal limit. No impedance worry. ("Subwoofer"-ish heavy drivers also tend to feel *punchier* — likely a win; tune freq in `docs/18`.)
- **Each driver is hardwired (red/black) to its amp.** Don't fight that joint — decide where the **amp** lives:
  - **(B) Amps in the box (RECOMMENDED — robust + the soldering is the easy kind):** splice-extend each driver's red/black with your **18 AWG** to reach the vest; amps + pots stay in the vented `cad/` box (sized for 6–7 boards). Only **drivers + wire** on the body → clean, survives being worn/handled. The ~24 joints are **wire-to-wire splices on the existing leads — not tiny-pad SMD work**, so they're beginner-easy.
  - **(A) Amps on the vest (zero output soldering):** keep the factory driver↔amp wiring intact; mount the 6 boards on the vest by their drivers; run **6× audio (3.5 mm) + 6× 5 V (USB)** out to the vest (needs cheap extension cables). Boards are ~10 g and barely warm (≤2 active). The printed box then shrinks to just **3 Vantecs + power**.
  - Pick **B** unless the splices are a dealbreaker; **A** trades a messier/more-fragile body for no soldering.
- **The volume pots — ignore/bypass them; set level per channel in SOFTWARE** (`docs/18` Exp. 4). You **can't "overclock" past the chip's fixed gain** — max pot is the ceiling, and *punch comes from coupling + drive-frequency, not overdrive* (clipping cooks the coil and feels worse). **So don't fear breaking a pot while cracking the case:** worst case, hardwire the input past it = permanent full gain, and control level digitally (which we want anyway for calibration). The pot is **optional**.
- **The ≤2-simultaneous power win (Aditya's insight — correct):** chords render as a **sequential strum sweep** (~40 ms stagger, 30–80 ms pulses) → **never more than ~2 drivers active at once.** This **collapses the power budget**: doc 03's "all-14-at-once ≈ 33 W" case **never happens**; real peak is ~**2–3 W**. Any 5 V source runs the rig with absurd margin, **and you can drive each active channel harder for punch** with zero brownout risk. (Supersedes the doc 03 worst-case framing.)
- **Coupling unchanged:** de-house the driver → **contact button on the cone + rigid backer on the magnet + firm strap** (§4 / `actuator_puck`). **Measure the driver Ø and set `spk_dia`** in `actuator_puck.scad`, then re-render (the puck is parametric).
- **Channel count stays 12** (6 boards × 2). Map → 6 back strings + 6 torso fret-zones.

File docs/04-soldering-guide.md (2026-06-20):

# Soldering guide

Three jobs: (1) gut each SK473 into a bare amp brick, (2) attach actuators, (3) build the 5V bus (cordless mode). Skill bar: basic soldering. Budget ~10 min per amp.

**Before you start:** read [06-safety.md](06-safety.md). Every joint gets heat-shrink + a hot-glue strain-relief blob — non-negotiable, because 18 AWG zip-cord weight tears unrelieved joints. **Always pre-load heat-shrink onto the wire before you solder** — it is a closed tube and cannot be slid over a joint once both ends are terminated.

---

## Job 1 — gut an SK473 (×6)

What's inside an SK473:

```
USB lead (5V power) --+
                      +--[ PAM8403 amp board ]-- 2 output pairs --> 2 stock KHD 3Ω/5W drivers
3.5mm plug (audio) ---+        + volume pot
```

1. **Open the housing** — 3–4 screws or pry the clips.
2. **Identify the board.** It has: a USB power lead (red 5V / black GND), a captive 3.5 mm plug, a volume pot, and two speaker-output pairs (L+/L−, R+/R−) running to the two stock KHD 3 Ω/5 W drivers.
3. **De-house the two KHD drivers, keep them.** They are the actuators (mass-y, punchy). Desolder them from the output pads, note pad polarity (silk marking or wire color), and set the bare drivers aside for coupling (`docs/15`). The 40 mm LEO speakers are spares — do not use them here.
4. **KEEP:** the USB power lead, the 3.5 mm plug, and the two KHD drivers. The volume pot is **bypassed — level is set per channel in software** ([06-safety.md](06-safety.md)), so leave it as found (you can't exceed the chip's fixed gain anyway).

Result: a bare 2-channel amp brick — power in, 3.5 mm audio in, two output pad-pairs — plus its two de-housed KHD drivers.

---

## Job 2 — attach actuators to the amp (×12)

The actuators are the de-housed **KHD 3 Ω/5 W drivers** from Job 1. The PAM8403 is **BTL/filterless** — both terminals of each channel (`+` and `−`) are driven, neither is ground. **Hard BTL rules:** never tie any output `−` to ground; never join two channels' `−`; **every driver gets its own isolated 2-wire pair.**

1. **Cut a 2-wire 18 AWG zip-cord pair to length** — long enough to reach the driver's body position from the amp, plus a service-loop allowance ([06-safety.md](06-safety.md)). These runs are variable length; cut per the wiring map.
2. **Pre-load** two pieces of heat-shrink onto each lead and slide them well clear of the ends.
3. **Tin** the amp output pads and the KHD driver tabs.
4. **Solder one isolated pair to L+/L−, one isolated pair to R+/R−.** Keep **+ to +** consistent across the *entire* array (phase matters for clean multi-actuator behavior).
5. **Slide the heat-shrink over each joint and shrink it.**
6. **Tone-test now (before any glue): feed 5 V + a tone through this amp → both KHD drivers should buzz.** Label the channel (e.g. `V1-front-L`). If a board fails, swap in a spare — **do not** pot a board you haven't verified.
7. **Only on a board that passed:** hot-glue a strain-relief blob anchoring the wire to the board edge and to the driver body. The glue carries the wire load, never the solder. (Also anchor the run to the enclosure within a few cm of the amp — see [06-safety.md](06-safety.md).)

Impedance note: the KHD drivers are **3 Ω/5 W** and factory-matched to the PAM8403, so 3 Ω is safe at our felt level. Per the hard BTL rule, **one driver per channel on its own isolated pair** — never common two channels' `−`, never parallel drivers on one channel.

---

## Job 3 — build the 5V solder bus (cordless / Mode B)

Goal: power all 6 amps from the Anker 737, split across ports so chords don't brown out. See [03-power.md](03-power.md) for the per-bus split math (3/2/2; the 3-amp bus must land on a USB-C port).

1. **Cut each SK473's USB power lead**, expose 5 V (red) + GND (black). **Meter to confirm** which is which — do not trust color blindly.
2. **Group the amps** to match the port split (Bus 1 = 3 amps → USB-C; Bus 2 = 2 amps → USB-C; Bus 3 = 2 amps → USB-A).
3. For each bus: **pre-load heat-shrink**, then **join all 5 V leads to one rail, all GND leads to one rail** (a short length of 18 AWG as the rail backbone).
4. **Feed each bus from an Anker port** via a sacrificial cable:
   - **USB-A feed (Bus 3):** any USB-A cable — cut, meter VBUS/GND, solder VBUS→5V rail, GND→GND rail. USB-A always outputs 5 V.
   - **USB-C feed (Bus 1, Bus 2):** a cut USB-C cable presents **no CC pull-down**, so a USB-C PD source like the Anker will **refuse to turn the port on**. Add a **5.1 kΩ resistor from each CC line (CC1, CC2) to GND** on the cable end going into the Anker, so the source detects a sink and enables 5 V. *Simpler alternative:* use a USB-C→USB-A-female adapter on the Anker port, then a USB-A cable (the adapter handles CC) — no resistors needed.
5. **Shrink all joints.** Keep the 5 V rail and GND rail physically separate — a 5V–GND touch shorts the Anker.
6. **Verify:** meter each bus's 5 V and (during the chord test) its current in series.
7. Wall-mode alternative (Mode A): skip the bus — plug each SK473's USB lead into the 10-port hub instead. The hub's 50 W handles all 6, no CC resistors, no split.

---

## Joint quality
- Tin first, heat the joint not the solder, ~1–2 s, shiny cone (not a dull blob).
- Fine tip on the small amp pads; don't bridge adjacent pads.
- Inspect every joint under light before powering.
- Heat-shrink (pre-loaded) + hot-glue **every** joint (insulation + strain relief), glue only after the tone test passes.

## Order of operations (matches [09-assembly-checklist.md](09-assembly-checklist.md))
**Gut all 6 → attach + tone-test each amp individually → build the bus → powered chord/stress test → ONLY THEN mount actuators on the body.** Never mount before a board passes its tone test, and never pot strain relief before the tone test.

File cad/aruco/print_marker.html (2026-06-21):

# Tactus fretboard fiducial — ArUco 4×4_50, id 0

Print this page in Chrome → Print → set Scale: 100% / "Actual size" (NOT "Fit to page"). Verify with a ruler: the bold square should measure exactly 30 mm.

30 mm marker · PRIMARY — use this one

24 mm marker · alternate

36 mm marker · alternate

1. Cut out the 30 mm marker keeping the full white border (the quiet zone) — the detector needs it.
2. Keep it perfectly FLAT — never fold it. A crease destroys the corner geometry the homography rides on. Glue it to a thin stiff card if the paper curls.
3. Tape it flat on the neck just past fret 6–7 (toward the body), or right at the nut — either way coplanar with the fretboard, beside the 1–6 fingering zone so your hand never covers it. Avoid the angled headstock: it tilts ~15° off the fretboard plane, so its homography isn't the fretboard's and your distance feature d gets noisy.
4. Frame the camera tight: nut → fret 7, marker in view. Jot the printed size (30 mm) in the session notes.

marker_4x4_50_id0.png is the raw bitmap if you want to place it yourself.

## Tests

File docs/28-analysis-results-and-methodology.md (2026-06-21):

# 28 — Analysis results & methodology (the rigor + the story)

> **Status:** live results doc for the Tactus offline-analysis phase (Jun 21). Pairs
> with `docs/27` (the experiment plan), `truth.md §6` (the AIML direction), and the
> code in `software/ai/analysis/`. Every number here is from the pipeline on the
> real captured data; preprocessing is fit on train folds only; one player → k-fold
> with the generalization caveat stated. **The honesty is the credibility.**

---

## 0. What we set out to prove

Tactus reads a guitar player's fretting hand and the cleanliness of each note from a
**webcam + a mic**, then turns it into one correction. Two unsolved perception
problems carry the AI:

1. **Quality** — is a note/chord *clean*, *buzzed*, or *muted*? (audio-led)
2. **Position** — where is each finger, even when the hand **occludes** the contact
   point? (vision-led, beat raw MediaPipe)

Plus the bet that makes chord feedback tractable without a per-chord fault library:
**a buzz primitive learned on single notes transfers to chords** through the
non-harmonic residual (H2).

This doc reports, with held-out numbers and named geometry, how far each got.

---

## 1. The data & the integrity discipline

**Dataset (one player `aditya`, one guitar `acoustic-1`, 83 recordings):**

| set | recordings | events | what |
|---|---|---|---|
| single-note | 72 (session `2026-06-20-2332`) | **432** | clean/buzz/muted × 6 strings × frets 1–6, 24 runs/class |
| chord-stream | 11 (`0145`,`0244`,`0249`,`0305`) | **600** | Am/C/G/D/E/A/Dm/F/Em, strummed, pose varied per ~10 strums |
| calib | 6 keyframes | — | `acoustic-1` digital twin (homography) |

**Segmentation was the linchpin — and it was broken.** A blind
`librosa.onset_detect` over-fired ~4–5× on ringing/buzzy notes (206 onsets for 40
strums; docs/26). The fix: **pin segmentation to the manifest's own ground truth**,
since the capture tool cues every note/strum to a metronome and records the count:

- **single notes** → take the `expected_note_count` (=6) strongest onsets, ≥0.5 s
  apart, time-ordered → `frets[k]`. Result: **432 events, exactly 6.00/run, 0 runs off.**
- **chords** → one event per `chord_sequence[k].cue_ms` (strongest onset in
  [cue−0.15, cue+0.45] s), labeled with that strum's chord. Result: **the 206→40
  over-fire is gone; every strum gets its true chord.**

**A data-integrity bug we found and fixed (this is the rigor):** chord-stream
`run_id`s repeat across sessions (`chordstream_aditya_001` exists in all four chord
sessions), so `event_id = run_id#k` **collided** — 220 duplicate ids. A naive
key-join on `event_id` cross-multiplied chord rows (features_fused → 4512 rows from
1032). We caught it via a row-count sanity check, **made `event_id` globally unique**
(`session::run_id#k`), and rebuilt. Single-note experiments were never affected
(their ids are unique); the chord analyses pair positionally / on the fixed ids.
*Finding and killing this before it reached a result is exactly the discipline we
claim.*

**Labels = the prompt.** Audio F0 / harmonic content only cross-checks. On *clean*
single notes the measured F0 agrees with the prompted fret **70.7%** of the time
(buzz 32%, muted 17% — dead/buzzy notes have no clean pitch, as expected), which is
our segmentation sanity signal, not a label source.

**One correction baked into ground truth:** the played **G is the 4-finger voicing**
`[3,2,0,0,3,3]` (B and high-e fretted), not the capture tool's stored 3-finger
open-B shape — corrected everywhere a G is labeled.

---

## 2. The pipeline (reproducible, end-to-end)

```
segment → features (audio 26  +  vision 13  +  harmonic-residual 11)
        → standardize → PCA(95%) → LDA  → d′ / confusion / Fisher / silhouette (k-fold)
        → 3D semantic viz  +  Redis vector memory
```

`software/ai/analysis/`: `schema.py` (frozen contract), `segment.py`,
`features_audio.py`, `features_vision.py`, `features_residual.py`, `collapse.py`,
`run_pipeline.py`. Vision runs in a **separate Python 3.11 venv** (mediapipe has no
3.14 wheel; pinned to 0.10.21 for the `solutions.hands` API) and is merged back as a
CSV — the analysis/serve split mirrors `truth.md §2`. Re-runnable from raw in ~10 min.

---

## 3. E1 — clean / buzz / muted separability (the rigor centerpiece)

**Audio alone separates the three quality classes.** 432 single notes (144/class),
standardize → PCA(95%, 18 comps) → LDA, fit on train only.

- **Held-out accuracy 81.2% (5-fold), 86.2% (80/20 holdout)** vs **33.3% chance.**
- Pairwise d′: **clean·buzz = 1.93, clean·muted = 3.70, buzz·muted = 1.81.**
- Confusion: clean is cleanly separable (recall 0.84–0.97); the fuzzy boundary is
  **buzz↔muted** (buzz recall 0.67, leaking into muted) — physically sensible (a
  hard buzz and a dead note share broadband, low-harmonic energy).

**Named axes (the "geospatial semantic meaning").** Feature-space loadings
`W = pca.componentsᵀ @ lda.scalings`:

- **LDA-1** ← `hnr`, `mfcc_1`, `chroma_peak` — harmonicity / timbre.
- **LDA-2** ← `chroma_peak`, `spec_flatness`, `mfcc_6` — pitch-clarity vs noisiness.
- 3rd view axis (top residual PC) ← `spec_centroid`, `spec_rolloff`, `spec_bandwidth`
  — spectral brightness.

**The rigor centerpiece (truth.md §6) — audio-only vs vision-only vs fused.** Same
clean/buzz/muted task, three feature sets, k-fold:

| feature set | accuracy | d′ clean·buzz / clean·muted / buzz·muted |
|---|---|---|
| **audio-only** | **0.803** | 1.93 / 3.70 / 1.81 |
| vision-only | 0.382 | 0.17 / 0.52 / 0.30 |
| fused | 0.808 | 2.05 / 3.86 / 1.87 |

Reading: **quality is audio-led, and fusion does NOT improve quality** (audio ≈
fused; vision-only barely clears the 0.33 floor because the pose is
registration-limited). That cleanly validates the **two-stage split** — quality =
audio (Stage 2), position = vision (Stage 1) — rather than one blended model. It is
the honest version of the centerpiece: fusion is the right architecture *because* the
modalities answer different questions, not because vision rescues audio.
`data/analysis/exp/separability_3way.json`.

**Artifacts:** `data/analysis/exp/viz_clean_buzz_muted_3d.html` (self-contained,
offline-openable rotating Plotly scatter, axes labeled by the loadings above),
`…_3d.png`, `viz_lda_2d.png` (2σ cluster ellipses).

---

## 4. E3 — harmonic-residual mono→poly transfer (the key bet, H2)

Null the **known** harmonics (the prompt's expected pitches) → the **residual** holds
only non-harmonic (fault) energy, computed identically for mono notes and chords.

- **Mono buzz axis** (clean vs buzz, residual features, k-fold): **d′ = 1.77 ± 0.31,
  accuracy 0.83.** (`res_energy_ratio` alone d′ = 0.61 — the full residual vector
  ~triples it.)
- **Transfer (466 chord residuals projected on the mono-fit axis):** chords are
  **statistically indistinguishable from mono-CLEAN** (KS p = 0.48) and **distinct
  from mono-BUZZ** (KS p ≈ 5e-48); 98.9% land inside the mono range. A real **~10%
  buzz-side tail** carries **2.3× the residual energy** of clean-side chords — the
  axis orders chords by genuine non-harmonic content.

**Verdict: H2 supported as a geometric claim** (most strums clean → land on the clean
primitive; the buzzed minority move along the *same* axis toward the buzz primitive).
**Honest limits:** chords have no per-string clean/buzz labels (so the tail's
magnitude is uncalibrated), and it's one player. Money shot:
`data/analysis/exp/e3_transfer.png` / `.html`.

---

## 5. E9 — Redis semantic memory ("you keep muting the A")

Native **Redis Vector Sets** (VADD/VSIM, no RediSearch needed). 432 single-note
events → 28-d audio features → PCA-16 → L2-normalized → indexed with per-event
metadata.

- **Neighbor coherence vs base rate (k=10, over all 432):** class **0.676 = 2.03×**
  chance, string **0.429 = 2.58×** chance — the embedding is semantically coherent,
  not random.
- **Money query** `search_by_filter('muted', string_num=5)` → **90% muted (2.7×), 44%
  on the A string (2.6×)** — directly powers *"Tactus noticed you keep muting the A."*
  Redis as **long-term agent memory** of a player's recurring mistakes.

Module `software/ai/analysis/exp/redis_retrieval.py`; report
`data/analysis/exp/redis_retrieval_report.md`.

---

## 6. E7 / E8 — vision position vs raw MediaPipe (honest: registration-limited)

MediaPipe detects the fretting hand in **88% of frames** (907/1032) and the per-finger
model pipeline trains end-to-end (GroupKFold by recording, 1661 per-finger rows from
chord strums). But the honest result here is a **negative with a clear, fixable
cause** — and reporting it straight is the point.

**E7 — per-finger fret.** Our model beats raw MediaPipe by a mile (fret MAE
**3.81 → 0.45**; occluded **4.03 → 0.41**) — but that gap is largely an artifact: the
**calibration-pose homography does not register the gameplay video** (≈0% of
fingertips map onto the board, board-Y systematically negative), so the raw-MediaPipe
baseline is effectively un-registered and trivially bad. Against a **majority-class
floor (fret MAE 0.43)** our model only ties (0.45); it edges the floor on *occluded*
fret (0.41 vs 0.44) and on *string* accuracy (0.24 vs 0.17). We beat MediaPipe, but
not a dumb baseline — the per-finger fret signal is weak. A **signal ablation is
decisive**: vision-pose-*only* is **worse than the majority floor** (fret 0.54 vs
0.43, string 0.17 vs 0.23), and the model's entire lift over chance comes from the
**finger→fret label correlation** (finger identity alone — *zero pixels*). The
fretting-hand geometry in this footage carries no recoverable per-finger signal.

**E8 — pose→chord (the salvage).** Relative hand shape needs no absolute
registration, so we tested whether the fretting pose alone identifies the chord,
**cross-recording** (train one mixed strum-stream, test the other, GroupKFold by
session). Result: **0.167 — only 1.5× the 1/9 chance** (stratified within-pool is the
same, 0.162), because the pose features are derived from the same broken board mapping.

**Honest verdict on H4 (beat MediaPipe at occluded position): NOT supported on this
data.** The bottleneck is concrete: a single hand-clicked **calibration** homography
cannot register frames where the guitar is at gameplay angles. We then **tested** the
obvious fix — per-frame markerless registration (`e7b_register.py` on 200 gameplay
onset frames) — and it **also fails: 0% locked, median residual 62.5px**, because the
fretting hand occludes the neck at every chord onset and the blurred, oblique neck
defeats fret-line detection. So the bottleneck is **capture-side, not software**: the
real fix is a board-visible camera angle (higher / side, hand not covering the frets),
not more code. That is a one-line change to the capture rig, not a hackathon-night
model. What is real: the pipeline, the 88% hand detection, and a
precise diagnosis of exactly why the position accuracy isn't there yet.
`data/analysis/exp/beat_baseline_table.csv`, `money_shot_fret_mae.png`,
`e8_pose_chord_confusion.png`.

---

## 7. E2 / E4 / E5 — supporting experiments

**E2 — String-ID from timbre: works.** RandomForest predicts which of 6 strings a
single note came from at **0.688 accuracy (5-fold, 4.1× the 1/6 chance)**; **69% of
errors are an adjacent string** (the expected neighbor ambiguity). Timbre carries
real per-string identity. `data/analysis/exp/e2_confusion.png`.

**E4 — Per-chord μ_c & off-detection: the off-detector is the usable primitive.**
Mahalanobis distance to a chord's mean (Ledoit-Wolf covariance) flags "this strum
doesn't match the expected chord" at **AUC 0.899**. But **chord *identity* from audio
is not reliable here** — nearest-μ_c chord-ID is 0.55 under StratifiedKFold yet
**collapses to ≈chance (0.03) within a single mixed strum stream**, because the
collection has only 8 chord run_ids (7 are single-chord takes), so `run_id` is nearly
collinear with the chord label and per-fold leakage inflates the optimistic number.
We report all three CV schemes and the deployment-realistic one. Verdict:
**chord-match/off-detection yes, chord-ID-from-audio no** — consistent with "lean on
position for chords." `e4_chord_scatter.png`, `e4_offdetect_roc.png`.

**E5 — Muted/dead-note detection: works, and confirms the two muting flavors.** A
harmonic-presence score (energy at f0 + 5 harmonics / total) separates muted from
clean+buzz at **d′ = 1.39, AUC 0.82** (means: muted 0.15, buzz 0.42, clean 0.55). The
muted distribution is **bimodal** (2-component GMM beats 1 by BIC): a spike at ~0
(**body-tap percussion**) + a lobe at 0.1–0.5 (**palm-mute**) — exactly the two
muting techniques in the capture. `e5_harmonic_hist.png`, `e5_harmonic_roc.png`.

---

## 8. Rigor & honest caveats (read before believing any number)

- **Leakage-tested (adversarial).** Single-note runs are grouped (one `run_id` =
  one string+class+pluck), so random k-fold could leak a take's acoustics. Re-run
  under **GroupKFold-by-run**: clean/buzz/muted is **0.795 grouped vs 0.796 random
  (drop 0.001)** — genuinely not a memorization artifact; string-ID is **0.62 grouped**
  (vs 0.66 random). The headline survives holding out whole recordings.
  `data/analysis/exp/adversarial_groupcheck.py`.
- **One player, one guitar.** No leave-one-player-out is possible → every result is
  k-fold / GroupKFold and is **optimistic for new players**. The single biggest
  unlock is a second player's hand.
- **Preprocessing fit on train folds only**; reported at natural base rates.
- **The twin homography is from hand-clicked corners** → coarse registration; we do
  not claim sub-pixel `d`. Reported `d` is relative/coarse, never cm.
- **Chord audio-quality labels are noisy** (chords were often slightly buzzed) → we
  lean on position for chords and report chord-quality transfer as geometry, not
  calibrated accuracy.
- The prompt is the label; F0/harmonic content only verifies.

---

## 9. The story for a judge

We took a hand the camera can't fully see and a buzz the mic can't explain, and made
both **legible**: three quality classes that separate on audio alone (and you can
*see* them separate, axes named by what they mean); a buzz primitive that **transfers
from single notes to chords** through the physics of the residual; and a memory that
**recognizes your recurring mistakes**. The rigor isn't decoration — we found and
killed a data-integrity bug mid-run, we pin every claim to held-out folds, and we say
out loud where one player and a hand-clicked ruler limit us. *That* is why the numbers
are believable.

---

## 10. Adversarial review & evidence-based next steps

We attacked our own headline.

**Leakage — tested, clean.** Single-note runs are grouped (`run_id` = string+class+
pluck), so random k-fold could leak a take's acoustics. Under **GroupKFold-by-run**,
clean/buzz/muted is **0.795** (vs 0.796 random — drop 0.001) and string-ID **0.62**
(vs 0.66). The headline is not a memorization artifact.

**Where we sit vs the literature (web-checked):**
- Note **quality** (clean/buzz/muted) is **not a standard MIR task** — the field
  benchmarks transcription / tablature / chord-ID on GuitarSet, not buzz/mute. So our
  quality classifier is a *contribution*, not a race to beat a number.
- The vision gap is a **known, solved-in-principle** problem: markerless deep-learning
  fretboard + fingertip detection works from a free webcam (no fixed neck camera), and
  occlusion-robust keypoint detection is documented. Our failure was a **classical
  Hough** detector on hand-occluded frames; the SOTA fix is a **learned** fretboard
  detector (TapToTab-style) and/or a board-visible camera angle.

**Three evidence-based improvements (no new capture for #1–2):**
1. **GuitarSet (6 players, public)** → cross-player validation of the audio pipeline +
   string-ID, directly attacking our one-player caveat. (No buzz/mute labels there, so
   *quality* stays single-player — but string-ID and the feature pipeline generalize-test.)
2. **Learned fretboard keypoint detector** to replace Hough → the documented path to a
   real beat-MediaPipe position result.
3. **Re-capture with the fretboard visible** (hand not covering the frets) — the
   one-line rig fix our registration failure points to.

Sources: [GuitarSet (ISMIR 2018)](https://archives.ismir.net/ismir2018/paper/000188.pdf),
[TapToTab (arXiv 2409.08618)](https://www.arxiv.org/pdf/2409.08618),
[Guitar Tablature via Computer Vision (Springer)](https://link.springer.com/chapter/10.1007/978-3-030-33723-0_20).

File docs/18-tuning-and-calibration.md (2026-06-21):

# 18 — Tuning & calibration: the on-body experiments (fill in Saturday)

> We're switching the body actuators to the **SK473's own 12× KHD 3 Ω / 5 W drivers** (de-housed) — they're mass-y, low-biased ("subwoofer") drivers, so they likely hit *harder* than the 40 mm, but their best drive parameters are entirely **surface/coupling-dependent** and must be found **on the body**. This doc is the experiment plan + a results table. It answers the three questions Aditya flagged: *optimal drive frequency, optimal pressure, how punchy.*

## The 4 knobs you're tuning
| Knob | What it changes | Sane start | Why it's not obvious |
|---|---|---|---|
| **Drive frequency** | which mechanoreceptors fire / felt strength | 150–200 Hz | Pacinian peak is ~250 Hz, but **heavy 3 Ω drivers often feel strongest LOWER (~80–160 Hz)** — more excursion, more force into tissue. Sweep it. |
| **Pulse shape (punchiness)** | how crisp/“tap”-like vs droney | 50 ms, sharp attack | Sharp attack + fast decay = punchy + more distinguishable; long flat = mushy. |
| **Coupling pressure** | felt strength + localization | snug strap + contact button | Firm preload drops the detection threshold a lot (docs/12); loose = heard, not felt. |
| **Per-channel gain (software)** | equal feel across all 12 sites | per-site, set by ear/feel | Body sensitivity varies by site; drivers vary unit-to-unit. **This is the volume control — in software, not the pots** (see docs/15 §12). |

## Experiment 1 — drive-frequency sweep (do this FIRST, per zone)
1. Mount one driver + puck on a back site, firm strap.
2. Play 500 ms tones at **60 / 100 / 150 / 200 / 250 Hz**; rate **felt strength 0–5** and how **localized** it feels.
3. Pick the strongest+cleanest. Repeat on a **torso** site (back and torso may prefer different freqs).

| Site | 60 | 100 | 150 | 200 | 250 | chosen Hz |
|---|---|---|---|---|---|---|
| back |  |  |  |  |  |  |
| torso |  |  |  |  |  |  |

## Experiment 2 — punchiness (pulse shape)
At the chosen freq, play pulses of **30 / 50 / 80 ms**, each with (a) flat envelope and (b) sharp-attack→fast-decay. Rate **punch** and **distinctness** (can you tell two quick taps apart?).

| ms | flat | sharp-decay | pick |
|---|---|---|---|
| 30 |  |  |  |
| 50 |  |  |  |
| 80 |  |  |  |

## Experiment 3 — coupling pressure
Loose vs snug vs tight strap; **with vs without the contact button** on the cone. Rate felt strength, localization, comfort. Pick the firmest that's still comfortable.

## Experiment 4 — per-channel gain calibration
Play the chosen pulse on **every** site at equal digital gain; rate relative strength; set a per-channel gain so all 12 feel **equal**. Store in `config/` (e.g. `encoding.json`). The 60-sec per-wearer staircase (docs/12) layers on top for each new body.

## Safety bounds (don't cross while experimenting)
- **Never drive to clipping.** A clipped Class-D output is near-DC into the voice coil → cooks the coil *and* feels worse (buzzy). Keep gain below visible/audible distortion.
- Driver surface **< ~40 °C**; 5 W is a thermal ceiling — you use ~1 W, so you're fine.
- Thanks to **≤ 2 channels ever active at once** (sequential strum, docs/15 §12) power is a non-issue — but per channel, stay at *felt* level, not max.

## Record the winners (these become the renderer defaults)
```
drive_freq_back:   ___ Hz      drive_freq_torso: ___ Hz
pulse:              ___ ms, envelope = ___
strap/coupling:     ___
per-channel gains:  [ ... 12 values ... ]
```
</content>

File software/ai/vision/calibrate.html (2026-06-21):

🎸 Tactus — guitar digital twin camera — server — 0 keyframes

### Calibrate · STEP 1 of 2 — map the guitar

After you save the poses here, run the recorder: python3 software/ai/capture/serve.py — it has the full start-to-finish steps on the page.

Pick your front camera, hold the whole guitar in frame (the same framing you'll record + play with) — make sure the nut, frets 1–7, and both neck edges are clearly visible — then Capture frame.

📸 Capture frame ↶ Undo point ✓ Save keyframe ↺ Re-capture

### Guitar

Guitar id

Camera

Enable camera

Same camera + framing you'll record/play with → the twin matches at capture AND demo time.

### Click the 4 neck corners

1 · nut × low-E (thickest string)

2 · nut × high-e (thinnest string)

3 · fret 7 × high-e

4 · fret 7 × low-E

After 4 points the green fret grid overlays — it should land on your real fret wires. Off? Re-capture and click more precisely. Tip: any guitar fret-dot inlays (frets 3/5/7) help you aim.

### Pose plan (capture each)

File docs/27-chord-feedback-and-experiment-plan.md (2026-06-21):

# 27 — Chord feedback, mono↔poly transfer, and the 3D semantic viz (analysis + experiment plan)

> **Status:** live plan for the analysis/ML phase (Jun 21). Pairs with `truth.md §6`,
> `docs/23` (cluster→advice semantics), `docs/24` (collection protocol), `docs/25`
> (data/feature format), `docs/26` (Aden handoff). The pipeline + capture tooling
> live on branch **`worktree-analysis-pipeline`** (`software/ai/analysis/`,
> `software/ai/capture/`, `software/ai/vision/`).
>
> This doc is the "go crazy with rigorous testing in many dimensions / many
> labelings" roadmap. Nothing here is committed-as-final ML; it is the set of
> first-principles experiments to run the moment the data lands, and which ones we
> believe will win.

---

## 0. The pivot (what changed — read first)

Fault taxonomy is now **clean / buzz / muted** (3 acoustically-distinct classes),
**not** the old `buzz-light` vs `buzz-placement` cause-split.

- **Why:** buzz vs muted vs clean are physically different sounds (rattle / dead
  thud / clean ring) → separable on **audio alone**, leave-one-player-out. The old
  light-vs-placement split is audio-ambiguous (same rattle, different cause) and
  needed vision `d` to even attempt — dropped from the core.
- **muted** is the new third class: too little pressure / not fretted → dead note.
- This supersedes `truth.md §6` Stage-2's buzz-cause inverse problem for the audio
  side. The vision side (occlusion → position) is unchanged and is now the headline.

---

## 1. Three deliverables

1. **Quality** — clean/buzz/muted, per note and (via transfer) per chord. Audio-led.
2. **Position (the technical-award play)** — vision pose → `(string, fret)` that
   **beats raw MediaPipe under occlusion.** Self-supervised by the known chord.
3. **The 3D semantic viz** — rotating PCA→LDA cluster space, named axes, showing
   the class separations + the mono→poly transfer + the beat-MediaPipe result.

---

## 2. Data inventory

| set | what | size | feeds |
|---|---|---|---|
| single-note | clean/buzz/muted × 6 strings × frets 1–6 × ~4 passes | ~432 events | quality classifier, string-ID, the buzz/mute **primitive** |
| chord-stream | 8 chords × ~100, clean, strummed, varied pose | ~800–1000 | per-chord **μ_c** signatures, **vision occlusion/position**, clean residual baseline |
| chord-fault (small) | a few chords × buzz/mute a known string | ~50–100 | **validate** the mono→poly transfer (NOT a full library) |
| calib | 6 keyframes (`acoustic-1`) → `twin.json` | 6 | homography for vision position |

**Labels = the prompt (manifest).** Per-chord rows carry `chord_sequence` +
`cue_ms` (stream), `strings_played` / `fingers_played` / `frets`, and
`string_classes` (fault). The prompt IS the label; audio F0 / harmonic presence
only cross-checks.

```
single notes ──► buzz/mute PRIMITIVE (mono)
                        │  (collapse harmonics)
clean chords  ──► μ_c   │
                        ▼
            shared low-dim ERROR subspace  ──►  chord feedback (no per-string library)
fault chords (small) ──► validate the transfer holds
```

---

## 3. Core hypotheses (first principles)

- **H1** clean/buzz/muted separate on audio alone. *(V: LOPO d′ / confusion.)*
- **H2 (the key bet) — harmonic-residual transfer.** Buzz is broadband,
  non-harmonic; the chord's *correct* content is harmonic and **known** (the
  prior). Collapse the harmonics → the **residual** carries the fault in a
  context-free subspace → the **mono buzz axis transfers to chords**.
  *(V: a buzz axis learned on mono separates clean-vs-buzz on **held-out chord
  residuals**.)*
- **H3** muted = a **missing expected harmonic** (known-chord prior) → per-string,
  no library. *(V: per-string muted recall via harmonic-presence check.)*
- **H4 (the award)** vision pose → `(string,fret)` **beats raw MediaPipe** under
  occlusion. *(V: fret error vs raw-MediaPipe vs audio-pitch truth, LOPO +
  leave-one-pose-out.)*
- **H5** fusion (position + quality + prior) gives per-string-ish chord feedback
  **without source separation**. *(V: per-string verdict accuracy vs best single
  modality.)*

---

## 4. Pipeline

```
segment → features (audio ~28  +  vision ~13  +  harmonic-residual)
        → standardize → PCA(95%) → LDA
        → metrics (pairwise d′, confusion, Fisher, silhouette) under LOPO
        → audit (one-screen) + 3D rotating viz
```
Branch `worktree-analysis-pipeline`, `software/ai/analysis/`
(`schema · segment · features_audio · features_vision · collapse · audit ·
run_pipeline`). Known issue: `segment.py` over-fires onsets on real ringing/buzzy
notes — tune via `expected_note_count` + `beat_times_ms` (see `docs/26`).

---

## 5. Experiment matrix (multiple labelings — run them all, let one win)

| id | hypothesis | method | labels used | metric | baseline |
|---|---|---|---|---|---|
| **E1** single-note 3-class | H1 | std→PCA→LDA | `intended_class` | LOPO d′ / confusion | chance 0.33 |
| **E2** string-ID from audio | — | LDA on audio feats | `string_num` | accuracy vs 1/6 | (have: clean 0.47, buzz 0.53, muted 0.43) |
| **E3** harmonic-residual buzz primitive | **H2** | HPSS / known-pitch harmonic subtraction → residual feats → LDA | mono clean/buzz | **transfer**: held-out chord clean-vs-buzz d′ | mono-only |
| **E4** per-chord μ_c off-detection | — | Mahalanobis distance to μ_c (+Σ_c) | `chord_name` | ROC clean-vs-off | — |
| **E5** muted-string detection | H3 | harmonic presence vs known chord (basic-pitch) | `string_classes` | per-string recall | — |
| **E6** per-string buzz attribution | H5 | per-pitch comb residual + vision + prior | `string_classes` | confusion (expect weak) | chord-level only |
| **E7** vision position (THE award) | **H4** | MediaPipe pose feats → RF / small MLP → `(string,fret)` | chord shape (+ audio-pitch truth) | **fret error vs raw MediaPipe**, LOPO + pose-out | raw MediaPipe |
| **E8** fusion | H5 | Bayesian position × quality × prior | all | per-string feedback acc | best single modality |
| **E9** clustering / retrieval | — | k-means / vector search on residual embeddings | — | recurring-mistake retrieval ("you keep muting the A") | — |

**Labeling schemes to compare** (the "many dimensions"): per-event class · per-string
class · residual-space class · chord-level off-detection. Report which labeling +
feature set gives the best held-out separation; that's the one we ship.

---

## 6. The 3D semantic viz (demo centerpiece)

- **std → PCA → LDA → 3D**, rotating scatter (plotly / three.js).
- color by **clean / buzz / muted**; **axes labeled by their named-feature loadings**
  (the "geospatial semantic meaning" — e.g. axis-1 = buzz-band-energy, axis-2 = HNR).
- **Money shots:**
  1. mono buzz cluster **and** poly chord-residual buzz cluster **overlapping** in
     the collapsed error space → *visual proof the primitive transfers* (H2).
  2. position error: **ours vs raw MediaPipe vs audio-truth** → *visual proof we beat
     the baseline* (H4).
- **Rigor (what makes it not a pretty blob):** leave-one-player-out, fit ALL
  preprocessing on train folds only, named eigenvector loadings, held-out d′,
  report at natural base rates. The viz shows the **validated** space.

---

## 7. Rigor rules (non-negotiable)

Split by player (LOPO; k-fold only when 1 player) · report by position · fit every
scaler/PCA/LDA on **train folds only** · natural base rates · the prompt is the
label + F0 / harmonic cross-check · **report only what clears held-out; degrade
gracefully** (per-string → chord-level when unsure).

---

## 8. Capture tooling (what the localhost does now)

One server: `python3 software/ai/capture/serve.py` → **localhost:8765** (auto-opens
Chrome). `/calibrate` = the digital twin (4-corner markerless homography, 6 poses).
Record-page blocks:

- **core-grid** — single-note clean/buzz/muted, 6 strings × frets 1–6 (clap +
  3·2·1 count-in, FRET 1→6 cue).
- **pose-variation · pluck-sweep · muted · choked · holdout** — supporting sets.
- **arpeggio / strum** — chords played clean+buzz, per-string ground truth.
- **chord-fault** — per-string fault (buzz/mute one known string) → `string_classes`.
- **chord-stream** — continuous ~100-chord batch in ONE recording, live fretboard
  diagram (dots + finger numbers), pose change every 10, logs `chord_sequence` +
  `cue_ms` per chord for offline alignment.

1080p video + 48k mono WAV. Per-run terminal confirmation with VIDEO/AUDIO
resolution checks. Resolution/audio pills on screen (green = MacBook spec).

---

## 9. Division of labor

- **Aritro + Aylin** — vision position (beat MediaPipe) + the 3D viz.
- **Aden** — segmentation (tune onsets) + the experiment matrix + clustering/retrieval.
- **William + others** — sound-to-haptic (uses the same recordings).

---

## 10. Open risks

1. `segment.py` over-fires onsets on real notes — tune (known; `docs/26`).
2. Per-string buzz attribution precision — validate (E6), degrade to chord-level.
3. H2 transfer assumption — validate (E3) before relying on it.
4. **1 player** so far — a 2nd player's hand is the biggest generalization unlock.
5. chord-stream batch file size (~150–250 MB / 100 chords) — hand off in chunks.

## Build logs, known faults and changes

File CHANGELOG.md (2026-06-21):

# Changelog — Tactus

> **Current state lives in [`truth.md`](truth.md), not here.** This log is the chronological record of the project, **including the abandoned pre-pivot era** (3-pillar Experience/Express; Raspberry Pi + ESP32 + MAX98357A; 16/14-channel). Older entries are kept as history — do not read them as the current build (as-built = laptop → 2× Vantec → 6× SK473/PAM8403 → 12× KHD drivers, LEARN + PLAY).

## 2026-06-20 — Framing pivot: whole-guitar capture (1080p) + offline ROI crop
- **Operator constraint on the demo machine:** the tight nut→fret-7 framing forced a camera angle so low the screen was unusable. **Resolved:** capture the **WHOLE guitar** (full-screen video — also what the live AR demo + train/serve match want) at **1080p**, and **crop to the fretboard ROI offline** before MediaPipe so wide framing keeps full `d` resolution. Seeing the whole neck *strengthens* markerless registration (more fret wires + inlays at 3/5/7/9/12 + both edges). Frets **1–6** stay the only rendered/coached scope (6 motors) — the camera just sees more.
- Tooling: `capture.html` + `calibrate.html` request **1080p** and the framing guide now says **whole-guitar**; `docs/25 §6d` (capture-wide-process-cropped) + `docs/26` build order add the **ROI-crop** step; `truth.md §3.8` updated.

## 2026-06-20 — docs/26 handoff + repo-wide markerless reconciliation
- **`docs/26-aiden-handoff.md`** — data handoff for the offline pipeline (Aiden): exact `data/raw` + `data/calib` layout, the **authoritative full manifest schema with a real example row** (the live tool writes more fields than `docs/24 §5`'s core table), the 6 processing gotchas (pointing to `docs/25`), the build order, and the iron rules. Cross-linked from `docs/25`.
- **Repo-wide registration reconciliation → MARKERLESS is primary, ArUco is OPTIONAL.** Aligned the canonical + active-path docs to the pivot (the guitar's 12-TET fret-law is its own ruler; `software/ai/vision/fretboard.py`): `truth.md` (§2 diagram, §3.8, §6 Stage 1, §9 doc map), `docs/24` (§1 rig, align-mode, §5 schema pointer, §7/§8), `docs/23` (§3 rig), `docs/17` (§1b), `docs/20` (D3 + capture rig), `docs/22` (live-AR registration → markerless-primary, ArUco/virtual-neck fallback), `cad/README` (marker = optional validator, nut/neck not headstock), `software/ai/capture/README`. `truth.md` remains the canonical tie-breaker for any background doc still describing "MediaPipe + ArUco" as a capability.

## 2026-06-20 — Markerless fretboard registration + guitar digital twin (no taped marker)
- **`software/ai/vision/fretboard.py`** — markerless registration from the 12-TET fret-spacing law (`x_n = 1−2^(−n/12)`): the guitar is its own ruler, so no fiducial is needed. Fits the fretboard homography from the guitar's own geometry and validates by reprojecting the fret grid onto the real wires. Synthetic front-cam self-test passes (~1.3px median reproj, recovers signed `d`). This becomes the PRIMARY registration path; the ArUco marker is demoted to an OPTIONAL ground-truth validator (`cad/aruco/`).
- **`software/ai/vision/calib_serve.py` + `calibrate.html`** — localhost guitar digital-twin capture. Hold the neck at ~6 angles, click the 4 neck corners on each frozen frame; the fret grid overlays live (in-browser 4-pt homography) so you SEE it snap onto your real frets — paperless proof. Saves keyframes to `data/calib/<guitar>/`.
- **`software/ai/vision/twin.py`** — builds `twin.json` from the keyframes: fret-law intrinsics (pose-invariant) + a validated homography per captured angle + corner-reproj residual + board color. The "memorize the guitar once, solve the pose per frame" split.
- **`capture.html`** — on-screen **Framing guide** (nut→fret 7, whole fretting hand, lock camera + mic, training=demo) so the operator doesn't memorize the protocol; the **Pose-variation block** now prompts the finger/wrist/neck-angle change each pass (logged as `pose_variant`).
- **`cad/aruco/`** — `generate_marker.py` + print sheet (4×4_50 id 0), kept ONLY as the optional offline validation rig.

## 2026-06-20 — Localhost capture app (synced A/V + maximal metadata + live QC)
- **`software/ai/capture/serve.py` + `capture.html`** — stdlib localhost server + one Chrome page. Records **synced webcam+mic per run** (lossless WAV + webm, same `getUserMedia` stream) and writes straight to `data/raw/<session>/<player>/` with a maximal-metadata `manifest.jsonl`. Run: `python3 software/ai/capture/serve.py` → open the printed `http://localhost:8765`. End-to-end save round-trip tested.
- **Quality guards:** disables browser DSP (echo/noise/AGC off) so the buzz band survives; live input-level meter + **red CLIP alarm**; per-run silent/too-short checks; coverage grid + clip/silent/fail counts; per-run **download fallback** if the server is down (no take lost).
- **Maximal metadata** per run (for the harness loop): string/fret/finger/class/placement/pluck(+variant)/chord/pass/room, beat-grid times, duration, peak dBFS + clip/silent flags, sample-rate, video res/fps, mic+cam device labels, file paths/bytes, marker-present, sync note, app version.
- **Blocks:** core grid · pose-variation · pluck-sweep · muted · choked · arpeggiated chords · strummed · natural holdout. Prompt = the label; interleaved order kills session drift.
- `docs/24 §10` rewritten localhost-first (`record_conductor.py` + QuickTime kept as the zero-dep fallback); `software/ai/capture/README.md` added; `.gitignore` now also drops `*.webm`.

## 2026-06-20 — Data-collection: frets 1–6 scope lock, last-mile↔data framing, Day-1 recorder
- **SCOPE LOCK (D6): frets 1–6 only, 1:1 fret→zone** (6 fret-zone motors — we record/coach only what we can render). Resolves the "fret span beyond 6" open thread and supersedes the eng-review V5 neck-spanning ask. Reconciled across `truth.md §3.2`, `docs/24` (§0b/§3 + decisions), and `docs/23` (breadth pass).
- **`docs/24 §0b` — "what the data actually trains: the two last miles."** Vision (MediaPipe + ArUco/homography) does the bulk for free; capture only pins two residuals — Stage 1 (occluded pose → string,fret,finger) and Stage 2 (buzz B + d → pressure/cause). One recording trains both; the prompt is the label. This is *why* ~1,000 takes suffice vs ~100× for a raw-pixel model.
- **`docs/24 §10` + `software/ai/capture/record_conductor.py` — Day-1, zero-build recording.** Terminal conductor (stdlib only) prompts each interleaved run and writes the manifest (prompt = label); QuickTime captures synced A/V in one file. Run: `python3 software/ai/capture/record_conductor.py --player <name> --passes 3`. The localhost/align-mode harness is the next build.
- **`.gitignore`** — ignore raw capture media (`data/raw/**/*.wav|mp4|mov`), keep `manifest.jsonl` tracked.

## 2026-06-19 — Refinement pass on the as-built rig (enclosure CAD + build kinks + LEARN UI)
Aligned to Aritro's as-purchased docs (`docs/00`–`13`, laptop → 3× Vantec → 7× SK473/PAM8403 → 14× 40 mm). Added, on branch `refine/enclosure-build-interface`:
- **`cad/` — printable enclosure** for everything-but-vest-and-subwoofers, sized to the **FlashForge Adventurer 5M (220³, PETG)**. Parametric OpenSCAD + **pre-rendered STLs** (all verified ≤ 220 mm): `tactus_box` (base+lid: 3 Vantec + 7 amp bricks + Pi 5, vented, **strain-relief comb** + zip-tie floor), `tactus_power_cradle` (Anker 737 / 10-port hub, removable + vented), `actuator_puck` (turns a 40 mm cone speaker into a body tactor — the coupling fix).
- **`docs/15-build-refinements.md`** — the kinks that bite: **PAM8403 is BTL → never common the "−" outputs**; the **3-Vantec/ALSA enumeration trap** (bind by USB path, verify CM6206 channel order); wire-gauge split (heavy 18 AWG on the power bus, light stranded on the body); cone-speaker **coupling**; corrected the Mode-A "50 W rail" claim (it's a 12 V hub w/ per-port limits → run at felt level); the exhaustive **what-connects-to-what** table; single-channel-first solder order.
- **`docs/16-learn-interface.md` + `web/index.html`** — LEARN UI refined to the **real 14-channel string/fret body map** (6 chest + 6 forearm + 2 back), the 3-fix correction panel, note highway, and a **runnable mock** (no backend) that demonstrates the WebSocket `frame`/`note`/`error`/`reference` contract.
- Component dims researched (Anker 737 155.7×54.6×49.5/630 g; Vantec 100×58×26; SK473 brick ~55×35×25; Pi 5 ~26 mm clearance) to size the box. Resolved the enclosure open-question in `docs/13`.
- **Scope per Aditya: LEARN + PLAY are the product now; EXPERIENCE/Express/Body-Synth dropped** — already consistent with the as-built guitar-coaching direction.
- **Pi cut from scope (laptop-only).** Drops the QNX dependency; CAD standoffs removed (`include_pi=false`), base STL re-rendered. **`docs/17-ai-rigor.md`** added — the deep audio+vision **fusion → high-granularity (string,fret,finger,quality)** argument, the 3-axis targeted feedback, the eval/ablation rigor moves, and how the **interface showcases the AI**; awards reoriented to **Most-Technical / Best-UI-UX / Anthropic / Accessibility / CV / Redis**.
- **`docs/15 §10`** — laptop connection + power topology: the **one-powered-hub-does-both** path (one wall plug + one USB cable to the laptop + laptop on its own power) and the Anker cordless variant. Wire reality corrected to **18 AWG only** (BOM's 22 AWG line is stale); `actuator_puck` notch widened to fit it and re-rendered.

## 2026-06-19 — Hardware corrected after live inventory cross-check (physics)
- **Dropped the heavy bass shakers from the wearable.** Live check: Micro Center's in-store shakers are **BST-2 ≈ 1180 g** and **AuraSound ≈ 1700 g** — built for couches/floors, **not wearable** (would sag/tear the vest, hurt). Directly answers Aditya's weight/physics question.
- **Wearable actuators = 8× light exciters** (Dayton **DAEX25 ≈ 111 g**, or TT25-8 Puck ≈ 170 g). **Micro Center does NOT carry exciters → order DAEX25 on Amazon (Sat delivery);** if MC has TT25 Pucks on the shelf, buy 8 there instead.
- **Final channel architecture (all in-stock, all 5 V):** **Pi 5 → 2× ESP32 (2 I2S buses each) → 8× MAX98357A → 8 exciters.** 2 amps per I2S bus (L/R strap) → 4 ch/ESP32 → 8 total. **No Teensy** (ships 5–7 days, not needed), **no 24 V brick / TPA3116** (~1.8 W/exciter against skin is plenty). Simpler, lighter, touch-safe.
- **`03` rewritten with the corrected FINAL BUY LIST** + phone-confirm steps (MC 403s web stock; the 833 number is unverified — use the Google Maps listing). `02` finished-product + channel sections corrected. ~$350 MC + $104 Amazon + $30 Target; guitar from Aditya's friend.

## 2026-06-19 — LEARN re-architected: vision + haptic closed-loop guitar coaching (per Aditya)
- **Dropped the 3 practice modes** (Recognize/Anticipate cut). LEARN is now **one coherent loop** = *"Rocksmith for Deaf players."*
- **Core idea:** a hearing player closes the learning loop by ear (play → hear the gap → fix); a Deaf player can't. We close it with **(a) haptic ground-truth** — feel the correct version on the vest, and feel *your version vs correct back-to-back* so the error is tangible — **and (b) vision** — a camera + **VLM (Claude vision)** watches the fretting hand and gives the **exact physical change**, highlighting the wrong finger.
- **The loop:** feel the target → play the real guitar (mic + camera) → on a wrong segment, **rewind → replay correct haptics (+ feel-the-difference) → VLM shows the physical fix → one instruction → re-loop.**
- **The physical-correction engine (novel core):** fuses mic (F0 / onset-offset / harmonic-to-noise+decay) + vision (MediaPipe Hands + fretboard + Claude vision) + the reference (tab/MIDI fingering) → **exactly 3 advice categories: wrong note · incorrect duration · wrong pressure.**
- **GUITAR ONLY** for the hackathon (easiest to analyze visually). Generalizes later.
- **Redis promoted to a headline sponsor:** on-device **local memory → offline practice anywhere** (songs + fingering + calibration + progress). Baked into the core loop, not a cache.
- **Anthropic flagship deepened:** **Claude's vision is the coaching brain** (frame + target + error → physical fix + finger highlight) — a real multimodal integration. Deepgram = hands-free ("rewind"/"slower"). 
- **Rewrote `13`**; updated `00` (LEARN pillar), `05` (now the real-time PLAY engine that LEARN builds on; guitar lead), `06` (Anthropic vision + Redis offline), `07` (the correction demo beat), `08` (workstream D = the vision loop), README.

## 2026-06-19 — Vest-primary form factor + LEARN web app added to scope (per Aditya)
- **Form factor flipped to VEST-PRIMARY** (`00`/`02`/`11`). The chest+back vest is now the **hero** (build first) — central torso = strongest *emotional* feeling (bass in the chest), full tonotopic canvas, carries a whole song alone. Optional **Piece 2 = a glove/hands** (fingertip tactors for the Play tuner + IMU/EMG for Express gesture). Clean split: **vest = feel/learn, glove = play/express.** (Reversed the earlier sleeve-first call.)
- **Three use cases locked as EXPERIENCE · LEARN · PLAY** (`00`). "Express" (create music) now lives inside **Experience** as its flagship active mode. *(Flagged for confirmation — if the team wants Express as its own top-level pillar, easy to split back out.)*
- **NEW `13_LEARN_WEB_AND_VISUALIZATION.md`** — a website tuned to the haptics that **teaches a Deaf person a song** via synced **visual reinforcement + haptic feedback**. Real (non-decorative) value: (A) Guitar-Hero "Haptic Roll" that teaches the body-mapping + anticipation, (B) live body-map, (C) structure-timeline + lyrics, (D) the **note→deconstruction→haptics pipeline visualization** (the explainability showpiece). Practice modes (Follow/Recognize/Anticipate) with real scoring. Grounded in Deaf-music-learning evidence (Tranchant/Hopkins/González-Garrido). **Parallelizable:** built against a fixed WebSocket JSON contract so one person owns the web front-end independently of hardware. Drives Best UI/UX + Most-Technical + Anthropic(tutor)/Arize.
- **Build plan:** workstream **D** is now the LEARN web app; **lock the WebSocket schema Saturday AM** (the seam for parallel work).

## 2026-06-19 — Direction changes (per Aditya): reframe + remove the score
- **⛔ Removed the score-based architecture.** Dropped the symbolic "JSON haptic-score that Claude composes." A generated score is an abstraction that *weakens* rigor (invites "is the AI just making it up?"). Replaced with a **direct, continuous signal→skin transcription** — measurable frame-by-frame fidelity to the source, the same *class* as a **cochlear-implant processor / vocoder**. genAI stays where it's defensible: the **learned audio→haptic model**, the **gesture→sound mapping** (Express), and **Claude as an accessible music tutor** (Learn). Saving/sharing = the **actual rendered haptic signal** (HJIF signal mode), not an AI score. Updated `00, 04, 06, 07, 08, 09, 12`, README.
- **Reframed the whole product as EXPRESS · PLAY · LEARN** (one engine, three pillars). *Express* = gesture→sound→felt-back (creative loop). *Play* = real instrument → real-time tuner/rhythm haptics on the wrists. *Learn* = feel the **real songs everyone listens to** → community/belonging (the emotional core). The shared engine = wideband hardware + the direct transcription + the learned model. Updated North Star + README + sponsors.
- **Answered: body placement** (`11`/`00`) — wearable "tactile cochlea": back 2×4 tonotopic ladder (low→lower back, high→shoulders), lumbar/abdomen bass shakers, sternum vocals, **wrists for the PLAY tuner feedback** (hands busy), ankles for kick, fingertip for fine pitch; **not the face**.
- **Answered: PLAY latency** (`05`/`00`) — real-time, **~20–50 ms** on the live paths (which use lightweight causal F0 + voice-coil actuators, **not** the heavy model). Imperceptible for tuning; vibration lags audio; minimized via voice-coil (not ERM), small buffers, wired-not-Bluetooth, beat prediction. Heavy model/separation only runs offline on known songs.
- **Ponytail:** user installs it as a per-user Claude Code plugin (their choice); nothing committed to the repo.

## 2026-06-19 — Full pivot: Hearth → Tactus
- **Pivoted** from *Hearth* (contactless sleep/seizure guardian) to **Tactus**: a wideband, multi-node haptic wearable that lets Deaf people feel music (rhythm, pitch contour, timbre, spatially) and learn instruments by touch.
- **Why:** the team wanted a build where the *rigor and complexity of the haptics themselves* are the wow — a research-grade audio→haptic system, plus a genAI "favorite song → haptic" experience and a live, emotional demo.
- **Locked:** the North Star, the honest claim discipline (a *new sensory language*, not "hearing"; Deaf-culture-respectful, not a "cure"), and the working name *Tactus*.
- **Launched** a 5-front deep-research pass to ground the build: (1) tactile psychophysics & illusions, (2) actuator/driver hardware engineering, (3) Microcenter Santa Clara / Target same-day sourcing, (4) research-grade audio→haptic ML/DSP, (5) instrument-learning + sponsor strategy.
- **Carry-over from Hearth:** sponsor landscape (QNX, Deepgram, Anthropic, Sentry, Arize, Fetch, Redis), the quality bar (honest-but-stunning claims + live emotional demo), and likely on-hand hardware (Raspberry Pi, USB mic/speaker, ESP32s from the booth).
- **Open item:** Aditya's salvage-parts list not yet received — plan is salvage-agnostic with a slot to fold them in.

### Research pass landed — full doc set written (later 2026-06-19)
- All 5 research agents returned; synthesized into the cited doc set (`00`–`08` + raw `REF_` briefs).
- **Key unlocks:** (1) **Microcenter Santa Clara stocks voice-coil bass shakers in-store** (Dayton BST-2, AuraSound) — wideband actuators buyable today, not just buzzers. (2) Wideband requires **voice-coil exciters + bass shakers driven by class-D audio amps** (NOT ERM/LRA/PWM) — the literal "not a buzzer" differentiator. (3) Skin = ~5 octaves, ~15–20 distinguishable frequencies, ~3–5 cm torso acuity ⟹ **place-code pitch + exploit phantom/funneling illusions + lean on rhythm**. (4) ML core = **distill the DSP psychohaptic mapping into a multi-channel neural net** (MERT→TCN/GRU) with a perceptual+discriminability loss; multi-channel spatial generation is the novel paper-grade contribution (HapticGen etc. are single-channel). (5) **Claude = haptic choreographer** emitting a JSON score → MPEG-I HJIF. (6) Sponsors form one coherent system: **Claude composes (Anthropic) → uAgents orchestrate (Fetch) → QNX real-time on Pi → Deepgram voice → Arize eval**; main track **Ddoski's World** (social impact) + **Ddoski's Lab** depth.
- **Locked scope:** FeelStream (hero sensation), the learned audio→haptic model, PlayByTouch (instrument-by-touch), Claude the Haptic Composer.
- **Honest framing locked:** a *new sensory/artistic language*, designed **with** the Deaf community — never "making Deaf people hear." Recruit a Deaf advisor (prize multiplier + the right thing).
- **Top build risk flagged:** actuator coupling/backing (surface-dependent exciter response) — prototype first thing Saturday.

### Added creative-expression direction (2026-06-19, per Aditya)
- New doc `09_CREATIVE_EXPRESSION.md`: the **grand-prize inversion** — Deaf people don't just *feel* music, they **create** it natively in touch and feel their own creation in real time (the **Body Synth** closed loop). Forward audio→haptic model run *backward* (gesture→sound+felt-back-haptics), emotion as the cross-modal invariant. Three modes (Body Synth / Tactile Composer / Cross-Modal Art Object). Grounded in Deaf art culture (Christine Sun Kim, De'VIA, Visual Vernacular, Deaf Gain). Staged as the visionary peak *after* consumption proves it works; **first on the cut list so it never risks the core.**
- Added Build #5 to North Star scope; threaded into build plan (Sunday stretch) + demo (the mic-drop performance beat).
- **Sourcing updated:** borrow the guitar / rent the violin (Music & Arts ~$20–30/mo) instead of buying — instrument cost ~$0–30 vs ~$80–140.

### Second research pass — sourcing consolidation + 4 new docs (2026-06-19, per Aditya)
- **Sourcing consolidated to a clean 2-STOP run** (`03` rewritten). Micro Center + Guitar Center are both on Stevens Creek Blvd in Santa Clara, 1.7 mi apart, both open till 9pm → one southbound trip. Violin from **Allegro Music, Fremont** (⚠️ **Music & Arts has NO local store — earlier note was wrong**). Optional TENS unit at Target Fremont. **Best in-store amp = Adafruit MAX98357A (I2S, no DAC); don't drive for amps; Amazon same-day unreliable Fri evening.** Phone-ahead checklist + "don't drive to" list (Fry's/HSC/Excess all closed/non-local).
- **`10_GESTURE_PIPELINE.md`** — feel music through body expression: **ESP32 + BNO055 (orientation) + MyoWare (effort) → OSC → Wekinator regression → granular synth → audio + haptic felt-back**, closed loop <~10 ms (jitter worse than fixed delay). Mi.Mu/Wekinator/Hunt-Wanderley mapping; pitch→location not felt-freq; LLM as offline structure-oracle; RAVE/DDSP as real-time neural-timbre bet. MediaPipe-hands laptop = $0 fallback.
- **`11_STIMULATION_MODALITIES.md`** — body-placement map (wearable Model Human Cochlea: back 2×4 + sternum + lumbar bass + wrist/ankle); **pneumatic squeeze = best-evidenced non-vibration add** (dynamics); **EMS "guide-the-hand" PlayByTouch** (PossessedHand/Lopes precedent) via FDA TENS + openEMSstim attenuate-only, **limb-only, consented, kill switch**; bone-conduction/thermal/GVS/tongue mostly out. Hard **safety red lines** (never chest/neck/head, pacemaker/pregnancy/epilepsy; never DIY stimulator).
- **`12_PLATFORM_AND_GENAI.md`** — save/AI-author/share haptic tracks. **White space confirmed:** MPEG-I Part 31 + RFC 9695 "MP3 of touch" finalized 2025 but **zero consumer adoption**; web haptics nearly nonexistent (iOS Safari = nothing); **no Spotify-for-haptics**. Reliable AI = **LLM→JSON score** (ChatHAP CHI 2025: Claude emits schema-valid haptic JSON). `tactus.score.json` (+ semver/parent_id) + tiered web player (vest→iPhone AHAP→Android→cymatic fallback) + 60-sec calibration + `.hjif` export.
- **Scope now 6 builds** (+ FeelStream, learned model, PlayByTouch, Claude composer, Body Synth, digital layer) + 2 stretch dimensions (multi-modal stimulation). Creative + digital deepen Anthropic/QNX/Fetch/SkyDeck — no new sponsors. New demo beats: the Body-Synth mic-drop + share-a-track. All stretches are **first on the cut list** so they never risk the core.

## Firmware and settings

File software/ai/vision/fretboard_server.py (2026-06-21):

#!/usr/bin/env python3
"""
Open-vocabulary fretboard / guitar-neck detector served over WebSocket.

WHY this design:
  Prior auto-detectors in this repo failed on a busy hackathon background:
    * OpenCV Hough (fretboard_detect.py) — edges/lines drown in clutter.
    * MediaPipe hands — needs the hand on the neck and a clean scene.
  Ultralytics YOLO-World is open-vocabulary: we give it the TEXT prompt
  "guitar neck"/"acoustic guitar" and it localizes the instrument with no
  training and no markers, robust to background clutter. We then refine the
  YOLO box into a 4-corner quad of the *neck* using a foreground mask that
  rejects skin (the fretting hand), so the wooden neck + strings dominate.

Pipeline per frame:
  YOLO-World box (most confident, whole guitar) -> SAM2 instance mask prompted
  by that box -> isolate the NECK from the whole-guitar mask (distance-transform
  body/neck split + march perpendicular widths along the body->headstock axis)
  -> minAreaRect on the neck pixels -> 4 corners (full-frame px) -> canonical
  ordering along the neck's long axis -> normalized [0..1] quad + YOLO confidence.

WHY a mask (not just the box): YOLO-World returns ONE box around the WHOLE
guitar (body + neck), so the box-derived quad covers the whole instrument. The
consumer maps a 6-string x 7-fret grid that must sit on the NECK only, so we
segment the guitar (SAM2) and extract just the thin fretboard from the mask.

Both models load ONCE at startup (never per frame): YOLO-World + CLIP text
classes, and SAM2-tiny. If SAM2 or neck extraction fails on a frame we fall
back to the previous whole-box quad (never crash, never return garbage).

Run as a server:
    .venv-yolo/bin/python fretboard_server.py            # ws://127.0.0.1:8772

Self-test on an image (headless, no camera):
    .venv-yolo/bin/python fretboard_server.py --selftest path/to/guitar.jpg
"""
from __future__ import annotations

import argparse
import asyncio
import json
import os
import sys
import time

# MPS (Apple Silicon) can hit unimplemented ops; fall back to CPU for those
# instead of crashing. Must be set before torch / ultralytics import.
os.environ.setdefault("PYTORCH_ENABLE_MPS_FALLBACK", "1")

import numpy as np

import cv2

# The 12-TET fret law (fret_fraction(n) = 1 - 2^(-n/12)). Shared with fretboard.py /
# fretboard_detect.py so the silver-fret-wire grid uses the SAME physical law the
# consumer's nut->fret7 grid does. Import is cheap (pure numpy) and never per-frame.
try:
    from fretboard import fret_fraction
except Exception:  # keep the detector runnable even if the sibling import fails
    def fret_fraction(n: int) -> float:
        return 1.0 - 2.0 ** (-n / 12.0)

# ---------------------------------------------------------------------------
# Configuration
# ---------------------------------------------------------------------------
WS_HOST = "127.0.0.1"   # explicit IPv4 loopback
WS_PORT = 8772          # moved off 8770: macOS sharingd holds a dual-stack *:8770 listener (v4+v6)
# yolov8m-worldv2 (~55 MB) replaces yolov8x (~146 MB): on the two test images it
# returns near-identical guitar boxes (the box is all SAM2 needs) at ~26ms vs
# ~73ms/frame. SAM2 keys on the box, not the logits, so the smaller detector
# costs us nothing downstream while roughly halving the YOLO cost.
MODEL_NAME = "yolov8m-worldv2.pt"          # auto-downloads (~55 MB) on first load
SAM_NAME = "sam2_t.pt"                      # auto-downloads (~74 MB) on first load
CLASSES = ["guitar neck", "guitar fretboard", "acoustic guitar", "guitar"]
CONF_THRESH = 0.20

# --- Speed: SAM2 cadence (see detect_quad) ---
# SAM2 is ~216ms/frame and dominates latency; YOLO (~26ms) + neck-derive (<1ms)
# are cheap. So run SAM2 only every SAM_EVERY-th frame (or when the YOLO box
# jumps); between those, reproject the cached neck quad (stored RELATIVE to the
# YOLO box) onto the current frame's box. The box tracks motion per frame; the
# neck's pose within the box is stable, so this stays accurate between SAM2 runs.
SAM_EVERY = 4
# Re-run SAM2 early (ignore the cadence) when the YOLO box center moves more than
# this fraction of the box diagonal, or its size changes by more than SAM_BOX_*:
# a big box jump means a re-acquire / large motion where the cached relative
# neck geometry may no longer hold.
SAM_BOX_MOVE_FRAC = 0.20
SAM_BOX_SCALE_LO = 0.75
SAM_BOX_SCALE_HI = 1.33

# --- Temporal stability: EMA smoothing of the emitted quad (see _smooth_quad) ---
# A new quad "close" to the last one is jitter -> blend heavily toward the last
# (NEAR_BLEND weight on the NEW quad). A "far" quad is a real move/re-acquire ->
# snap (FAR_BLEND weight on the new quad) so we stay responsive.
SMOOTH_NEAR_BLEND = 0.4     # smoothed = 0.6*last + 0.4*new  (jitter rejection)
SMOOTH_FAR_BLEND = 0.8      # smoothed = 0.2*last + 0.8*new  (snap on big move)
# "close" test: centroid move < this fraction of the frame diagonal AND area
# ratio within [AREA_LO, AREA_HI]. Outside either -> treat as a real move.
SMOOTH_MOVE_FRAC = 0.08
SMOOTH_AREA_LO = 0.7
SMOOTH_AREA_HI = 1.4
# On a frame with NO detection, re-emit the last smoothed quad (confidence decayed
# by MISS_CONF_DECAY each miss) for up to MISS_HOLD frames before emitting null.
# Avoids the overlay vanishing on a single dropped detection.
MISS_HOLD = 5
MISS_CONF_DECAY = 0.8

# --- Neck-extraction tuning (see _neck_quad_from_mask) ---
# Distance-transform fraction: pixels with dist-to-edge > DT_FRAC * max are the
# thick "body core"; the rest (thin) is neck/headstock. The body is wide/round
# so it survives; the neck is thin so it doesn't.
DT_FRAC = 0.32
# Number of bins marched along the body->headstock axis.
NECK_BINS = 40
# A bin counts as "neck" if its perpendicular width < NECK_WIDTH_FRAC * max width.
NECK_WIDTH_FRAC = 0.30
# Bridge up to this many missing/occluded bins (the fretting hand) within the
# fretboard run...
NECK_MAX_GAP = 3
# ...but only resume across a gap if the width stays within this band of the
# running fretboard median (rejects the headstock: tuner pegs flare wider, the
# foreshortened head collapses narrower).
NECK_BAND_LO = 0.5
NECK_BAND_HI = 2.0

# --- Top-edge rectangle fit (see _rect_quad_from_band) ---
# The neck quad's ROTATION comes from a LINE fit to the fretboard's top long edge
# (the straight binding above the low-E), not from minAreaRect of the whole band:
# minAreaRect's angle wobbles on busy/occluded frames, but the top binding line is
# the strongest, most reliable anchor and gives a true rotated rectangle (parallel
# long edges, no shear / perspective). Robust line fit (cv2.fitLine, DIST_HUBER)
# resists the fretting-hand / clutter outliers on the band boundary.
# DIST type for the robust line fit of each long edge.
EDGE_FIT_DIST = cv2.DIST_HUBER
# Boundary points within this fraction of the half-thickness of the long axis are
# treated as "near the centre" and dropped from the side split, so the nut/end
# caps (which curve across both sides) don't pollute either long-edge fit.
EDGE_SIDE_DEADBAND = 0.15
# The rectangle's top boundary + WIDTH come from the band's perpendicular extent
# (distance along the perpendicular to the fitted top edge). Use a robust HIGH
# percentile for the bottom and (100 - this) for the top, so a few stray pixels
# above the binding or below the low strings don't blow the width up/down; the
# fretboard is near-constant width.
NECK_WIDTH_PCTL_HI = 98.0
# Along-neck ends: trim to this/(100-this) percentile of the along-axis projection
# so a few along-axis straggler pixels don't over-extend the rectangle past the
# visible fretboard, while keeping essentially the full nut..far-fret run.
ALONG_END_PCTL = 1.0
# Need at least this many boundary points on EACH long side for a trustworthy fit;
# below it we fall back to minAreaRect so we never emit a garbage rectangle.
EDGE_MIN_SIDE_PTS = 8
# Rotation guard (safety net, deliberately LOOSE): on the test images the robust
# top-edge fit matches the true neck tilt (from full neck+headstock PCA) to ~1-2
# deg and beats the march axis, so we trust the fit. We only fall back to the march
# along-axis if the fit is GROSSLY off (a degenerate / nearly-square band where the
# side-split collapses), which would otherwise emit a wildly mis-rotated rect.
EDGE_ANGLE_GUARD_DEG = 35.0

# --- Silver fret-wire detection -> 12-TET law -> real nut..fret7 (see
#     _detect_fret_wires / _fit_fret_law_1d) ---
# The top-edge rect's ALONG extent is the SAM2 band (mid-neck, truncated by the
# fretting hand), NOT the real nut. The silver fret WIRES are a strong high-contrast
# cue: we rectify the band so frets become vertical, pop the bright thin vertical
# wires, peak-find their along-neck positions, fit the 12-TET law, and EXTRAPOLATE
# the (occluded) nut + fret 7 to re-anchor the quad. Tuned on the realtest frames.
FRET_DETECT = True              # master switch; False -> behave exactly as before
# Rectified-ROI sampling: extend the band this fraction of its own along-length past
# EACH end so an extrapolated nut/fret-7 that falls just outside the band is drawable.
FRET_RECT_PAD_ALONG = 0.6
FRET_RECT_PAD_PERP = 0.08
# Profile only the top+bottom fractions of the neck height: fret WIRES span the full
# height; inlay DOTS sit in the centre, so skipping the centre rejects the dots.
FRET_EDGE_BAND = 0.32           # use rows in [0,0.32) and (0.68,1] of the rect height
# A rectified column must have at least this fraction of its edge-rows inside the
# fretboard band to contribute a profile value (drops the occluded / off-board cols).
FRET_MIN_COL_COV = 0.18
# Peak finder on the smoothed along-neck bright-line profile.
FRET_PEAK_PROMINENCE = 0.30     # x the profile's nonzero std
FRET_PEAK_MIN_DIST_FRAC = 1.0 / 80.0   # x rectified width
FRET_PROFILE_SMOOTH = 7         # 1-D Gaussian width (odd) on the column profile
# 12-TET law fit acceptance: need >= this many UNIQUE consecutive fret inliers and a
# spacing residual (normalized by scale) below the threshold, else fall back to the
# band-extent quad (never worse than before).
FRET_MIN_INLIERS = 5
FRET_MAX_FRET = 14              # search frets 0..this in the law fit
FRET_FIT_TOL_FRAC = 0.05        # inlier tolerance as a fraction of the peak span
FRET_MAX_RESID_FRAC = 0.020     # max mean residual / scale to TRUST the law fit
# Confidence blend: final conf = YOLO_conf * (FRET_CONF_BASE + (1-base)*fit_quality),
# where fit_quality in [0,1] grows with inliers and shrinks with residual. So a clean
# fret fit nudges confidence up; a weak one barely changes the YOLO confidence.
FRET_CONF_BASE = 0.85

# Skin HSV range (the fretting hand) — used only by the legacy box-refine
# fallback when SAM2 / neck extraction is unavailable.
SKIN_LO = np.array([0, 30, 60], dtype=np.uint8)
SKIN_HI = np.array([25, 180, 255], dtype=np.uint8)

# Lazily-initialized singletons (loaded once).
_MODEL = None
_SAM = None
_DEVICE = "mps"

# --- Per-stream mutable state (module-level; reset via reset_state()) ---
# SAM2 cadence cache: the YOLO box SAM2 last ran on, the neck quad it produced
# expressed in that box's local frame (so we can reproject it onto a new box),
# and how many frames since SAM2 last ran.
_LAST_SAM_BOX = None        # (x1, y1, x2, y2) the cached neck quad is relative to
_CACHED_NECK_REL = None     # (4,2) neck corners in normalized box-local coords
_FRAMES_SINCE_SAM = 0
# The silver-fret `frets` payload from the last SAM2 frame, cached so the cheap
# cache path (between SAM2 runs) can re-emit it: the u values are relative to the
# quad's nut->fret7 axis, which the cached quad preserves as it reprojects. None
# when the last SAM2 frame had no trustworthy fret fit.
_CACHED_FRETS = None        # list[{"n": int, "u": float}] or None
# Temporal smoothing state: the last quad we EMITTED (normalized px, full frame),
# its confidence, and the count of consecutive no-detection frames.
_LAST_EMIT_QUAD = None      # (4,2) float, normalized [0..1], canonical order
_LAST_EMIT_CONF = 0.0
_MISS_COUNT = 0


def reset_state():
    """Clear all per-stream state (SAM2 cache + smoothing history).

    Called when a WS client connects so a new session starts clean, and exposed
    for the self-test / unit tests so each starts from a known state.
    """
    global _LAST_SAM_BOX, _CACHED_NECK_REL, _FRAMES_SINCE_SAM, _CACHED_FRETS
    global _LAST_EMIT_QUAD, _LAST_EMIT_CONF, _MISS_COUNT
    _LAST_SAM_BOX = None
    _CACHED_NECK_REL = None
    _FRAMES_SINCE_SAM = 0
    _CACHED_FRETS = None
    _LAST_EMIT_QUAD = None
    _LAST_EMIT_CONF = 0.0
    _MISS_COUNT = 0


# ---------------------------------------------------------------------------
# Model loading (ONCE)
# ---------------------------------------------------------------------------
def load_model():
    """Load YOLO-World once and set the open-vocabulary classes once.

    set_classes() builds CLIP text embeddings and is slow — it MUST NOT run
    per frame. We pick the inference device here too, with a CPU fallback if
    MPS isn't usable.
    """
    global _MODEL, _DEVICE
    if _MODEL is not None:
        return _MODEL

    from ultralytics import YOLOWorld
    import torch

    if torch.backends.mps.is_available():
        _DEVICE = "mps"
    elif torch.cuda.is_available():
        _DEVICE = "cuda"
    else:
        _DEVICE = "cpu"

    print(f"[init] loading {MODEL_NAME} (auto-downloads ~146MB on first run)...",
          flush=True)
    t0 = time.time()
    model = YOLOWorld(MODEL_NAME)
    print(f"[init] setting open-vocab classes {CLASSES} (loads CLIP, slow)...",
          flush=True)
    model.set_classes(CLASSES)
    _MODEL = model
    print(f"[init] ready on device={_DEVICE} in {time.time() - t0:.1f}s",
          flush=True)

    # Load SAM2-tiny once too (segments the guitar so we can isolate the neck).
    # If it fails, we keep running and fall back to the box-derived quad.
    global _SAM
    try:
        from ultralytics import SAM
        print(f"[init] loading {SAM_NAME} (auto-downloads ~74MB on first run)...",
              flush=True)
        ts = time.time()
        _SAM = SAM(SAM_NAME)
        print(f"[init] SAM2 ready in {time.time() - ts:.1f}s", flush=True)
    except Exception as exc:
        _SAM = None
        print(f"[init] SAM2 unavailable ({exc!r}); will use box-only fallback",
              flush=True)
    return _MODEL


# ---------------------------------------------------------------------------
# Quad geometry
# ---------------------------------------------------------------------------
def _order_quad_along_long_axis(box_pts: np.ndarray) -> np.ndarray:
    """Order 4 rotated-rect corners canonically along the neck's LONG axis.

    The longer side of the rect is the neck "along" axis (u). We return:
      [along-start . sideA, along-end . sideA, along-end . sideB, along-start . sideB]
    i.e. walk the two long edges so the quad traces a consistent ring.

    box_pts: (4,2) float, the cv2.boxPoints output (ordered around the rect).
    """
    p = box_pts.astype(np.float64)
    # Edge lengths between consecutive corners (boxPoints is ordered around rect).
    e = [np.linalg.norm(p[(i + 1) % 4] - p[i]) for i in range(4)]
    # Edges 0 and 2 are one pair of opposite sides; 1 and 3 the other pair.
    pair01_len = e[0] + e[2]
    pair12_len = e[1] + e[3]

    if pair01_len >= pair12_len:
        # Long edges are p0->p1 and p2->p3 (sides A and B run along these).
        # sideA long edge: p0 (start) -> p1 (end)
        # sideB long edge: p3 (start) -> p2 (end)
        along_start_A, along_end_A = p[0], p[1]
        along_start_B, along_end_B = p[3], p[2]
    else:
        # Long edges are p1->p2 and p3->p0.
        along_start_A, along_end_A = p[1], p[2]
        along_start_B, along_end_B = p[0], p[3]

    return np.array([along_start_A, along_end_A, along_end_B, along_start_B],
                    dtype=np.float64)


def _box_corners(x1, y1, x2, y2) -> np.ndarray:
    """Axis-aligned box -> 4 corners as a rotated-rect-style ring (TL,TR,BR,BL)."""
    return np.array([[x1, y1], [x2, y1], [x2, y2], [x1, y2]], dtype=np.float64)


# ---------------------------------------------------------------------------
# SAM2-cadence cache: encode a neck quad RELATIVE to its YOLO box, then decode
# it onto a later box so we can skip SAM2 between runs (see detect_quad).
# ---------------------------------------------------------------------------
def _quad_to_box_rel(quad_px, box):
    """Express a full-frame neck quad in its YOLO box's local coords ([0..1] per
    axis, where 0 = box left/top, 1 = box right/bottom). Lets us reproject the
    same neck pose onto a moved/resized box without rerunning SAM2."""
    x1, y1, x2, y2 = box
    bw = max(x2 - x1, 1e-6)
    bh = max(y2 - y1, 1e-6)
    rel = np.array(quad_px, dtype=np.float64).copy()
    rel[:, 0] = (rel[:, 0] - x1) / bw
    rel[:, 1] = (rel[:, 1] - y1) / bh
    return rel


def _box_rel_to_quad(rel, box):
    """Inverse of _quad_to_box_rel: box-local neck quad -> full-frame px."""
    x1, y1, x2, y2 = box
    bw = x2 - x1
    bh = y2 - y1
    out = np.array(rel, dtype=np.float64).copy()
    out[:, 0] = out[:, 0] * bw + x1
    out[:, 1] = out[:, 1] * bh + y1
    return out


def _box_jumped(prev_box, new_box):
    """True if the YOLO box moved/resized enough that the cached relative neck
    geometry is no longer trustworthy (forces an early SAM2 re-run)."""
    if prev_box is None:
        return True
    px1, py1, px2, py2 = prev_box
    nx1, ny1, nx2, ny2 = new_box
    pcx, pcy = (px1 + px2) / 2, (py1 + py2) / 2
    ncx, ncy = (nx1 + nx2) / 2, (ny1 + ny2) / 2
    pw, ph = max(px2 - px1, 1e-6), max(py2 - py1, 1e-6)
    pdiag = float(np.hypot(pw, ph))
    move = float(np.hypot(ncx - pcx, ncy - pcy))
    if move > SAM_BOX_MOVE_FRAC * pdiag:
        return True
    nw, nh = max(nx2 - nx1, 1e-6), max(ny2 - ny1, 1e-6)
    sx, sy = nw / pw, nh / ph
    if not (SAM_BOX_SCALE_LO <= sx <= SAM_BOX_SCALE_HI):
        return True
    if not (SAM_BOX_SCALE_LO <= sy <= SAM_BOX_SCALE_HI):
        return True
    return False


# ---------------------------------------------------------------------------
# Temporal smoothing: align corners across frames, then EMA-blend so the
# emitted quad doesn't jitter (see _smooth_quad / detect_quad).
# ---------------------------------------------------------------------------
def _quad_centroid(quad):
    return np.array(quad, dtype=np.float64).mean(axis=0)


def _quad_area(quad):
    """Shoelace area of a 4-point ring (sign-agnostic)."""
    p = np.array(quad, dtype=np.float64)
    x, y = p[:, 0], p[:, 1]
    return 0.5 * abs(float(np.dot(x, np.roll(y, -1)) - np.dot(y, np.roll(x, -1))))


def _align_corners(new_quad, ref_quad):
    """Reorder new_quad's 4 corners to best match ref_quad's ordering.

    Our quads are a ring ordered along the neck's long axis, but which physical
    corner lands at index 0 can flip between frames (the long-axis ordering picks
    a start arbitrarily, and a near-180-deg neck flip swaps ends). Averaging
    mismatched corners would smear the quad. We try both ring rotations that
    preserve winding (offset 0 and 2) plus, for each, the reversed winding, and
    keep whichever permutation minimizes total corner distance to ref."""
    new = np.array(new_quad, dtype=np.float64)
    ref = np.array(ref_quad, dtype=np.float64)
    best, best_cost = new, float("inf")
    for rev in (new, new[::-1]):
        for off in range(4):
            cand = np.roll(rev, -off, axis=0)
            cost = float(np.sum((cand - ref) ** 2))
            if cost < best_cost:
                best_cost = cost
                best = cand
    return best


def _smooth_quad(new_quad, conf):
    """EMA-blend a freshly detected normalized quad into the last emitted one and
    return (smoothed_quad, smoothed_conf). Updates module state.

    - First detection (no history): emit as-is.
    - Corners are aligned to the previous quad before blending so we never average
      mismatched corners.
    - "Close" to last (centroid move < SMOOTH_MOVE_FRAC of the frame diagonal AND
      area ratio in [SMOOTH_AREA_LO, SMOOTH_AREA_HI]) -> heavy smoothing
      (SMOOTH_NEAR_BLEND on the new quad): kills frame-to-frame jitter.
    - "Far" (a real move / re-acquire) -> snap (SMOOTH_FAR_BLEND on the new quad).
    """
    global _LAST_EMIT_QUAD, _LAST_EMIT_CONF, _MISS_COUNT
    new = np.array(new_quad, dtype=np.float64)

    if _LAST_EMIT_QUAD is None:
        _LAST_EMIT_QUAD = new
        _LAST_EMIT_CONF = conf
        _MISS_COUNT = 0
        return new, conf

    last = _LAST_EMIT_QUAD
    aligned = _align_corners(new, last)

    # Closeness test in normalized coords (frame diagonal in [0..1] space = sqrt2).
    move = float(np.linalg.norm(_quad_centroid(aligned) - _quad_centroid(last)))
    a_last = _quad_area(last)
    a_new = _quad_area(aligned)
    area_ratio = (a_new / a_last) if a_last > 1e-9 else 999.0
    is_close = (move < SMOOTH_MOVE_FRAC * np.sqrt(2.0)
                and SMOOTH_AREA_LO <= area_ratio <= SMOOTH_AREA_HI)

    blend = SMOOTH_NEAR_BLEND if is_close else SMOOTH_FAR_BLEND
    smoothed = (1.0 - blend) * last + blend * aligned

    _LAST_EMIT_QUAD = smoothed
    _LAST_EMIT_CONF = conf
    _MISS_COUNT = 0
    return smoothed, conf


def _hold_or_null():
    """Called when a frame yields no detection. Re-emit the last smoothed quad
    with a decayed confidence for up to MISS_HOLD frames, then give up (None).
    Returns (quad_list, conf) to emit, or None to emit a null quad."""
    global _LAST_EMIT_CONF, _MISS_COUNT
    if _LAST_EMIT_QUAD is None or _MISS_COUNT >= MISS_HOLD:
        return None
    _MISS_COUNT += 1
    _LAST_EMIT_CONF *= MISS_CONF_DECAY
    return _LAST_EMIT_QUAD, _LAST_EMIT_CONF
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

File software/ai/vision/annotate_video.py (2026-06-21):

#!/usr/bin/env python3
"""Render an annotated demo video of the guitar-neck detector tracking a REAL
training capture over time.

We import fretboard_server (import-safe: its server only starts under
``if __name__ == "__main__"``), load the YOLO-World + SAM2 models ONCE via
``load_model()``, then walk a short segment of a training .webm. For each sampled
frame we call ``detect_quad(frame, smooth=True)`` — the same live-stream path the
WebSocket server uses (EMA smoothing across frames, SAM2 only every 4th frame,
hold-on-miss) — and draw the detected neck grid the way the product registration
overlay does:

  * the detected quad as a bright rotated rectangle,
  * 6 string lines interpolated across the quad's v-axis (top edge -> bottom edge),
  * 7 fret lines (frets 0..7) placed by the 12-TET law along the quad's u-axis
    (nut -> fret7): u_f = (1 - 2^(-f/12)) / (1 - 2^(-7/12)),
  * a small HUD: confidence + frame index + "tracking" / "searching".

On a miss (detect returns None) we draw "searching" and re-draw the last good quad
faintly so the overlay doesn't flicker to nothing.

The annotated frames are written to an mp4 at the sampled fps (cv2.VideoWriter with
mp4v/avc1; if that fails we fall back to PNG frames + ffmpeg). Output is downscaled
to <= ~1280px wide so the file stays small.

Usage:
    .venv-yolo/bin/python annotate_video.py \
        [--video PATH] [--start 5] [--dur 12] [--fps 9] [--max-width 1280] \
        [--out realtest/training_demo.mp4]
"""
import argparse
import os
import subprocess
import sys
import time

import cv2
import numpy as np

# Import the detector. This module is import-safe: it only starts the WS server
# under ``if __name__ == "__main__"``. We use its load + detect functions only.
HERE = os.path.dirname(os.path.abspath(__file__))
if HERE not in sys.path:
    sys.path.insert(0, HERE)
import fretboard_server as fb  # noqa: E402

DEFAULT_VIDEO = os.path.abspath(os.path.join(
    HERE, "..", "..", "..",
    ".claude", "worktrees", "analysis-pipeline", "data", "raw",
    "2026-06-21-0249", "aditya", "video", "chordstream_aditya_001.webm"))
DEFAULT_OUT = os.path.join(HERE, "realtest", "training_demo.mp4")
FFMPEG = "/opt/homebrew/bin/ffmpeg"

# --- Drawing palette (BGR) ---
QUAD_COLOR = (0, 255, 120)      # bright green: detected neck quad
STRING_COLOR = (255, 235, 90)   # cyan-ish: the 6 strings
FRET_COLOR = (60, 180, 255)     # orange: the 7 fret lines (12-TET)
NUT_COLOR = (80, 80, 255)       # red: nut (fret 0)
FRET7_COLOR = (255, 80, 255)    # magenta: fret 7
HOLD_COLOR = (120, 120, 120)    # faint grey: last quad while searching
HUD_GREEN = (80, 255, 120)
HUD_AMBER = (40, 200, 255)

N_STRINGS = 6
N_FRETS = 7  # draw fret lines 0..7 inclusive (nut..fret7), i.e. 8 lines


def fret_u(f: int) -> float:
    """12-TET position of fret f along the quad's nut->fret7 u-axis (0..1).

    u_f = (1 - 2^(-f/12)) / (1 - 2^(-7/12)) = fret_fraction(f) / fret_fraction(7).
    f=0 -> 0 (nut), f=7 -> 1 (fret 7).
    """
    return fb.fret_fraction(f) / fb.fret_fraction(N_FRETS)


def bilerp(quad_px, u, v):
    """Bilinear point inside the quad. Corner order is
    [0]=alongStart.top, [1]=alongEnd.top, [2]=alongEnd.bottom, [3]=alongStart.bottom.
    u runs nut(0)->fret7(1) along the top/bottom edges; v runs top(0)->bottom(1).
    """
    p0, p1, p2, p3 = (np.asarray(quad_px[i], np.float64) for i in range(4))
    top = p0 + (p1 - p0) * u      # along the top edge
    bot = p3 + (p2 - p3) * u      # along the bottom edge
    return top + (bot - top) * v


def draw_grid(img, quad_px, faint=False):
    """Draw the neck registration grid (quad + 6 strings + 8 fret lines)."""
    pts = np.asarray(quad_px, np.float64)
    if faint:
        # Just the quad outline, dim, so a searching frame still shows last pose.
        cv2.polylines(img, [pts.astype(np.int32).reshape(-1, 1, 2)],
                      isClosed=True, color=HOLD_COLOR, thickness=2,
                      lineType=cv2.LINE_AA)
        return

    # Fret lines 0..7 across the v-axis (top edge -> bottom edge), placed by 12-TET.
    for f in range(N_FRETS + 1):
        u = fret_u(f)
        a = bilerp(pts, u, 0.0)
        b = bilerp(pts, u, 1.0)
        if f == 0:
            col, th = NUT_COLOR, 3
        elif f == N_FRETS:
            col, th = FRET7_COLOR, 3
        else:
            col, th = FRET_COLOR, 2
        cv2.line(img, tuple(a.astype(int)), tuple(b.astype(int)), col, th,
                 lineType=cv2.LINE_AA)

    # 6 string lines across the u-axis (nut -> fret7), interpolated on the v-axis.
    for s in range(N_STRINGS):
        v = (s + 0.5) / N_STRINGS
        a = bilerp(pts, 0.0, v)
        b = bilerp(pts, 1.0, v)
        cv2.line(img, tuple(a.astype(int)), tuple(b.astype(int)), STRING_COLOR, 1,
                 lineType=cv2.LINE_AA)

    # The quad outline on top so it reads as the registration boundary.
    cv2.polylines(img, [pts.astype(np.int32).reshape(-1, 1, 2)], isClosed=True,
                  color=QUAD_COLOR, thickness=3, lineType=cv2.LINE_AA)
    # Corner dots (nut end emphasized).
    for i, (x, y) in enumerate(quad_px):
        cv2.circle(img, (int(x), int(y)), 5, (40, 40, 230), -1, lineType=cv2.LINE_AA)


def draw_hud(img, frame_idx, conf, tracking, fresh, n_frets_payload):
    """Top-left HUD: state, confidence, frame index."""
    h, w = img.shape[:2]
    state = "tracking" if tracking else "searching"
    col = HUD_GREEN if tracking else HUD_AMBER
    # translucent backdrop
    bar_h = 64
    overlay = img.copy()
    cv2.rectangle(overlay, (0, 0), (w, bar_h), (0, 0, 0), -1)
    cv2.addWeighted(overlay, 0.45, img, 0.55, 0, img)

    dot = (0, 230, 90) if tracking else (40, 200, 255)
    cv2.circle(img, (24, 32), 9, dot, -1, lineType=cv2.LINE_AA)
    txt = f"{state.upper()}   conf={conf:0.2f}   frame {frame_idx}"
    if tracking and not fresh:
        txt += "  (hold)"
    if n_frets_payload:
        txt += f"   frets:{n_frets_payload}"
    cv2.putText(img, txt, (44, 42), cv2.FONT_HERSHEY_SIMPLEX, 0.85, col, 2,
                lineType=cv2.LINE_AA)


def open_writer(out_path, fps, size):
    """Try cv2.VideoWriter with a couple of codecs; return (writer, fourcc) or
    (None, None) if none open (caller then falls back to ffmpeg-from-PNGs)."""
    w, h = size
    for tag in ("avc1", "mp4v"):
        fourcc = cv2.VideoWriter_fourcc(*tag)
        vw = cv2.VideoWriter(out_path, fourcc, fps, (w, h))
        if vw.isOpened():
            print(f"[writer] cv2.VideoWriter opened with fourcc={tag}", flush=True)
            return vw, tag
        vw.release()
    print("[writer] cv2.VideoWriter could not open any codec; will use ffmpeg",
          flush=True)
    return None, None
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

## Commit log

2026-06-20 Planning and design docs reconciled to truth.md
    Single source of truth (truth.md) with granular parts ledger (SKU, dimensions, cost, use).
    Removed 18 legacy old-architecture docs (Pi5/ESP32/MAX98357A/Dayton-exciter, 16/14-ch, 3-pillar/score-era). All surviving docs corrected to the as-built rig: laptop brain, 12 channels (6 chest + 6 forearm), 6x SK473 PAM8403 amps, 12x KHD 3ohm drivers, browser/Python WebSocket split, LEARN+PLAY scope.
    Claude-Session: https://claude.ai/code/session_011mbTF7Dg2DFZpD5cX7ffzy
2026-06-20 Implementation: CAD print package, 12-channel config, software + web scaffold
    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
    [actuator_button.stl, actuator_cup.stl, actuator_puck.scad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]
2026-06-20 Lock canonical audio input: Sony ECM-LV1 clip-in mic -> Vantec V2 mic-in
    truth.md (3.8 Sensing + parts ledger 4 + open items 8) and docs/23: the ECM-LV1
    (3.5mm TRS electret, plug-in power) clips inside the guitar body and plugs into a
    Vantec Mic jack (V2; V3 spare), captured mono via the CM6206's plug-in power.
    Verified compatible at spec level; confirm input level in Stage-1. Same mic for
    training and inference (no train/serve skew). Fixes the noisy-venue feedback issue.
    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
2026-06-20 Wire the as-bought mic into truth: Saramonic LavMicro-U (USB-C digital lav)
    Replaces the Sony ECM-LV1/Vantec-mic-in plan with the mic actually purchased.
    truth.md (rig diagram AUDIO IN, 3.8 Sensing, parts ledger 4, open items 8) + docs/23:
    - Saramonic LavMicro-U: wired digital USB-C lavalier, omni condenser, 30 Hz-20 kHz,
    16/24-bit @ 44.1/48 kHz, multibit Delta-Sigma ADC, 0-35 dB gain, 2 m USB-C cable
    + USB-A adapter; ~$30 Best Buy.
    - Connects plug-and-play straight into a Mac USB port as its OWN input device (own ADC) -
    no Vantec mic-in, no plug-in-power dependency, no adapter. Vantecs stay output-only; V3 spare.
    - Open mic input + Vantec output as independent streams (no macOS aggreg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
2026-06-21 Data collection protocol (docs/24) + front-cam update
    Office-hours decisions locked: single-note-dominant; collapse regions =
    {clean, buzz-too-light, buzz-placement} per string (muted/choked = cheap external
    flags); balanced + natural-ratio holdout; PROMPTED RUNS + arpeggiated chords +
    interval audit; camera = MacBook front cam (train/serve match).
    docs/24 = execution-ready capture protocol (rig, run-based capture, 6x6 grid +
    arpeggiated chords, metadata schema, file convention, what-I-need checklist,
    the pipeline + interval-audit dashboard). truth.md 3.8 updated to the front cam.
    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
2026-06-21 docs/24: add align mode (capture+inference), pose-variation passes, data targets
    Camera-angle robustness: align mode reads ArUco size/pose + brightness to match
    camera distance/angle/lighting between capture and inference (train=serve by
    construction); homography + offline augmentation handle residual drift. Stage-1
    pose-variation passes for occlusion generalization. Data targets: ~300 to prove
    thesis, ~800-1000 solid v1 (1.5-2 hr), stop when held-out d-prime plateaus + grid covered.
    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
2026-06-21 Refine CAD enclosure, docs, diagrams, and channel config
    - cad: add tactus_enclosure.py with base/lid/plate STLs, FF5M gcode,
    verify/render helper scripts, and preview/render images; resize
    actuator puck/cup/button; update chest plate and node mount
    - diagrams: rename body-encoding-map -> body-map and wiring-channel-map
    -> connections; refresh power-modes and system-flow
    - config: update channel_map.json
    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
    [actuator_button.stl, actuator_cup.stl, actuator_puck.scad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]
2026-06-21 Add graphify knowledge graph and enclosure 3MF exports
    - graphify-out/: refreshed knowledge graph (395 nodes, 535 edges,
    23 communities) covering CAD, docs, config, and software; includes
    graph.json, graph.html, GRAPH_REPORT.md, extraction cache, manifest
    - cad: add base/plate 3MF print exports alongside existing STLs
    - gitignore: ignore graphify machine-specific path pointers
    (.graphify_python, .graphify_root)
    [tactus_enclosure_base.3mf, tactus_enclosure_plate.3mf]
2026-06-21 docs/24: lock frets 1–6 scope, last-mile↔data framing, app-conducted capture + Day-1 recorder (#1)
2026-06-21 vision: markerless fretboard registration + guitar digital twin + framing guide
    - fretboard.py: markerless homography from the 12-TET fret law (the guitar is
    its own ruler); validate by reprojecting frets onto real wires. Synthetic
    self-test ~1.3px. Demotes the taped ArUco to an optional validation rig.
    - calib_serve.py + calibrate.html: localhost digital-twin capture; click 4 neck
    corners, fret grid overlays live so you see it snap onto your frets (paperless).
    - twin.py: builds twin.json (fret-law intrinsics + per-pose homography + residual).
    - capture.html: on-screen framing guide + pose-variation block now prompts the
    finger/wrist/neck-angle change per pass (pose_variant).
    - cad/a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
    [calib_serve.py, fretboard.py, twin.py]
2026-06-21 capture: encode full start-to-finish steps in the localhost UI
    On-page guide in capture.html (twin -> record -> 4 rules -> handoff) so the
    operator never memorizes the protocol; calibrate.html labeled Step 1 of 2 and
    points to the recorder. Roommate can pull main and follow it on screen.
2026-06-21 docs/26 handoff + repo-wide markerless registration reconciliation
    - Add docs/26-aiden-handoff.md: offline-pipeline handoff for Aiden — exact
    data/raw + data/calib layout, authoritative full manifest schema + real
    example row, the 6 processing gotchas (-> docs/25), build order, iron rules.
    Cross-linked from docs/25.
    - Reconcile ArUco -> MARKERLESS as the primary registration across the canonical
    and active-path docs (the 12-TET fret-law is the guitar's own ruler;
    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
2026-06-21 analysis: offline pipeline scaffold (segment->features->PCA/LDA->d'/confusion->one-screen audit)
    Parked for the analysis owner (Aden). All 6 stages tested green on synthetic data;
    consumes the capture manifest + data/calib twin.json. Not on the data-collection
    critical path.
2026-06-21 Wire alphaTab real tab into live fret-glow; tune strum pop
    glow.html now renders real guitar tab (alphaTab / alphaTex) in the left
    panel from a single SONG source that ALSO generates the on-neck glow
    chart, so the scrolling tab and the glow stay in lockstep. Song is a
    G-Em-C-D (I-vi-IV-V) open-chord etude (frets 0-3). Render-only, no
    synth/soundfont -- correct for the Deaf-accessibility focus; a master
    seconds clock scrolls the tab under a fixed gold playhead and drives the
    glow envelopes. Falls back to a chord-row list if the CDN is blocked.
    Also: tune the strum pop to a small ~1.9x expansion with a thickening
    ring (was a 2.8x blast that thinned to nothing); add the web/ AR
    prototypes (glo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
2026-06-21 framing: whole-guitar capture (1080p) + offline ROI crop
    Operator constraint: tight nut->fret-7 framing forced a camera angle too low to
    see the screen. Resolved by capturing the WHOLE guitar full-screen (also what
    the live AR demo + train/serve match want) at 1080p, and cropping to the
    fretboard ROI offline before MediaPipe so d resolution is preserved. Whole-neck
    view also strengthens markerless registration (more fret wires + inlays).
    Frets 1-6 remain the only rendered/coached scope.
    - capture.html + calibrate.html: request 1080p; framing guide -> whole-guitar.
    - docs/25 6d (capture-wide-process-cropped) + 7 + build order; docs/26 ROI crop;
    truth.md 3.8 framing clause; CHANGELOG.
2026-06-21 capture: switch taxonomy to clean/buzz/muted; full-screen calib camera
    3 acoustically-distinct classes (good / buzz / dead) replace the audio-ambiguous
    buzz-light vs buzz-placement split. muted prompts an unambiguous dead note.
    capture.html (recorder UI + run-plan + on-page guide) and record_conductor.py
    (terminal fallback) updated. calibrate.html: camera fills the viewport for
    whole-guitar framing; 4-corner click->image mapping kept exact.
2026-06-21 capture: unify calib + record on one server/port (8765)
    serve.py now serves the calibrate page at /calibrate and writes keyframes via
    /calib-save -> data/calib; /ping added. capture.html <-> calibrate.html cross-link
    (top-bar: '① Map guitar' / '→ Record ②'). One command, one localhost; calib_serve.py
    still works standalone but is no longer needed.
2026-06-21 capture+calib: live resolution + audio-quality pills (green=MacBook spec)
    Both pages show camera resolution; capture page also shows audio sample-rate +
    lossless state. Green pill = at spec (video >=1080p, audio lossless wav >=44.1k),
    red = inferior. Bumped record-page video request 720p -> 1080p to match.
2026-06-21 capture: loud per-run / per-keyframe terminal confirmation
    serve.py prints a clear '✓ RUN #N SAVED' block on every recorded run (class,
    string, frets, files, peak dBFS, CLIPPED/SILENT warning, running session total)
    and '✓ KEYFRAME #N SAVED' on each calib capture. Confirms processing at a glance.
2026-06-21 capture: terminal shows VIDEO + AUDIO resolution per run/keyframe
    Each saved run prints VIDEO (WxH@fps, ✓1080p / ⚠below) and AUDIO (sample-rate +
    format, ✓lossless / ⚠not) lines, pulled from the actual saved metadata; calib
    keyframes print their resolution too. Terminal = source of truth for capture specs.
2026-06-21 vision: automatic markerless fretboard detection with confidence gate + click fallback
    fretboard_detect.py — detect neck edges + fret wires (classical front-end,
    swappable for a YOLOv8-OBB / Roboflow model) → fit the 12-TET fret-law
    homography → SELF-VERIFY by reprojection → auto-lock when residual is low, else
    fall back to the existing 4-click. Heeds the prior-art finding that pure auto
    classical detection is lighting/angle-fragile, so the gate + fallback ARE the
    design. Offline + multi-frame aggregation makes the one-per-session registration
    robust. Fit+gate validated synthetically (clean->auto 1.3px, noisy->click);
    detection thresholds tune on the first real frame via the CLI.
    [fretboard_detect.py]
2026-06-21 capture: enlarge live video on record page (wider layout + 82vh cap)
    Record page now uses a wider grid (1.7fr/.8fr, max-width 1850) and the preview
    grows to 82vh, so the guitar neck is big enough to align well. CSS-only; recording
    flow unchanged.
2026-06-21 capture: chord block shows per-string frets, clean+buzz, repeated arpeggios
    Arpeggio/strum block now uses real open-chord shapes (CHORD_SHAPES): prompt shows
    the chord + per-string fret map; run carries frets[]/strings_played[] (low->high
    pick order) = per-note position ground truth even on buzz chords. 2 clean : 1 buzz
    per chord; plays the chord REPS=6x to the beat (one arpeggio/strum per beat) for
    volume. Metronome shows arpeggio count for chords, FRET 1-6 for single-finger.
2026-06-21 haptic: 12-speaker one-by-one resonance walk (Enter=next, R=repeat)
    Adds resonance_check.py: a dedicated bring-up interface that steps every one
    of the 12 logical actuators across BOTH Vantecs (V1 ch1-8, V2 ch9-12), one
    speaker at a time, playing a LOW/LOUD tone so you feel each driver resonate.
    Not 8-on-one-jack -- the full 12.
    [Enter] next r/R repeat current speaker q/Esc quit (single keypress)
    default : steady 80 Hz, amp 0.8, 1.5s (low + loud)
    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
2026-06-21 capture: show finger (i/m/r/p) per chord string + store fingers_played
    Chord prompt now shows fret AND fingering (e.g. A:2(m) D:2(r) B:1(i)); run carries
    fingers_played[]/chord_fingers[] alongside frets/strings_played for the position
    model. Variable string count per chord already honored (sounded strings only).
2026-06-21 capture: per-string fault chord block (granular good/buzz/muted ground truth)
    New block 'chord-fault': arpeggiate a chord but fault ONE known string (buzz or
    mute), rest clean. Stores per-onset string_classes[] + fault_string/fault_type
    alongside strings_played[]/frets[]/fingers_played[] -> per-string quality ground
    truth in chord/occlusion context. Enables per-string chord feedback downstream.
2026-06-21 capture: continuous chord-stream block + live fretboard diagram
    New block 'chord-stream': ONE recording streams ~100 shuffled chords (advance every
    2 beats), shows each chord on an SVG fretboard diagram (dots+finger numbers, o/x),
    prompts a pose change every 10 chords, logs per-chord cue_ms -> chord_sequence in
    one batch manifest row. Built for the vision/occlusion model (chord = position
    label; beat raw MediaPipe). Diagram also shown for arpeggio/fault chord runs.
2026-06-21 graphify: refresh knowledge graph for consolidated main
    Full re-extraction (AST + semantic) against current main (4fa7e1b):
    730 nodes / 1221 edges / 49 communities. Now reflects docs/27,
    reconciled truth.md, the analysis pipeline, and haptics; replaces
    stale pre-merge graph. Regenerated graph.html, graph.json, report.
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2026-06-21 web: Sherbet theme + markerless camera auto-lock for the LEARN UI
    Turn glow.html into a fully automatic AR view in the Sherbet theme:
    - Camera is ALWAYS ON (auto-start + retry, no off switch) and is the stage background.
    - The grid auto-locks MARKERLESS: web/fretboard-autodetect.js (OpenCV.js) ports the
    fret-law homography from software/ai/vision/fretboard_detect.py, finds the fretboard's
    4 corners on the live feed, and snaps the grid onto the real neck — no manual
    calibration. The 12-TET law lays the frets inside the detected quad; corners are
    exponentially smoothed so the HUD tracks the guitar. Falls back to a centered default
    HUD until it locks, so the page never breaks.
    - Rem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
2026-06-21 analysis: clean/buzz/muted + mono->poly transfer + Redis memory (methods, results, viz)
    Offline-analysis phase results (docs/28). One player (aditya), one guitar, MacBook
    webcam + lav mic. Held-out, base-rate, fit-on-train-only.
    Foundation
    - segment.py over-fire fix: pin onsets to manifest cue_ms (chords) / expected_note_count
    (single notes) -> 432 single-note + 600 chord events, exact per-run counts.
    - Session-scoped event_id (chord run_ids repeat across sessions; was corrupting merges).
    - schema: chord labels + G 4-finger correction [3,2,0,0,3,3]; features_residual.py (E3);
    extract_vision.py (mediapipe in a Py3.11 venv -> CSV; 0.10.21 pin).
    Results (leakage-checked GroupKFold-by-run)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
    [beat_baseline_table.csv, e7_perfinger_predictions.csv, e7b_register_per_frame.csv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]
2026-06-21 web: fix AR mapping — MediaPipe hand auto-anchor + manual drag fallback
    The OpenCV/Hough markerless detector (fretboard-autodetect.js) was CONFIRMED to fail on
    real busy backgrounds: curtains + sponsor banners have longer/straighter lines than the
    thin diagonal guitar neck, so it found ZERO neck edges (status stuck on "finding the
    neck"). Diagnosed via an on-screen debug overlay — no neck lines detected at all.
    Replace the registration approach in glow.html:
    - AUTO (default): web/hand-anchor.js uses MediaPipe Hands to anchor the grid to the
    fretting hand — robust to busy backgrounds (truth.md §2's intended browser vision).
    Placement is approximate.
    - MANUAL fallback: re-added the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
2026-06-21 web+vision: auto AR via a learned YOLO-World + SAM2 neck detector backend
    Two markerless auto attempts failed on a busy hackathon background: OpenCV/Hough found
    zero neck edges; MediaPipe hand-anchor gave a degenerate quad (a hand alone can't
    determine the fretboard). Research (TapToTab et al.) converges on trained detection over
    classical CV. With the M4 Pro + permission to run heavy local models, pivot to a learned
    detector.
    - software/ai/vision/fretboard_server.py: Ultralytics YOLO-World (open-vocab "guitar"
    detect, zero training) -> SAM2 mask -> distance-transform NECK isolation (separates the
    thin fretboard from the round body) -> 4-corner neck quad, on the M4 Pro GPU (MPS),
    stre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
    [fretboard_server.py]
2026-06-21 vision: anchor the neck grid to the fretboard's top edge (stable 2D rotated rect)
    User insight: the fretboard's top long edge (the binding above the low-E string) is the
    strongest anchor, and the pose is 2D in-plane tilt only — no yaw/perspective/shear. So fit
    the grid's rotation to that edge and emit a true rotated RECTANGLE.
    - fretboard_server.py: replace minAreaRect-of-the-whole-band with a top-edge-anchored rect.
    Huber line-fit on the neck mask's top long side (low-E binding) -> rotation; the bottom
    edge is built PARALLEL (constant-width offset) -> exact rectangle, zero shear/perspective
    (2D tilt + scale only). Verified on both test images: rotation within ~1-1.5deg of ground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
    [fretboard_server.py]
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2026-06-21 fix(web): emit events-wrapped tactus-tab/v1 so the haptic tab_player accepts LEARN tabs
    LEARN output (web/tabs/*.json) used a flat top-level `notes` array, but software/haptic/tab_player.py load_tab() requires an `events` array (tactus-tab/v1) and rejects flat tabs. Both sides claimed tactus-tab/v1 with different shapes.
    - riptide.json: 6 chord events (Am/G/C x2) with strum_ms.
    - twinkle.json: 42 single-note events.
    - glow.html: buildFromTab reads tab.events (chord = one event, glows as a group), flat-notes fallback kept for legacy tabs; NEXT_T event-indexed; DEFAULT_TAB -> events.
    Validated: tab_player --print loads both; 11/11 encoder + 15/15 player tests; --simulate end-to-end (real Hap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
2026-06-21 docs(vision): fix stale WebSocket port 8770->8772 in fretboard README + run comment
    The neck-detector WS moved to 127.0.0.1:8772 (fretboard_server.py:67 WS_PORT; sharingd holds a dual-stack :8770), and web/glow.html already consumes 8772 — but README-fretboard.md (URL/port + JS sketch) and the module run-comment still said localhost:8770. Align docs to the code. Found during an end-to-end verification pass (vision self-test PASS: guitar conf=0.818, 7-fret fit).
    [fretboard_server.py]
